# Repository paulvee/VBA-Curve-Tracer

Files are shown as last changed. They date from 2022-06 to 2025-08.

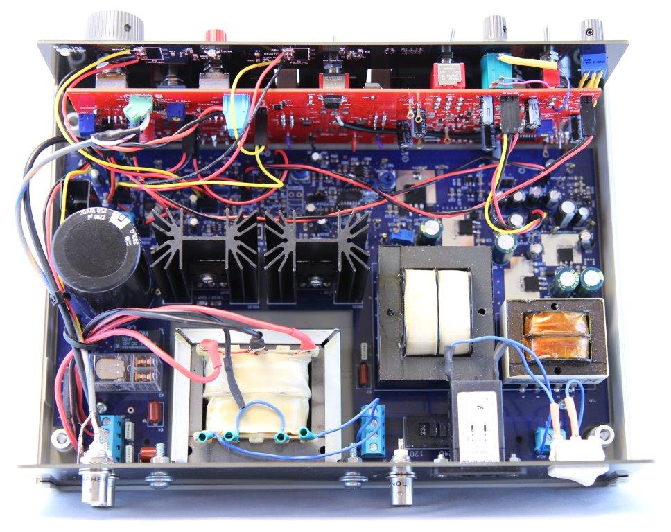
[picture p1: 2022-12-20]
Above from Back.jpg

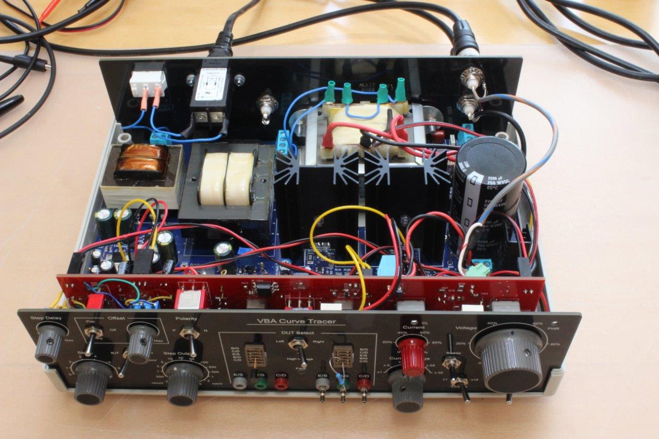
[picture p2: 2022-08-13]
Complete Unit(small).jpg

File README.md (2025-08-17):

# VBA Curve Tracer

Note:
When you order boards, make sure you select the black color for the Face Plate and the Back plate, otherwise you will get the default color and that may be green.
Read the important item below about ordering PCB's.

IMPORTANT:
Read the installation instructions for the Front board and the Main board carefully before installing parts.
 
As some of you may know already, designing something is bliss, manufacturing is hell. Especially after some time because things have a habit of changing.
Keep an eye out to newer revision numbers of the BOM's. I have added the partnumbers other users recommended because we either made a mistake in the ordernumber, or the part is no longer available. These alternatives are listed as suggestions. We cannot keep track of this ourselves but appreciate it if you can point out where there are partnumber issues so others can benefit.

Maker Matt Web and maker Cory Lytle have spend a lot of time correcting BOM partnumber errors and installation instructions. Thank you Matt & Cory!

Based on a suggestion from Cory, we have made a small change to the silkscreen of the Front Panel to make the Y-amplifier gain setting more obvious. This is reflected in file FrontPanelRev2b-Display.png.
It replaces the original one, bit since it's only this small change, I left all the other information intact. When you use the Gerber information, it has the change.

---------------------------------------------------------------------------------------------------

This is a repository to hold all files related to the VBA Curve Tracer project. With this information you can build one yourself.
Note that newer versions of files will overwrite the existing ones, there will be no version control. Look at the upload dates for more information.

---------------------------------------------------------------------------------------------------
Here is a note about issues that may come up when you're ordering boards.
Note that we have not heard about unresolved issues when you order through PCBWay. (look at the shared projects on their site and search for VBA to get access to all four boards)
The response below was a result of questions by the engineers of JLCPCB: (more info can be found in the Comment section of the Blog)

Mark, who was the EDA specialist in our team, designed the schematics and the PCB layouts. He used Altium, because his University has a full license.
He is the sole keeper of the EDA information.

This is what Mark replied to the issue:
I went back to look at the gerber files as they were distributed. At that time I was putting the board outline on every gerber plot. The Keepout layer was used for the cutouts in the inner parts of the board not the board outline or to keep copper out of certain areas of the board which is the intended use of this layer. This never has a use as a gerber file unless you are faking the keepout layer as a board outline layer. There is a keepout layer for the front panel PCB since it has the two rectangular connectors on it for holding the DUTs. Some manufacturers use the keepout layer to indicate internal holes. This is not the intended use of the layer either. I have encountered several different uses of the various gerber layers. You have to decide with the board manufacturer what they want to use as the board outline correctly or incorrectly. At the time when I made 10 systems, PCBWAY was allowing the board outline to be on all layers and not the keepout layer. I have had discussions more recently with PCBWAY. Among other things I got complaints about line thickness used for the lines depicting the board outline. So I decided to use the more industry standard of the .GM board outline gerber file. It uses 0 thickness lines for the board outline. Altium has this built into the design package so it was fairly easy to do. I no longer give a keepout layer unless there are internal "holes" on the PCB and that is how they want it indicated. In the description file I send with every PCB order I tell them exactly what the keepout layer is showing. I don't give it when there are no holes. The GM layer could also show the internal holes but I haven't needed to have any newer PCBs manufactured with them. Unfortunately I also get asked about the keepout layer when it is included on a board where the copper is supposed to be kept out. (This is the correct use of this layer). So no more keepout layer to the board manufacturer. The keepout layer is used by the PCB program to keep copper off a layer in a certain region. The gerber files never need to know this as the copper layer file will not have the copper in those regions already. So after all that verbal diarrhea can you tell me what they really want to indicate what the PCB outlines are. If they insist on using the incorrect keepout layer than I can send you some. If they will use the correct GM layer than I will send you some. The gerber layers JLPCB has, all have board outlines on every gerber layer. If you want to come up with a scheme that works for them, you need to let me know what it is and I will make that layer for you. I assume since the keepout layer was included on the front panel you don't need that one as long as JLPCB knows it isn't a board outline but the outline plus internal cutouts. You can create an issue on this Github site, add it as a comment on the Blog, or send the info directly via email if you prefer that. allie@wisc.edu.

--------------------------------------------------------------------------------------------------
There are four different Blogs that I created for this project.
The original posting with a description of the Theory of Operation for the CT and the building of my first version, a working prototype.

http://www.paulvdiyblogs.net/2017/12/building-curve-tracer.html

A few years later, a PCB layout has been developed using mostly SMD parts by Mark Allie. The Blog that covers the Version 2 can be found here:

http://www.paulvdiyblogs.net/2021/03/building-curve-tracer-v2.html

Some of the development process of the VBA Curve Tracer (Version 3) with the help from Mark Allie and Bud Bennet can be found here:

http://www.paulvdiyblogs.net/2021/03/building-curve-tracer-version-3.html

The information about the final instrument for a DIY build can be found here:

https://www.paulvdiyblogs.net/2022/06/the-vba-curve-tracer.html

I also created a blog post with several measurements that were made with the VBA Curve Tracer.

https://www.paulvdiyblogs.net/2021/11/making-meassurements-with-v3-curve.html

Enjoy!

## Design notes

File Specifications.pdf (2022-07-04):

## VBA Curve Tracer Specifications

DUT Voltages and Currents

There are three main voltage ranges that can be selected.

- 0-35V @ 0-2A
- 0-70V @ 0-1A
- 0-200V @ 0-100mA

The voltages and the currents of any of these ranges can be adjusted from 0-100% of the maximum values with full load. The voltage output can be selected between a triangle-based waveform, which is the default, and DC for leakage measurements. Selecting the DC mode will automatically change the maximum current in the X1 Current range setting to 50% to reduce the thermals.

The frequency of the triangle-based waveform is set at about 160Hz but can be tuned by changing a trimmer inside the unit. It can range from about 140Hz to 650Hz and can be used to tune the rate of flicker on the display of the oscilloscope.

An indicator will warn the user when voltages higher than approx. 40V are present on the DUT output terminals.

There are 6 current ranges to set the maximum currents for the DUT in the three voltage modes:

- x 1 (changes to x0.5 in the DC mode)
- x 0.5
- x 0.2
- x 0.1
- x 0.05
- x 0.02

This means that in the 35V @ 2A range, the maximum current can bet set to 2A, 1A, 400mA, 200mA, 100mA and 40mA. A Current adjustment can be used to further set the maximum current from 0-100% in any of the selected Current Ranges.

An LED will signal the current limiting (CL) mode, i.e. when the current to the DUT meets or is exceeding the set current by the Current Range and the Current setting.

Step Generator

The Step Generator feeds the Base or Gate of the DUT and can be set to output a current for BJT devices or a voltage for FET devices.

The Step Generator output can be set to generate 0-7 steps in a cycle.

A Step Delay can be selected to delay the time between complete step cycles to reduce the thermals developing in the DUT and prevent it from over-heating. When activated, the delay is approx. 40mSec between step cycles and can be increased to more than 250mS. The step cycle delay can be set with step cycles of 1 to 7 steps.

The output of the Step Generator can be selected in a 1-2-5 sequence.

The selections are:

- 5V*) or 5mA
- 2V or 2mA
- 1V or 1mA
- 500mV or 500uA
- 200mV or 200uA
- 100mV or 100uA
- 50mV or 50uA
- 20mV or 20uA
- 10mV or 10uA
- 5mV or 5uA
- 2mV or 1uA
- 1mV or 1uA
- 500uV or 500nA
- 200uV or 200nA
- 100uV or 100nA
- 50uV or 50nA

*) Note that in the 5V range, you will have to reduce the number of steps to avoid clipping against the supply rail of the step amplifier (approx. +/-14V). This can also happen with 1V and 2V step sizes in combination with the offset feature. The current settings do not clip.

A switch on the front panel selects the DUT type, which can be BJT or FET. This switches the output of the step generator to produce either a current for BJT's or volts for FET's.

An offset can be selected with either a positive (aid) or negative (oppose) offset to the Step output. The offset range has a maximum range of +/- 7V for BJT's at 100mA/Step and +/- 2V for FET's regardless of the V/Step setting. The maximum offset range for BJT's lowers with lower mA/Step settings so the user will need to readjust the offset level (Bias) when you change the Base current. In the FET mode, the offset (VGS) and the range stay constant with different V/Step settings. By changing three resistor values, the maximum offset for FET's can be set to +/-3, 4, 5 and 7.5V.

Both the current and the voltage outputs are corrected for DUT junction voltage drops and other current/voltage drops so composite devices (Darlington) can be tested without influencing the Base or Gate step settings.

The Step Gen output is protected against damages by high voltages in case of a shorted/damaged C-B or D-G junction or an accidental shorting of the Base or Gate to the DUT supply, that can be as high as 200V. A Fault LED will warn the user of this condition as long as it is present and the voltage at the Collector/Drain output will be removed for the duration of the fault condition.

A switch determines the polarity of the DUT for PNP/P-channel or NPN/N-channel type devices in such a way that the origin of the I/V curves on the DSO will always start in the lower left-hand corner of the oscilloscope.

Device Under Test (DUT)

A large variation of DUT's can be connected to the Curve Tracer by means of test sockets or 2mm Banana sockets. Two DUT's can be compared by means of a DUT selector switch that can be off or power the left or the right DUT socket to make comparisons and matching of devices possible.

Many different 2 or 3-pin DUT's can be measured or characterized with the instrument.

Display Device

An analog (CRT) or digital oscilloscope (DSO) is used in the X-Y display mode to show the I/V curves of the DUT. There are two BNC sockets available on the back panel of the instrument to connect the X and Y outputs to the input channels of the scope. An optional Z or blanking signal can be made available through a BNC connector on the back panel for analog oscilloscopes.

A multiplier for the measured DUT current can be used to select between x1 and x10 to amplify small DUT currents on the scope and raise the signal above noise levels.

Enclosure, Electrical & Mechanical Information

A mains switch is available on the back of the unit. An indicator on the Face Plate will show that the instrument is powered on.

The overall current consumption of the instrument in the idle mode is 0,25A and 12.5W with a 230V main supply. With the maximum DUT load of 35V @ 2A, the consumption is 340mA and 53W.

The instrument can be used with 115V @ 60Hz or 220-240V @ 50Hz mains voltages by means of a selector switch inside the unit. The mains connection is through an IEC C-7 type connector (also known as a figure 8) with EMI filter, has a fuse and a main power switch on the back panel. The instrument circuits itself are floating from earth ground but will be earth grounded through the BNC connections to the earth grounded oscilloscope.

The plastic enclosure measures 25cm x 18cm x 8cm. The Front and Back panels are shielded printed circuit boards with a black background and white lettering.

The overall weight is 2.5Kg.

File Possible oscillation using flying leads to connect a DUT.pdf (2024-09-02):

## Possible oscillation using flying leads to connect a DUT

Maker Matt Webb noticed oscillations of the triangle waveform during the current limiting phase when using flying leads in combination with the 2mm banana jacks.

It turns out that although the Curve Tracer itself is inherently clean from oscillation, adding flying leads will add induction and that can cause issues, especially with higher currents during the current limiting phase.

The remedy is to use leads that are as short as possible, and/or shielded.

The oscillation can also be countered by adding a donut shaped ferrite bead on the Collector/Drain connection lead. The ferrite beads that Matt experimented with is listed in the OffPCBPartsBOM.

Here are some pictures that Matt made with a TO3 2N3055 power transistor to illustrate the problem.

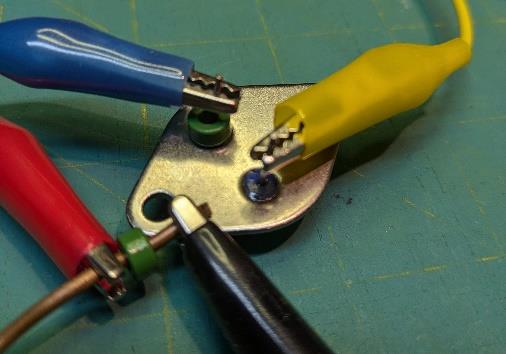
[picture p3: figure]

The leads he used for this measurement have a length of 13cm (5inch).

Without any additional beads, the triangle waveform looked as follows:

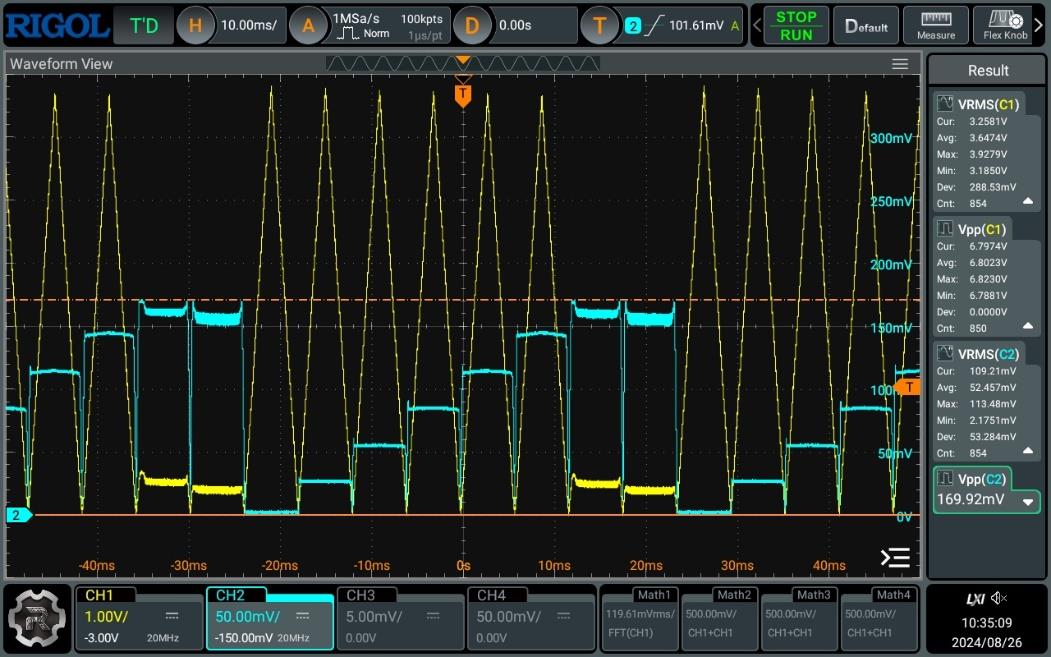
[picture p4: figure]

Note that there is some hash on the current limited excursions of the Collector current in the two highest steps.

With one additional bead placed directly on the Collector connection, the hash goes away.

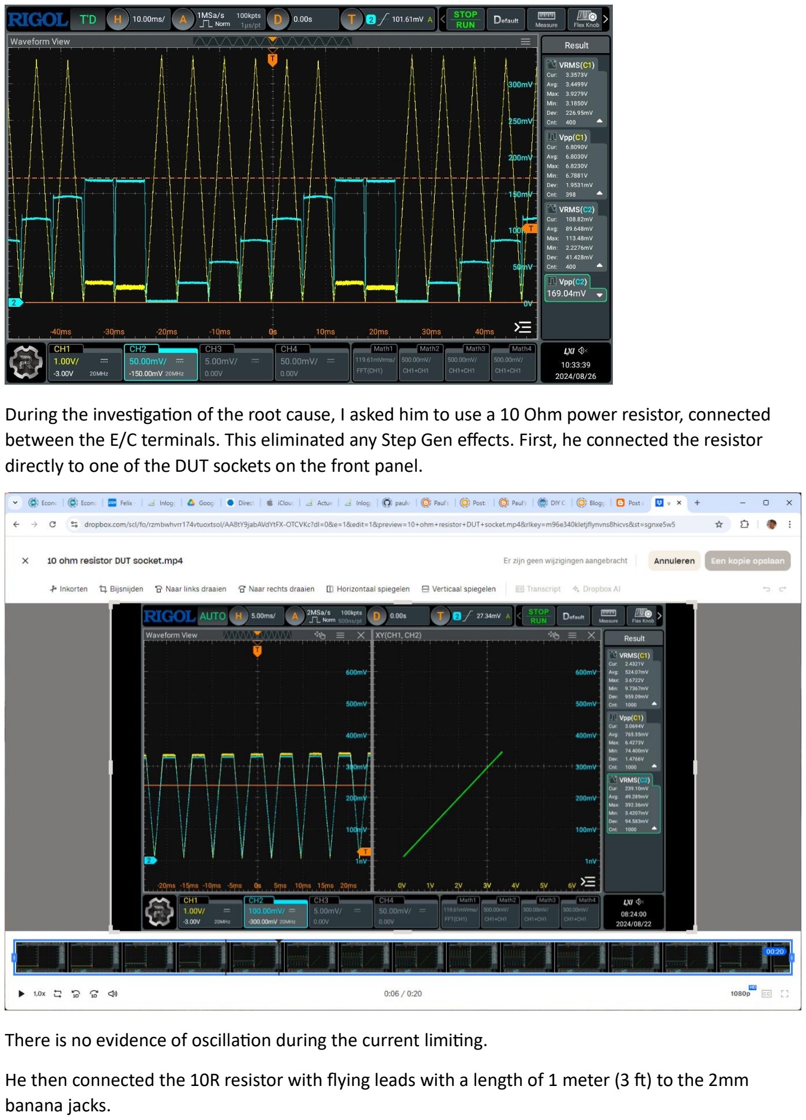
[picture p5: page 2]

During the investigation of the root cause, I asked him to use a 10 Ohm power resistor, connected between the E/C terminals. This eliminated any Step Gen effects. First, he connected the resistor directly to one of the DUT sockets on the front panel.

There is no evidence of oscillation during the current limiting.

He then connected the 10R resistor with flying leads with a length of 1 meter (3 ft) to the 2mm banana jacks.

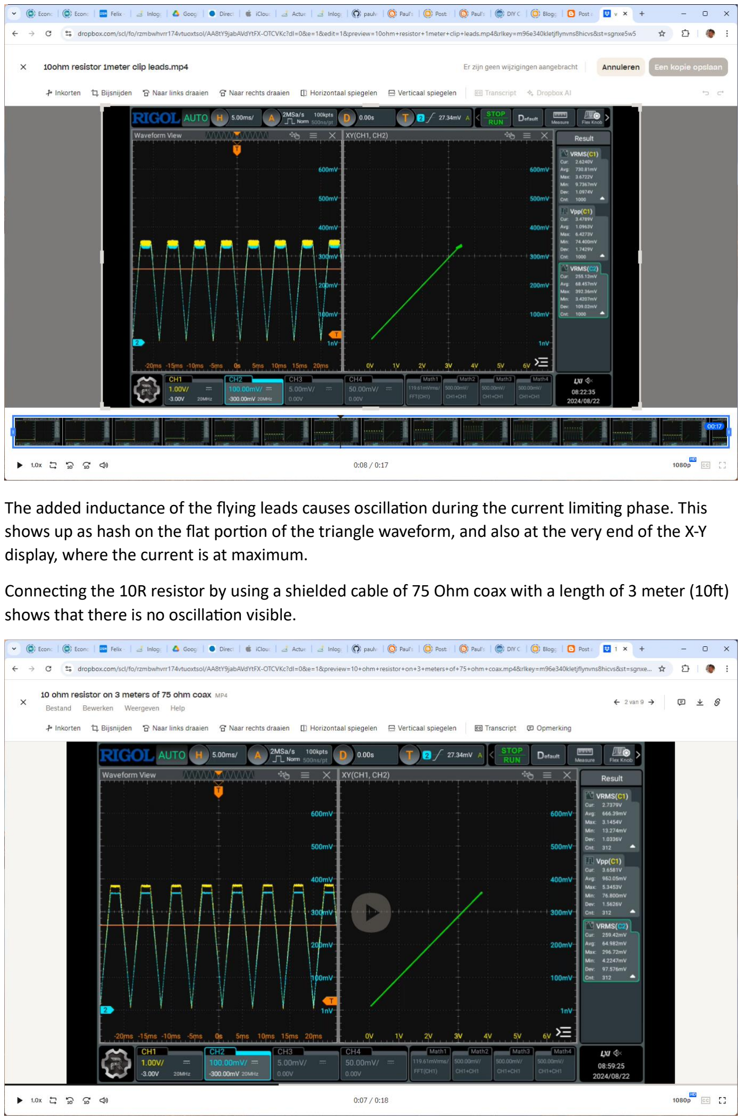
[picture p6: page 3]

The added inductance of the flying leads causes oscillation during the current limiting phase. This shows up as hash on the flat portion of the triangle waveform, and also at the very end of the X-Y display, where the current is at maximum.

Connecting the 10R resistor by using a shielded cable of 75 Ohm coax with a length of 3 meter (10ft) shows that there is no oscillation visible.

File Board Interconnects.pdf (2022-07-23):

### VBA Curve Tracer Board Interconnects

1. P1-1 on the Front panel goes to J106-1 on the Main board. Signal HVon
2. P1-2 on the Front panel goes to J106-2 on the Main board. Signal PlusTri(+)
3. P1-3 on the Front panel goes to J120-1 on the Front board. Signal FaultOn
4. P2-1 on the Front panel goes to J103-3 on the Main board. Signal minusTri(-)
5. P2-2 on the Front panel goes to J103-2 on the Main board. Signal GND(G)
6. P2-3 on the Front panel goes to J103-1 on the Main board. Signal ILon
7. J104-1 on the Front board goes to J4-1 on the Main board. Signal Select 70V
8. J104-2 on the Front board goes to J4-2 on the Main board. Signal Select 35V
9. J104-3 on the Front board goes to J4-3 on the Main board. Signal plusTri
10. J104-4 on the Front board goes to J4-4 on the Main board. Signal Select 200V
11. J102-1 on the Front board goes to J102-1 on the Main board. Signal CCW
12. J102-2 Front board and J102-2 on the Main board do not need to be connected.
13. J100-1 on the Front board goes to J105-1 on the Main board. Signal TAP
14. J100-2 on the Front board goes to J105-2 on the Main board. Signal 7V5
15. J101-1 on the Front board goes to J54-1 on the Main board. Signal Sw(eep)
16. J101-2 on the Front board goes to J54-2 on the Main board. Signal Ch(oice)
17. J2-1 on the Front board goes to J55-1 on the Main board. Signal ISO
18. J2-2 on the Front board goes to J55-2 on the Main board. Signal Pulse
19. J74-1 on the Front board goes to J40-1 on the Main board. Signal +
20. J74-2 on the Front board goes to J40-2 on the Main board. Signal -
21. J1-1 on the Front board goes to J30-1 on the Main board. Signal -
22. J1-2 on the Front board goes to J30-2 on the Main board. Signal ISO
23. J1-3 on the Front board goes to J30-3 on the Main board. Signal +
24. J120-1 on the Front board goes to P1-3 on the Face plate. Signal FaultOn
25. J120-2 on the Front board goes to J106-3 on the Main board. Signal FaultOn
26. J70-1 on the Front board goes to J6-1 on the Main board. Signal CS- (>2 Amp!)
27. J70-2 on the Front board goes to J6-2 on the Main board. Signal GND (>2 Amp!)
28. J72 on the Front board goes to the Y BNC on the Back panel with a shielded cable.
29. J71 on the Front board goes to the X BNC on the Back panel with a shielded cable.
30. J51 on the Main board goes to the Z BNC on the Back panel with a shielded cable.
31. On the Front board, a shielded cable goes from S22-C pin 8 marked B/G (only center lead) to S71A pin 2 marked B/G (the center lead) and the braided isolation to the hole just below it, marked ISO.

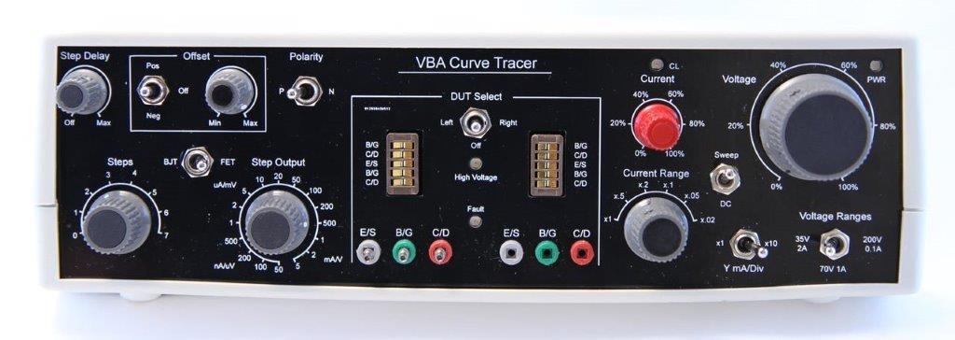
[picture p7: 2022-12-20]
Front Closed.jpg

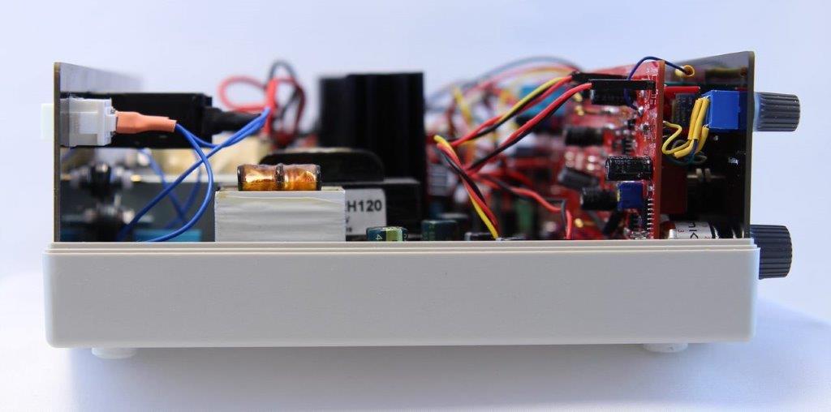
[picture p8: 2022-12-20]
L-Side.jpg

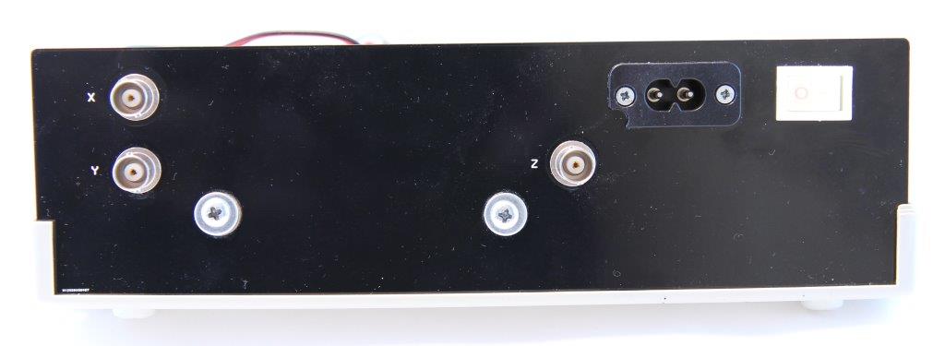
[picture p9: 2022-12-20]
Back.jpg

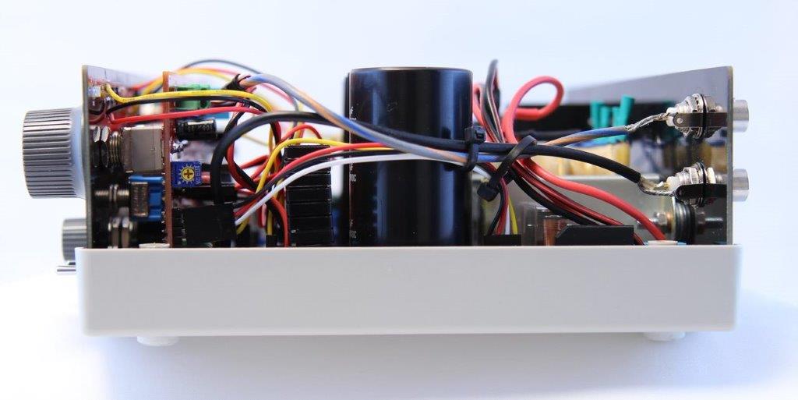
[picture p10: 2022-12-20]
R-Side.jpg

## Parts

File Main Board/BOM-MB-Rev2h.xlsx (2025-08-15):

 |  |  | Main Board Rev 2b
 | Red on Bottom |  |  |  |  |  | Surface Mount |  |  |  |  | Suggested by users - not verified
Quantity | Qty/Side | Designator | Description | Cap | Value | Res | Footprint | Manufacturer | Manufacturer Part Number | Supplier | Supplier Part Number | Alternative
3 | 0,3 | C7, C28, C106 | CAP CER 0.1UF 250V X7R 1206 | 100nF | 0.1uF |  | CAPC3216M | KEMET | C1206C104KARECAUTO | Digi-Key | 399-17175-1-ND
32 | 13,19 | C9, C12, C14, C15, C18, C20, C22, C26, C27, C32, C34, C36, C38, C42, C50, C54, C60, C64, C66, C90, C108, C112, C114, C116, C118, C120, C124, C126, C128, C130, C132, C134 | CAP CER 1UF 50V X7R 0805 | 1uF | 1uF |  | CAPC2012M | Samsung | CL21B105KBFNNNE | Digi-Key | 1276-1029-1-ND
21 | 7,14 | C13, C21, C33, C37, C41, C47, C51, C52, C59, C63, C65, C105, C113, C115, C117, C119, C123, C125, C127, C129, C133 | CAP CER 10NF 100V X7R 0805 | 10nF | 10nF |  | CAPC2012M | Samsung | CL21B103KCANNNC | Digi-Key | 1276-1249-1-ND
2 | 0,2 | C16, C25 | CAP PEN 10NF 100V 5% 1206 | 10nF | 10nF |  | CAPC3216M | Kyocera AVX | CB017E0103JBA | Digi-Key | 478-13090-1-ND
2 | 0,2 | C23, C24 | CAP FILM 0.18UF 5% 50VDC 1812 | 0.18uF | 0.18uF |  | CAPC4532M | KEMET | LDECC3180JA5N00 | Digi-Key | 399-18519-1-ND
1 | 1,0 | C43 | CAP CER 0.1UF 50V X7R 0805 | 100nF | 0.1uF |  | CAPC2012M | KEMET | C0805C104M5RACTU | Digi-Key | 399-C0805C104M5RAC7800CT-ND
1 | 1,0 | C53 | CAP FILM 10NF PPS16V | 10nF | 10nF |  | CAPC2012M | Panasonic | ECHU1C103JX5 | Digi-Key | PCF1196CT-ND
3 | 3,0 | C55, C57, C58 | CAP CER 330PF 50V COG 0805 | 330pF | 330pF |  | CAPC2012M | KEMET | C0805C331K5GACTU | Digi-Key | 399-8065-1-ND
1 | 1,0 | C56 | CAP CER 10NF 50V NP0 0805 | 10nF | 10nF |  | CAPC2012M | KEMET | C0805C103J5GACTU | Digi-Key | 399-7992-1-ND
1 | 1,0 | C104 | CAP CER 330PF 500V COG 1206 | 330pF | 330pF |  | CAPC3216M | Yageo | CC1206KRNPOBBN331 | Digi-Key | 311-4477-1-ND
1 | 1,0 | C107 | CAP CER 100PF 50V COG 0805 | 100pF | 100pF |  | CAPC2012M | KEMET | C0805C101J5GACTU | Digi-Key | 399-1122-1-ND
1 | 1,0 | C109 | CAP CER 47PF 250V C0G/NP0 0805 | 47pF | 47pF |  | CAPC2012M | KEMET | C0805C470JAGAC7800 | Digi-Key | 399-15051-1-ND
14 | 5,9 | D1, D2, D3, D5, D10, D11, D12, D13, D14, D15, D30, D31, D32, D33 | DIODE SWITCHING 400V 1A DO-214AC | 12pF | S1G |  | SMA-D | Fairchild | S1G | Digi-Key | S1GFSCT-ND
2 | 1,1 | D16, D40 | DIODE SI 85V 0.16mA SOT-23-3, Rectifier Diode Switching 85V 0.16A 3000ns Automotive 3-Pin SOT-23 T/R |  | BAV199 |  | SOT23-3M | Nexperia | BAV199,215 | Digi-Key | 1727-2909-1-ND
5 | 4,1 | D50, D51, D52, D90, D91 | DIODE SCHOTTKY 30V 200mA SOD-123 |  | BAT54 |  | SOD123 | ON Semiconductor | SBAT54T1G | Digi-Key | 50AC7280 | SBAT54T1G
3 | 3,0 | D102, D103, D105 | DIODE GP 75V 150MA SOD123FL |  | 1N4148 |  | SOD123 | Vishay Semiconductors | 1N4148WFL-G3-08 | Digi-Key | 1N4148WFL-G3-08GICT-ND | 1N4148WXTPMSCT-ND
2 | 2,0 | D104, D106 | DIODE ARRAY SCHOTTKY 30V SOT23-3 | 10pF | BAT54S |  | SOT23-3M | Fairchild | BAT54S | Digi-Key | BAT54SFSCT-ND | BAT54SLT1GOSCT-ND
3 | 3,0 | Q40, Q90, Q114 | TRANS NPN 40V 0.2A SOT23 |  | 2N3904 |  | SOT23-3M | ON Semiconductor | MMBT3904LT1G | Digi-Key | MMBT3904LT1GOSCT-ND
2 | 2,0 | Q103, Q113 | Dual Matched Pair PNP SOT363-6M |  | BCM857DS |  | SC-74 | NXP Semiconductors | BCM857DS,135 | Digi-Key | 1727-5460-1-ND
5 | 5,0 | Q106, Q108, Q109, Q111, Q112 | N-CH 25V 1.25 W Power Mosfet SOT-23 |  | IRFML8244 |  | SOT23-3M | International Rectifier | IRFML8244TRPBF | Digi-Key | IRFML8244TRPBFCT-ND
2 | 2,0 | Q107, Q115 | Dual Matched Pair NPN SOT363-6M |  | BCM847DS |  | SC-74 | NXP Semiconductors | BCM847DS,135 | Digi-Key | 1727-5458-1-ND
1 | 1,0 | Q110 | TRANS PNP 40V 0.2A SOT23 |  | 2N3906 |  | SOT23-3M | ON Semiconductor | MMBT3906LT1G | Digi-Key | MMBT3906LT1GOSCT-ND
1 | 0,1 | R1 | RES 1.33K OHM 1% 1W 2512 |  | 1.33K | 1.33kR | RESC6432BM | Stackpole Electronics | RMCF2512FT1K33 | Digi-Key | RMCF2512FT1K33CT-ND
2 | 2,0 | R2, R6 | RES 301K OHM 1% 1/4W 0805 |  | 301K | 301kR | RESC0805M | Stackpole Electronics | RMCF0805FT301K | Digi-Key | RMCF0805FT301KCT-ND
6 | 0,6 | R2a, R2b, R2c, R2d, R2e, R2f | RES 2.7K OHM 5% 3W 2512 |  | 2.7K | 2.7kR | RESC6432M | TE Connectivity CGS | 35222K7JT | Digi-Key | A121210CT-ND
2 | 2,0 | R3, R7 | RES 33.2K OHM 1% 1/4W 1206 |  | 33.2K |  | RESC3216M | Stackpole Electronics | RMCF1206FT33K2 | Digi-Key | RMCF1206FT33K2CT-ND
4 | 0,4 | R4, R5, R13, R16 | RES 100 OHM 1% 1W 2512 |  | 100 | 100R | RESC6432BM | Stackpole Electronics | RMCF2512FT100R | Digi-Key | RMCF2512FT100RCT-ND
1 | 1,0 | R8 | RES 7.5K OHM 1% 1/4W 0805 |  | 7.5K | 7.5kR | RESC2012M | KOA Speer | RK73H2ATTD7501F | Digi-Key | 2019-RK73H2ATTD7501FCT-ND
1 | 1,0 | R10 | RES 127 Ohm 1% 1/4W 0805 |  | 127 | 127R | RESC2012M | KOA Speer | RK73H2ATTD1270F | Digi-Key | 2019-RK73H2ATTD1270FCT-ND
2 | 2,0 | R11, R15 | RES 887 Ohm 1% 1/4W 0805 |  | 887 | 887R | RESC2012M | KOA Speer | RK73H2ATTD8870F | Digi-Key | 2019-RK73H2ATTD8870FCT-ND
4 | 4,0 | R12, R63, R126, R153 | RES 100 OHM 1% 1/4W 0805 |  | 100 | 100R | RESC2012M | KOA Speer | RK73H2ATTD1000F | Digi-Key | 2019-RK73H2ATTD1000FCT-ND
1 | 1,0 | R14 | RES 178 Ohm 1% 1/4W 0805 |  | 178 | 178R | RESC2012M | KOA Speer | RK73H2ATTD1780F | Digi-Key | 2019-RK73H2ATTD1780FCT-ND
3 | 3,0 | R40, R41, R146 | RES 20K OHM 1% 1/4W 0805 |  | 20K | 20kR | RESC2012M | KOA Speer | RK73H2ATTD2002F | Digi-Key | 2019-RK73H2ATTD2002FCT-ND
1 | 1,0 | R42 | RES 2.21K OHM 1% 1/4W 0805 |  | 2.21K | 2.21kR | RESC2012M | KOA Speer | RK73H2ATTD2211F | Digi-Key | 2019-RK73H2ATTD2211FCT-ND
6 | 4,2 | R50, R58, R61, R62, R115, R116 | RES 1K OHM 1% 1/4W 0805 |  | 1K | 1kR | RESC2012M | KOA Speer | RK73H2ATTD1001F | Digi-Key | 2019-RK73H2ATTD1001FCT-ND
1 | 1,0 | R51 | RES 1.5K OHM 1% 1/4W 0805 |  | 1.5K | 1.5kR | RESC2012M | KOA Speer | RK73H2ATTD1501F | Digi-Key | 2019-RK73H2ATTD1501FCT-ND
1 | 1,0 | R52 | RES 13K OHM 1% 1/4W 0805 |  | 13K | 13kR | RESC2012M | KOA Speer | RK73H2ATTD1302F | Digi-Key | 2019-RK73H2ATTD1302FCT-ND
9 | 8,1 | R53, R56, R57, R59, R60, R124, R138, R143, R144 | RES 100K OHM 1% 1/4W 0805 |  | 100K | 100kR | RESC2012M | KOA Speer | RK73H2ATTD1003F | Digi-Key | 2019-RK73H2ATTD1003FCT-ND
1 | 1,0 | R54 | RES 205K OHM 1% 1/4W 0805 |  | 205K | 205kR | RESC2012M | KOA Speer | RK73H2ATTD2053F | Digi-Key | 2019-RK73H2ATTD2053FCT-ND
1 | 1,0 | R55 | RES 49.9K OHM 1% 1/4W 0805 |  | 49.9K | 49.9kR | RESC2012M | KOA Speer | RK73H2ATTD4992F | Digi-Key | 2019-RK73H2ATTD4992FCT-ND
1 | 1,0 | R91 | RES 750 OHM 1% 1/4W 1206 |  | 750 | 750R | RESC3216M | Stackpole Electronics | RMCF1206FT750R | Digi-Key | RMCF1206FT750RCT-ND
1 | 1,0 | R93 | RES 6.81KK OHM 1% 1/4W 0805 |  | 6.81K | 6.81kR | RESC2012M | KOA Speer | RK73H2ATTD6811F | Digi-Key | 2019-RK73H2ATTD6811FCT-ND
1 | 1,0 | R94 | RES 10 OHM 1% 1/4W 1206 |  | 10 | 10R | RESC3216M | Stackpole Electronics | RMCF1206FT10R0 | Digi-Key | RMCF1206FT10R0CT-ND
1 | 1,0 | R103 | RES 100 OHM 1% 1/4W 1206 |  | 100 | 100R | RESC3216M | Stackpole Electronics | RMCF1206FT100R | Digi-Key | RMCF1206FT100RCT-ND
2 | 2,0 | R105, R106 | RES 200 OHM 1% 1/4W 0805 |  | 200 | 200R | RESC2012M | KOA Speer | RK73H2ATTD2000F | Digi-Key | 2019-RK73H2ATTD2000FCT-ND
1 | 1,0 | R108 | RES 1M OHM 1% 1/4W 0805 |  | 1M | 1MR | RESC2012M | KOA Speer | RK73H2ATTD1004F | Digi-Key | 2019-RK73H2ATTD1004FCT-ND
1 | 1,0 | R109 | RES 221 OHM 1% 1/4W 1206 |  | 221 | 221R | RESC3216M | Stackpole Electronics | RMCF1206FT221R | Digi-Key | RMCF1206FT221RCT-ND
3 | 3,0 | R111, R127, R142 | RES 49.9 OHM 1% 1/4W 0805 |  | 49.9 | 49.9R | RESC2012M | KOA Speer | RK73H2ATTD49R9F | Digi-Key | 2019-RK73H2ATTD49R9FCT-ND
1 | 1,0 | R112 | RES 3.48K OHM 1% 1/4W 1206 |  | 3.48K | 3.48kR | RESC3216M | Stackpole Electronics | RMCF1206FT3K48 | Digi-Key | RMCF1206FT3K48CT-ND | Note that this value is determined by the real value of the 100K voltage setting potmeter due to the +/-10% tolerance.
1 | 1,0 | R113 | RES 162 OHM 1% 1/4W 1206 |  | 162 | 162R | RESC3216M | Stackpole Electronics | RMCF1206FT162R | Digi-Key | RMCF1206FT162RCT-ND
1 | 1,0 | R114 | RES 2K OHM 1% 1/4W 0805 |  | 2K | 2kR | RESC2012M | KOA Speer | RK73H2ATTD2001F | Digi-Key | 2019-RK73H2ATTD2001FCT-ND
2 | 2,0 | R117, R120 | RES 0R5 OHM 1% 2W 2512 |  | 0R5 | 500mR | RESC6432M | Stackpole Electronics | CSRN2512FKR500 | Digi-Key | CSRN2512FKR500CT-ND
1 | 1,0 | R118 | RES 1.5K OHM 5% 3W 2512 |  | 1.5K | 1.5kR | RESC6432BM | TE Connectivity CGS | 35221K5JT | Digi-Key | A121168CT-ND
5 | 5,0 | R122, R136, R137, R140, R141 | RES 499 OHM 1% 1/4W 0805 |  | 499 | 499R | RESC2012M | KOA Speer | RK73H2ATTD4990F | Digi-Key | 2019-RK73H2ATTD4990FCT-ND
3 | 3,0 | R123, R134, R135 | RES 10K OHM 1% 1/4W 0805 |  | 10K | 10kR | RESC2012M | KOA Speer | RK73H2ATTD1002F | Digi-Key | 2019-RK73H2ATTD1002FCT-ND
1 | 1,0 | R125 | RES 105 OHM 1% 1/4W 1206 |  | 105 | 105R | RESC3216M | Stackpole Electronics | RMCF1206FT105R | Digi-Key | RMCF1206FT105RCT-ND
1 | 0,1 | R128 | RES 10 OHM 1% 3.5W 2512 |  | 10R0 | 10r0 | RESC6432BM | Stackpole Electronics | CSRT2512FT10R0-UP | Digi-Key | 738-CSRT2512FT10R0-UPCT-ND
2 | 2,0 | R130, R131 | RES 2.21 Ohm 1% 1W 2512 |  | 2R21 | 2.21R | RESC6432BM | KOA Speer | RK73H3ATTE2R21F | Digi-Key | 2019-RK73H3ATTE2R21FCT-ND
2 | 2,0 | R132, R133 | RES 2R0 OHM 1% 2W 2512 |  | 2R0 | 2R | RESC6432BM | Yageo | RC2512FK-7W2RL | Digi-Key | 13-RC2512FK-7W2RLCT-ND
1 | 1,0 | U10 | IC REG LDO ADJ 1.5A D2PAK |  | LM317 |  | D2PAK | Texas Instruments | LM317D2T-TR | Digi-Key | 497-1571-1-ND
1 | 1,0 | U11 | LDO Regulator, 500 mA, 5 V, Negative 4%; TJ = -40°C to +125°C |  | LM7905 |  | DPAK-M | ON Semiconductor | MC79M05BDTG | Digi-Key | MC79M05BDTGOS-ND
1 | 1,0 | U12 | Linear Voltage Regulator IC Positive Adjustable 1 Output 1.2 V ~ 32 V 100mA SOT-89-3 |  | LM317 |  | SOT89M | Texas Instruments | LM317LIPK | Digi-Key | 296-21742-1-ND
1 | 1,0 | U30 | 15V POS 0.5A V REG |  | 78M15 |  | DPAK-M | ON Semiconductor | MC78M15CDTRKG | Digi-Key | MC78M15CDTRKGOSCT-ND
1 | 1,0 | U31 | IC REG LINEAR -15V 500MA DPAK |  | 79M15 |  | DPAK-M | ON Semiconductor | MC79M15CDTRKG | Digi-Key | MC79M15CDTRKGOSCT-ND
1 | 1,0 | U40 | V-Ref Adjustable 2.5V to 20V 100mA Automotive 3-Pin SOT-23F T/R |  | TL431 |  | SOT23-3M | Texas Instruments | LM431BCM3/NOPB | Digi-Key | LM431BCM3/NOPBCT-ND
1 | 1,0 | U50 | IC OSC SINGLE TIMER 3MHZ 8-SOIC |  | LMC555 |  | SOIC127P600X168_HS-8N | Texas Instruments | LMC555CMX/NOPB | Digi-Key | LMC555CMX/NOPBCT-ND
1 | 1,0 | U51 | Quad NAND w/Schmitt trigger |  | HCF4093 |  | SOIC127P600X14-M | STMicroelectronics | HCF4093YM013TR | Digi-Key | 497-14376-1-ND
3 | 3,0 | U52, U100, U101 | IC OPAMP JFET 1 CIRCUIT SOT23-5 |  | TL071 |  | SOT95P300X130-5M | Texas Instruments | TL071HIDBVR | Digi-Key | 296-TL071HIDBVRCT-ND
1 | 1,0 | U53 | OPTOISO 5KV TRANS W/BASE 6SMD |  | CNY17-1S |  | SOIC254P1000X6 | Vishay Lite-On | CNY17-1S | Digi-Key | 160-1309-5-ND
 |  |  |  |  |  |  | Through Hole
3 | 3 | C1, C3, C8 | CAP PET 10nF 160 VAC 250 VDC 5% | 10nF | 10nF |  | RAD/L7.3/W2.5/LS5.0/D0.575 | Kemet Arcotronics | R82IC2100DQ50J | Digi-Key | 399-19339-1-ND
1 | 1 | C2 | CAP METALLIZED POLYESTER 0.1UF 250V | 100nF | 0.1uF |  | RAD/10.5/W6.5/LS7.5/D0.7 | Panasonic | ECQ-E2104KF | Digi-Key | EF2104-ND
2 | 2 | C4, C5 | CAP METALLIZED POLYESTER 0.15UF 250V | 150nF | 0.15uF |  | RAD/10.5/W6.5/LS7.5/D0.7 | CDE Illinois Capacitor | 154MMR250K | Digi-Key | 1572-1198-ND
0 | 0 | C6 | CAP ALUM 2200UF 20% 250V SNAP | 2.2mF | 2200uF |  | CAPR10-35X40 | Cornell Dubilier | 380LQ222M250A062 | Digi-Key | 338-3520-ND
1 | 1 | C6 alternative | CAP ALUM 1500UF 20% 250V SNAP |  | 1500uF |  | CAPR10-35X41 | Cornell Dubilier | 380LQ152M250A052 | Digi-Key | 338-2245-ND
6 | 6 | C10, C17, C30, C35, C44, C45 | CAP ALUM 100UF 20% 35V THRU HOLE | 100uF | 100uF |  | CAPPR2.5-6.3X10 | Rubycon | 35YXJ100M6.3X11 | Digi-Key | 1189-2260-ND
4 | 4 | C11, C19, C31, C39 | CAP ALUM 470UF 20% 35V RADIAL | 470uF | 470uF |  | CAPPR5-10x12.5-STEP | Rubycon | 35ZL470MEFC10X20 | Digi-Key | 35ZL470MEFC10X20-ND | 1189-4073-ND
2 | 2 | C40, C46 | CAP ALUM 100UF 63V 20% | 100uF | 100uF |  | CAPPR3.5-8X12-0.7d | KEMET | ESL107M063AG8AA | Digi-Key | 399-15743-ND
1 | 1 | C48 | CAP ALUM 22UF 63V 20% | 22uF | 22uF |  | CAPPR2-5x11 | Rubycon | 63PK22MEFC5X11 | Digi-Key | 63PK22MEFC5X11-ND
7 | 7 | C61, C67, C91, C111, C121, C131, C135 | CAP ALUM 100uF 25V 20% | 100uF | 100uF |  | CAPPR2-5x11.5 | Rubycon | 25YXJ100M5X11 | Digi-Key | 1189-2237-ND
1 | 1 | D4 | RECT BRIDGE GPP 400V 8A SIP |  | KBU8G |  | KBU | ON Semiconductor / Fairchild | KBU8G | Digi-Key | KBU8GFS-ND | 1242-1319-ND
1 | 1 | F1 | 5X20 PC TH Fuse Holder |  | 1A |  | 5X20 | Keystone Electronics | 4527 | Digi-Key | 36-4527-ND
1 | 1 | HS90 | TO-220 Vertical Heatsink 0.5X0.5X2.5 in |  | HSS-B20-061H |  | 262-75ABE-01 | CUI Devices | HSS-B20-061H | Digi-Key | 102-4167-ND
2 | 2 | HS100, HS101 | Heat Sinks HTSNK TO-220 218 247 BLK ANODIZED |  | FA-T220-64E |  | FA-T220 | Ohmite | FA-T220-64E | Digi-Key | FA-T220-64E-ND | No longer avaiable
2 | 2 | HS100, HS102 | HEATSINK TO-218 10W H=2.5" BLK |  | 530001B02500G |  | 530001B02500G | Boyd Laconia LLC | 530001B02500G | Digi-Key | HS385-ND | Direct replacement with the hole to mount the MOSFET in the right position
2 | 2 | HS100, HS103 | HEATSINK TO-220 POWER W/PINS BK |  | 530002B02500G |  | 530002B02500G | Boyd Laconia LLC | 530002B02500G | Digi-Key | HS380-ND | This heatsink is cheaper and will fit the board, but you need to drill a hole to fit the MOSFET
2 | 2 | J1, J2 | Wire 2 Board 4Pos 0.2in LS |  | TB004-508-04BE |  | PHOENIX4X0.2 | CUI | TB004-508-04BE | Digi-Key | 102-6181-ND
2 | 2 | J3, J6 | Wire 2 Board 2Pos 0.2in LS, 2~24 Poles, Screw Type, Horizontal, 5.08 Pitch, 24~12 (AWG), Terminal Block Connector |  | TB004-508-02BE |  | PHOENIX2X0.2 | CUI, CUI Devices | TB004-508-02BE | Digi-Key | 102-6179-ND
1 | 1 | J4 | 2.54mm 4pin |  | 640456-4 |  | DTA-100-4 | TE Connectivity | 640456-4 | Digi-Key | A1922-ND
3 | 3 | J30, J103, J106 | 2.54mm 3 pin |  | 640456-3 |  | DTA-100-3 | TE Connectivity | 640456-3 | Digi-Key | A19470-ND
5 | 5 | J40, J54, J55, J102, J105 | 2.54mm 2pin |  | 640456-2 |  | DTA-100-2 | TE Connectivity | 640456-2 | Digi-Key | A1921-ND
1 | 1 | J50 | HEADER VERT 3 POS 0.1LS |  | PH1-03-UA |  | HDR1X3 | CUI | PH1-03-UA | Digi-Key | 2057-PH1-03-UA-ND
1 | 1 | J51 | Conn PC Terminal Block 2 POS 3.5mm Solder Thru-Hole 17.5A |  | 1988956 |  | 1988956, DTA-100-2 | Phoenix Contact | 1988956 | Digi-Key | 277-1779-ND
2 | 2 | J52, J53 | HEADER VERT 2 POS 0.1LS |  | PH1-02-UA |  | 2X1H0.1LS0.9MMHole | Adam Teck | PH1-02-UA | Digi-Key | 2057-PH1-02-UA-ND
1 | 1 | K1 | RELAY, SIGNAL, DPDT, 250VAC, 220VDC, 3A |  | V23105 |  | TE-D2N | TE Connectivity | V23105A5006A201 | Digi-Key | PB1077-ND
1 | 1 | K2 | RELAY GEN PURPOSE DPDT 5A 12V |  | G2R-2-DC12 |  | 2FORMC-OM | Omron | G2R-2-DC12 | Digi-Key | Z2869-ND
1 | 1 | Pot10 | TRIMMER 100 OHM 0.2W TH |  | 100 | 100R | 3306P-CCW | Bourns | 3306P-1-101 | Digi-Key | 3306P-101-ND
1 | 1 | Pot51 | TRIMMER 10K OHM 0.2W TH |  | 10K | 10kR | 3306P-CCW | Bourns | 3306P-1-103 | Digi-Key | 3306P-103-ND
1 | 1 | Pot52 | TRIMMER 200K OHM 0.2W TH |  | 200K | 200kR | 3306P-CCW | Bourns | 3306P-1-204 | Digi-Key | 3306P-204-ND
1 | 1 | Pot53 | TRIMMER 100K OHM 0.2W TH |  | 100K | 100kR | 3306P-CCW | Bourns | 3306P-1-104 | Digi-Key | 3306P-104-ND
2 | 2 | Pot100, Pot102 | TRIMMER 50 OHM 0.5W TH |  | 50R | 50R | 7MMSq-CCW | Nidec Copal | CT-6EP500 | Digi-Key | CT6EP500-ND
1 | 1 | Pot101 | TRIMMER 500 OHM 0.5W TH |  | 500R | 500R | 7MMSq-CCW | Nidec Copal | CT-6EP501 | Digi-Key | CT6EP501-ND
1 | 1 | Pot103 | TRIMMER 2K OHM 0.2W TH |  | 2K | 2kR | 3306P-CCW | Bourns | 3306P-1-202 | Digi-Key | 3306P-202-ND
1 | 1 | Q91 | TRANS PNP 350V 4A TO220 |  | MJE15035 |  | TO220AB-123 | ON Semiconductor | MJE15035GOS | Digi-Key | MJE15035GOS-ND | Because the heatsink is level with the bottom of the transistor case, the heatsink will not sit flush on the main board. Instead it floats several mm above.
2 | 2 | Q104, Q105 | N-Channel Power MOSFET |  | STW9N80K5 |  | TO-247 | STMicroelectronics | STW9N80K5 | Digi-Key | 497-19234-ND
0 | 0 | Q104, Q105 alternative | N-Channel Power MOSFET |  | STW6N90K5 |  | TO-248 | STMicroelectronics | STW6N90K5 | Digi-Key | 497-17077-ND
1 | 1 | SW1 | DPDT Switch |  | CKC5115 |  | S202121MS02Q | ITT C&K | S202121MS02Q | Digi-Key | CKC5115-ND
1 | 1 | T1 | Transformer 20VA 115/230VAC Primary 60/120VAC 0.32/0.16A Secondary |  | 162H120 |  | 162-20W | Hammond Manufacturing | 162H120 | Digi-Key | HM4265-ND
1 | 1 | T10 | POWER XFMR 28 Vct @ 200 mA UL/cUL - Class 2/3, TUV, 115/230V SPLIT PACK PCB MOUNT / FS28-200-C2 |  | FS28-200-C2 |  | TRIAD-6W | Triad Magnetics | FS28-200-C2 | Digi-Key | 237-1501-5-ND
26 | 26 | TP10, TP11, TP12, TP13, TP30, TP31, TP32, TP40, TP41, TP50, TP51, TP52, TP54, TP55, TP100, TP101, TP102, TP103, TP104, TP105, TP106, TP107, TP108, TP109, TP112, TP113 | TP Thru-Hole |  | TP Thru-Hole |  | TP-.038 | Mill-Max | Gold | UW | 5382-0-00-15-00-00-03-0 | Alternative is the less expensive model 1031 van Keystone Electronics. PC Test Point Slotted Digikey pn 36-1031-ND
 | Cable harnesses: |  | https://nl.aliexpress.com/item/1005002942389730.html?curPageLogUid=Souz7hgWNLUp
 |  |  | https://nl.aliexpress.com/w/wholesale-pre-crimped-cable-6-colors.html
 | Changelog:
 | Juli 26 |  | The partnumber for the alternative for C6 has been added. C6 is very hard to get at the moment.
 | Juli 28 |  | Added a single quantity column to aid importing at Digikey
 |  |  | Corrected p/n for R3, R7
 |  |  | Corrected Digikey p/n for R108
 |  |  | Corrected Digikey p/n for U53
 |  |  | Corrected Digikey p/n for T10
 |  |  | Corrected Digikey p/n for R108
 |  |  | Corrected Digikey p/n for R118
 |  |  | Corrected qty for Q91
 |  |  | Added alternative for Q104, Q105
 |  |  | Corrected Digikey p/n for R2a, R2b, R2c, R2d, R2e, R2f
 | Aug-2 2023 |  | Changed p/n for U10 to stocked parts
 | Aug 3 2024 |  | Corrected a number of issues.
 | Aug 30 2024 |  | Corrected Digikey p/n for R132/R133
 |  |  | Changed board side for C28 to Top
 | March 22 2025 |  | Changed the pn for the two MOSFET heatsinks that are no longer avaiable.
 |  |  | Added an alternative for the test pins
 |  |  | Fixed a qty issue for a connector
 | June 17 2025 |  | Changed PN's for R2/R6 from 1206 to 0805
 | Aug 14 2025 |  | Added a comment to the value of R112, that is determined by the tolerance of the voltage setting potmeter.
 |  |  | Corrected values in the previously hidden Res colomn for R112, R113 and R125

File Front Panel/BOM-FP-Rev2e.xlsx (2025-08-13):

 |  | Front Panel Rev 2b
 |  |  | Surface Mount
Quantity | Designator | Description | Footprint | Cap | Value | Res | Manufacturer | Manufacturer Part # | Supplier | Supplier Part Number
2 | C1, C3 | CAP CER 1UF 50V X7R 0805 | CAPC2012M | 1uF | 1uF |  | Samsung | CL21B105KBFNNNE | Digi-Key | 1276-1029-1-ND
1 | C4 | CAP CER 10NF 100V X7R 0805 | CAPC2012M | 10nF | 10nF |  | Samsung | CL21B103KCANNNC | Digi-Key | 1276-1249-1-ND
1 | D1 | BLUE LED 3.5X2.8MM SMD | LED-BOTTOM-ENTRY |  | LED BLUE |  | Kingbright | AA3528QBS/D09 | Digi-Key | 754-AA3528QBS/D09CT-ND | Note that this is a different LED compared to the red and green one, because SunLED does not have this type in blue
2 | D2, D4 | RED LED 3.5X2.8MM SMD | LED-BOTTOM-ENTRY |  | LED RED |  | SunLED | XZMDK45WT-9 | Digi-Key | 1497-1331-1-ND
1 | D3 | GREEN LED 3.5X2.8MM SMD | LED-BOTTOM-ENTRY |  | LED GREEN |  | SunLED | XZVG45WT-9 | Digi-Key | 1497-1336-1-ND
1 | D5 | SBAT54T1G Series 30 200 mA Surface Mount Schottky Barrier Diode - SOD-123 | SOD123 |  | BAT54 |  | ON Semiconductor | SBAT54T1G | Digi-Key | SBAT54T1GOSCT-ND
2 | P1, P2 | Optional! NQ-4.0-3P 4MM 3PIN SMC | NQ032 |  | NQ032 |  | Amphenol | NQ0321100000G | Digi-Key | 609-5214-1-ND | These connectors only accept solid core wires and are not easy to use. I simply soldered the multi-core wires directly to the solder pads.
2 | Q1, Q3 | TRANS PNP 40V 0.2A SOT23 | SOT23-3M |  | 2N3906 |  | ON Semiconductor | MMBT3906LT1G | Digi-Key | MMBT3906LT1GOSCT-ND
1 | Q2 | TRANS N-CH 25V 1.25 W SOT-23 | SOT23-3M |  | IRFML8244 |  | International Rectifier | IRFML8244TRPBF | Digi-Key | IRFML8244TRPBFCT-ND
1 | Q4 | TRANS NPN 40V 0.2A SOT23 | SOT23-3M |  | 2N3904 |  | ON Semiconductor | MMBT3904LT1G | Digi-Key | MMBT3904LT1GOSCT-ND
1 | R1 | RES 100 OHM 1% 1/4W 0805 | RESC2012M |  | 100 | 100R | KOA Speer | RK73H2ATTD1000F | Digi-Key | 2019-RK73H2ATTD1000FCT-ND
1 | R2 | RES 1K OHM 1% 1/4W 0805 | RESC2012M |  | 1K | 1kR | KOA Speer | RK73H2ATTD1001F | Digi-Key | 2019-RK73H2ATTD1001FCT-ND
1 | R3 | RES 10K OHM 1% 1/4W 1206 | RESC3216M |  | 10K | 10kR | Stackpole Electronics | RMCF1206FT10K0 | Digi-Key | RMCF1206FT10K0CT-ND
2 | R4, R14 | RES 4.99K OHM 1% 1/4W 1206 | RESC3216M |  | 4.99K | 4.99kR | Stackpole Electronics | RMCF1206FT4K99 | Digi-Key | RMCF1206FT4K99CT-ND
1 | R10 | RES 1M OHM 1% 1/8W 0805 | RESC2012M |  | 1M | 1MR | KOA Speer | RK73H2ATTD1004F | Digi-Key | 2019-RK73H2ATTD1004FCT-ND
2 | R11, R13 | RES 4.99K OHM 1% 1/4W 0805 | RESC2012M |  | 4.99K | 4.99kR | KOA Speer | RK73H2ATTD4991F | Digi-Key | 2019-RK73H2ATTD4991FCT-ND
1 | R12 | RES 2K OHM 1% 1/4W 0805 | RESC2012M |  | 2K | 2kR | KOA Speer | RK73H2ATTD2001F | Digi-Key | 2019-RK73H2ATTD2001FCT-ND
 | Cable harnesses: |  | https://nl.aliexpress.com/item/1005002942389730.html?curPageLogUid=Souz7hgWNLUp
 |  |  | https://nl.aliexpress.com/w/wholesale-pre-crimped-cable-6-colors.html
Changelog:
2024-08-01 | Changed P1, P2 to optional because they are a pain to use.
Juli 25 | Added comment to blue LED
Juli 2025 | Changed R3 description and p/n to a 1206 part

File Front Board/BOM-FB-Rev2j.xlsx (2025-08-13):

 |  | Front Board Rev 2b
 |  |  | Surface Mount
Quantity | Designator | Description | Footprint | Value | Manufacturer | Manufacturer Part # | Supplier | Supplier Part Number
20 | C1, C5, C7, C10, C11, C13, C17, C25, C29, C33, C35, C37, C45, C47, C51, C75, C77, C81, C83, C122 | CAP CER 10NF 100V X7R 0805 | CAPC2012M | 10nF | Samsung | CL21B103KCANNNC | Digi-Key | 1276-1249-1-ND
27 | C2, C4, C6, C8, C12, C14, C16, C21, C22, C24, C28, C32, C34, C38, C40, C44, C46, C48, C50, C52, C76, C78, C80, C82, C100, C102, C121 | CAP CER 1UF 50V X7R 0805 | CAPC2012M | 1uF | Samsung | CL21B105KBFNNNE | Digi-Key | 1276-1029-1-ND
5 | C3, C42, C71, C73, C120 | CAP CER 100PF 50V COG 0805 | CAPC2012M | 100pF | KEMET | C0805C101J5GACTU | Digi-Key | 399-C0805C101J5GAC7800CT-ND
4 | C20, C27, C70, C72 | CAP CER 10PF 50V C0G 0805 | CAPC2012M | 10pF | KEMET | C0805C100K5GACTU | Digi-Key | 399-C0805C100K5GAC7800CT-ND
1 | C41 | CAP CER 1NF 250V X7R 0805 | CAPC0805M | 1nF | KEMET | C0805C102KAGECAUTO | Digi-Key | C0805C102KAGECAUTO-ND
3 | C43, C49, C87 | CAP CER 0.1UF 50V X7R 0805 | CAPC2012M | 0.1uF | KEMET | C0805C104M5RACTU | Digi-Key | 399-1169-2-ND
1 | C74 | CAP FILM 0.1UF 20% 63VDC PEN 1210 | CAPC3225M | 0.1uF | KEMET | LDEDB3100KA0N00 | Digi-Key | 399-12863-1-ND
2 | C85, C86 | CAP CER 100PF 250V COG 0805 | CAPC2012M | 100pF | Yageo | AC0805JRNPOYBN101 | Digi-Key | 311-3140-1-ND
3 | D20, D22, D24 | DIODE SI 85V 0.16mA SOT-23-3 | SOT23-3M | BAV199 | Nexperia | BAV199,215 | Digi-Key | 1727-2909-1-ND
2 | D21, D23 | ESD Suppressor TVS ±30KV 2-Pin SMF | SMF | SMF-15A-E3-08 | Vishay Semiconductors | SMF15A-E3-08 | Digi-Key | SMF15A-E3-08-ND
1 | D25 | DIODE ARRAY GP 200V 200MA SOT23-3 | SOT23-3M | MMBD1503A | ON Semiconductor / Fairchild | MMBD1503A | Digi-Key | MMBD1503ACT-ND
2 | D70, D120 | Diode; 500 mA (Surge); 1.0 V (Max.); 400 mW; 450 degC/W; 4 pF (Max.); 4 nS (Max | SOD123 | 1N4148 | Vishay | 1N4148W-E3-18 | Digi-Key | 1N4148W-E3-18CT-ND
1 | D73 | Diode Switching 400V 1A 2-Pin DO-214AC T/R | SMA-D | S1G | ON Semiconductor / Fairchild | S1G | Digi-Key | S1GFSCT-ND
1 | D121 | SBAT54T1G Series 30 200 mA Surface Mount Schottky Barrier Diode - SOD-123 | SOD123 | BAT54 | ON Semiconductor | SBAT54T1G | Newark | 50AC7280
2 | L70, L71 | Fixed Ind 4.7UH 1.9A 108MOHM SMD | CAPC3225M | 4.7uH | Cyntec | SDET32251E-4R7MS | Digi-Key | 2037-SDET32251E-4R7MSCT-ND
1 | Q20 | TRANS NPN 80V 1A SOT-223 | SOT223-4M | BCP56 | ON Semiconductor | BCP56-16T3G | Digi-Key | BCP56-16T3GOSCT-ND
1 | Q21 | TRANS PNP 80V 1.5A SOT-223 | SOT223-4M | BCP53 | ON Semiconductor | BCP53-16T3G | Digi-Key | BCP53-16T3GOSCT-ND
2 | Q22, Q23 | Single N-Channel 250 V 14 Ohm 2.3 nC SIPMOS® Small Signal Mosfet - SOT-23 | SOT23-3M | BSS139 | Infineon | BSS139 | Digi-Key | BSS139H6327XTSA1CT-ND
1 | Q120 | TRANS PNP 40V 0.2A SOT23 | SOT23-3M | 2N3906 | ON Semiconductor | MMBT3906LT1G | Digi-Key | MMBT3906LT1GOSCT-ND
1 | Q121 | TRANS NPN 40V 0.2A SOT23 | SOT23-3M | 2N3904 | ON Semiconductor | MMBT3904LT1G | Digi-Key | MMBT3904LT1GOSCT-ND
4 | R1, R3, R75, R85 | RES 1K OHM 1% 1/4W 0805 | RESC2012M | 1K | KOA Speer | RK73H2ATTD1001F | Digi-Key | 2019-RK73H2ATTD1001FCT-ND
16 | R2, R9, R10, R11, R13, R16, R39, R40, R45, R55, R71, R74, R76, R77, R78, R79 | RES 10K OHM 1% 1/4W 0805 | RESC2012M | 10K | KOA Speer | RK73H2ATTD1002F | Digi-Key | 2019-RK73H2ATTD1002FCT-ND
8 | R4, R5, R6, R8, R12, R56, R62, R84 | RES 20K OHM 1% 1/4W 0805 | RESC2012M | 20K | KOA Speer | RK73H2ATTD2002F | Digi-Key | 2019-RK73H2ATTD2002FCT-ND
1 | R7 | RES 4.75K OHM 1% 1/4W 0805 | RESC2012M | 4.75K | KOA Speer | RK73H2ATTD4751F | Digi-Key | 2019-RK73H2ATTD4751FCT-ND
1 | R14 | RES 2.21K OHM 1% 1/4W 0805 | RESC2012M | 2.21K | KOA Speer | RK73H2ATTD2211F | Digi-Key | 2019-RK73H2ATTD2211FCT-ND
8 | R20, R25, R42, R43, R57, R63, R120, R122 | RES 49.9K OHM 1% 1/4W 0805 | RESC2012M | 49.9K | KOA Speer | RK73H2ATTD4992F | Digi-Key | 2019-RK73H2ATTD4992FCT-ND
1 | R21 Note | RES 90.9K OHM 1% 1/4W 0805 | RESC2012M | 90.9K | KOA Speer | RK73H2ATTD9092F | Digi-Key | 2019-RK73H2ATTD9092FCT-ND | With a 10K 5T Pot20, the value changes to 9K09
 | R21 Alternative | RES 9.09K OHM 1% 1/4W 0805 | RESC2012M | 9.09K | KOA Speer | RK73H2ATTD9091F | Digi-Key | 2019-RK73H2ATTD9091FCT-ND
11 | R22, R23, R26, R27, R31, R32, R58, R64, R72, R73, R89 | RES 100K OHM 1% 1/4W 0805 | RESC2012M | 100K | KOA Speer | RK73H2ATTD1003F | Digi-Key | 2019-RK73H2ATTD1003FCT-ND
8 | R24, R37, R41, R44, R47, R68, R82, R83 | RES 100 OHM 1% 1/4W 0805 | RESC2012M | 100 | KOA Speer | RK73H2ATTD1000F | Digi-Key | 2019-RK73H2ATTD1000FCT-ND
1 | R29 | RES 33.2K OHM 1% 1/4W 0805 | RESC2012M | 33.2K | KOA Speer | RK73H2ATTD3322F | Digi-Key | 2019-RK73H2ATTD3322FCT-ND
1 | R30 | RES 3K OHM 1% 1/4W 0805 | RESC2012M | 3K | KOA Speer | RK73H2ATTD3001F | Digi-Key | 2019-RK73H2ATTD3001FCT-ND
1 | R34 | RES 41.2K OHM 1% 1/4W 0805 | RESC2012M | 41.2K | KOA Speer | RK73H2ATTD4122F | Digi-Key | 2019-RK73H2ATTD4122FCT-ND | Note maximum FET offset voltage selection below
1 | R35 | RES 11K OHM 1% 1/4W 0805 | RESC2012M | 11K | KOA Speer | RK73H2ATTD1102F | Digi-Key | 2019-RK73H2ATTD1102FCT-ND | Note maximum FET offset voltage selection below
1 | R36 | RES 10 OHM 1% 1/4W 0805 | RESC2012M | 10 | KOA Speer | RK73H2ATTD10R0F | Digi-Key | 2019-RK73H2ATTD10R0FCT-ND
1 | R38 | RES 15K OHM 1% 1/4W 0805 | RESC2012M | 15.0K | KOA Speer | RK73H2ATTD1502F | Digi-Key | 2019-RK73H2ATTD1502FCT-ND | Note maximum FET offset voltage selection below
4 | R46, R61, R67, R88 | RES 1M OHM 1% 1/8W 0805 | RESC2012M | 1M | KOA Speer | RK73H2ATTD1004F | Digi-Key | 2019-RK73H2ATTD1004FCT-ND
1 | R49 | RES 1K OHM 1% 1/4W 1206 | RESC3216M | 1K | Stackpole Electronics | RMCF1206FT1K00 | Digi-Key | RMCF1206FT1K00CT-ND
1 | R50 | RES 200 OHM 1% 1W 2512 | RESC6432M | 200 | Bourns | CRM2512-FX-2000ELF | Digi-Key | CRM2512-FX-2000ELFCT-ND
1 | R51 | RES 499 OHM 1% 1W 2512 | RESC6432M | 499 | Stackpole Electronics | RMCF2512FT499R | Digi-Key | RMCF2512FT499RCT-ND
1 | R52 | RES 1K OHM 1% 1W 2512 | RESC6432M | 1K | Stackpole Electronics | RMCF2512FT1K00 | Digi-Key | RMCF2512FT1K00CT-ND
1 | R53 | RES 2K OHM 1% 1/4W 0805 | RESC2012M | 2K | KOA Speer | RK73H2ATTD2001F | Digi-Key | 2019-RK73H2ATTD2001FCT-ND
2 | R54, R87 | RES 4.99K OHM 1% 1/4W 0805 | RESC2012M | 4.99K | KOA Speer | RK73H2ATTD4991F | Digi-Key | 2019-RK73H2ATTD4991FCT-ND
2 | R59, R65 | RES 200K OHM 1% 1/4W 0805 | RESC2012M | 200K | KOA Speer | RK73H2ATTD2003F | Digi-Key | 2019-RK73H2ATTD2003FCT-ND
1 | R60 | RES 499K OHM 1% 1/4W 0805 | RESC2012M | 499K | KOA Speer | RK73H2ATTD4993F | Digi-Key | 2019-RK73H2ATTD4993FCT-ND
1 | R70 | RES 100K OHM 1% 1/4W 1206 | RESC3216M | 100K | Stackpole Electronics | RMCF1206FT100K | Digi-Key | RMCF1206FT100KCT-ND
4 | R80, R81, R86, R90 | RES 4.02 ohm 1% 2W 2512 | RESC6432BM | 4R02 | Stackpole Electronics | RMCP2512FT4R02 | Digi-Key | 738-RMCP2512FT4R02CT-ND | If difficult to get, use 4R0 resistors, or any combination that will result in a 1R0 total value.
1 | R100 | RES 18K OHM 1% 1/4W 0805 | RESC2012M | 18.0K | KOA Speer | RK73H2ATTD1802F | Digi-Key | 2019-RK73H2ATTD1802FCT-ND
1 | R102 | RES 2.05K OHM 1% 1/4W 0805 | RESC2012M | 2.05K | KOA Speer | RK73H2ATTD2051F | Digi-Key | 2019-RK73H2ATTD2051FDKR-ND
1 | R104 | RES 36R5 OHM 1% 1/4W 0805 | RESC2012M | 36.5 | KOA Speer | RK73H2ATTD36R5F | Digi-Key | 2019-RK73H2ATTD36R5FCT-ND
1 | R106 | RES 95R3 OHM 1% 1/4W 0805 | RESC2012M | 95.3 | KOA Speer | RK73H2ATTD95R3F | Digi-Key | 2019-RK73H2ATTD95R3FCT-ND
1 | R107 | RES 200 OHM 1% 1/4W 0805 | RESC2012M | 200 | KOA Speer | RK73H2ATTD2000F | Digi-Key | 2019-RK73H2ATTD2000FCT-ND
1 | R108 | RES 453 OHM 1% 1/4W 0805 | RESC2012M | 453 | KOA Speer | RK73H2ATTD4530F | Digi-Key | 2019-RK73H2ATTD4530FCT-ND
2 | R109, R110 | RES 1.8K OHM 1% 1/4W 0805 | RESC2012M | 1800 | KOA Speer | RK73H2ATTD1801F | Digi-Key | 2019-RK73H2ATTD1801FCT-ND
1 | R121 | RES 249K OHM 1% 1/8W 0805 | RESC2012M | 249K | KOA Speer | RK73H2ATTD2493F | Digi-Key | 2019-RK73H2ATTD2493FDKR-ND
1 | U1 | IC COUNTER 12BIT CMOS 16SOIC | SOIC127P600X16-M | 4040 | ON Semiconductor | MC14040BDR2G | Digi-Key | MC14040BDR2GOSCT-ND
1 | U2 | Quad NAND w/Schmitt trigger | SOIC127P600X14-M | HCF4093 | STMicroelectronics | HCF4093YM013TR | Digi-Key | 497-14376-6-ND
3 | U4, U20, U70 | 40-V, dual 1MHz, rail-to-rail input/output, low-offset-voltage, low-power op amp 8-SOIC -40 to 125 | SOIC127P600X168_HS-8N | OPA2990 | Texas Instruments | OPA2990IDR | Digi-Key | 296-53506-1-ND
1 | U5 | IC OSC SINGLE TIMER 3MHZ 8-SOIC | SOIC127P600X168_HS-8N | LMC555 | Texas Instruments | LMC555CMX/NOPB | Digi-Key | LMC555CMX/NOPBCT-ND
1 | U6 | Demultiplexer 4-to-10 16-Pin SOIC | SOIC127P600X16 | 4028 | ON Semiconductor | MC14028BDR2G | Digi-Key | MC14028BDR2GOSCT-ND
1 | U21 | Single, 40-V, 5-MHz, 4-mV offset voltage, 20-V/µs, In to V+ op amp with -40°C to 125°C operation 5-SOT-23 -40 to 125 | SOT95P300X130-5M | TL071 | Texas Instruments | TL071HIDBVR | Digi-Key | 296-TL071HIDBVRCT-ND
2 | U22, U23 | IC OPAMP DIFF 18MHZ RRO 8SOIC | SOIC127P600X168_HS-8N | OPA209A | Texas Instruments | OPA209AID | Digi-Key | 296-28030-5-ND
2 | U24, U25 | OPTOISO 5KV TRANS W/BASE 6SMD | SOIC254P1000X6 | CNY17-1S | Vishay Lite-On | CNY17-1S | Digi-Key | 160-1309-5-ND
1 | U71 | HIGH PRECISION, LOW NOISE, LOW POWER OP-AMP | SOIC127P600X168_HS-8N | OPA207A | Texas Instruments | OPA207ID | Digi-Key | 296-47934-ND
 |  |  | Through Hole
8 | C15, C23, C26, C30, C31, C36, C39, C84 | CAP ALUM 100uF 20% 25V | CAPPR2-5x11 | 100uF | Rubycon | 25YXJ100M5X11 | Digi-Key | 1189-2237-ND
1 | C79 | CAP ALUM 100UF 20% 35V | CAPPR2.5-6.3X10 | 100uF | Rubycon | 35YXJ100M6.3X11 | Digi-Key | 1189-2260-ND
1 | J1 | 2.54mm 3 pin | DTA-100-3 | 640456-3 | TE Connectivity | 640456-3 | Digi-Key | A19470-ND
6 | J2, J74, J100, J101, J102, J120 | 2.54mm 2pin | DTA-100-2 | 640456-2 | TE Connectivity | 640456-2 | Digi-Key | A1921-ND
1 | J70 | 5.08mm 2pin | PHOENIX2X0.2 |  | CUI Devices | TB004-508-02BE | Digi-Key | 102-6179-ND
2 | J71, J72 | Conn PC Terminal Block 2 POS 3.5mm Solder Thru-Hole 17.5A | 1988956 | 1988956 | Phoenix Contact | 1988956 | Digi-Key | 277-1779-ND
2 | J73, J76, J77, J79 | Conn Banana Plug SKT 1 POS Solder ST Panel Mount 1 Port | Banana-Turet | Red | Radiall | R921921000 | Digi-Key | 2201-R921921000-ND
2 | J73, J76, J77, J79 | Conn Banana Plug SKT 1 POS Solder ST Panel Mount 1 Port | Banana-Turet | Blue | Radiall | R921923000 | Digi-Key | 2201-R921923000-ND
2 | J75, J78 | Conn Banana RCP 1 POS Solder Cup ST Cable Mount 1 Port | Banana-Turet | Black | Radiall | R921920000 | Digi-Key | 2201-R921920000-ND
1 | J104 | 2.54mm 4pin | DTA-100-4 | 640456-4 | TE Connectivity | 640456-4 | Digi-Key | A1922-ND
2 | P70, P71 | TEST SOCKET 5 PIN | TEST-SOCKET-5PIN | TO-247-5 | UNK | TO-247-5 | AliExpress | https://nl.aliexpress.com/item/4000140932878.html
2 | Pot1, Pot70 | TRIMMER 1K OHM 0.5W TH | 7mmSq-CCW | 1K | Nidec Copal | CT6EP102 | Digi-Key | CT6EP102-ND
1 | Pot2, S1 | Res Conductive Plastic POT 100K Ohm 20% 1/4W 1(Elec)/1(Mech)Turn 3.18mm (9.53 X 9.75 X 20.24mm) Pin Panel... | Off-PCB-CCW-Switch | 100K | Bourns | 3310H-003-104L | Digi-Key | 3310H-003-104L-ND
1 | Pot20 | Panel Control - 1/2" (12.5Mm) Sq 1-Turn / Tray Packaging Rohs Compliant: Yes | Off-PCB-CCW | 100K | Bourns | 53CAD-E16-B20L | Digi-Key | 53CAD-E16-B20L-ND
 | Pot20 alternative | POT 10K OHM 1W WIREWOUND LINEAR | Off-PCB-CCW | 10K | Nidec Copal | M-1305 10K | Digi-Key | 563-2116-ND | Note: R21 changes to 9K09
1 | Pot71 | Res Cermet Trimmer 10K Ohm 10% 1/2W 1(Elec)/1(Mech)Turn 2.6mm (7 X 7 X 8.2mm) Pin Thru-Hole Bulk | 7MM-SQ-Side | 10K | Nidec Copal | CT6EP103 | Digi-Key | CT6EX103-ND
1 | Pot100 | POT Shaft 100K Ohm 10% 'PANEL MNT 1/8in Shaft | P260T | 100K | TT BI | P260T-S1AF3CB100K | Digi-Key | 987-1336-ND
1 | Pot102 | POT Shaft 100K Ohm 10% 'PANEL MNT 1/4in Shaft | P260T | 100K | TT BI | P260T-D1BS3CB100K | Digi-Key | 987-1335-ND
1 | S3 | Rotary Switch 125VAC 250mA 1-P 12-Pos 12 Power Tap Selection PC Terminal | MRA112 | MRA112 | NKK Switches | MRA112 | Digi-Key | 360-2584-ND | This part is now obsolete/low stock
 | S3 | Rotary Switch 125VAC 250mA 1-P 12-Pos 12 Power Tap Selection PC Terminal | MRAN112 | MRAN112 | NKK Switches | MRAN112 | Digi-Key | 360-MRAN112-ND | This could be the replacement for the now obsolete MRA112, we have not tested this! Newark has this p/n: 51P22-01-1-16N
1 | S20 | Toggle Switch, 100 Series, SPDT, ON-OFF-ON, Sealed, 5A, 120VAC, 28VDC, PC Pin | EG2377 | EG2377 | E-Switch | 100SP3T1B1M2QEH | Digi-Key | EG2377-ND
1 | S21 | Rotary Switch; PC mount; 22.5° ; 1 deck; 1 pole/deck; 16 positions/pole; non- | GRAYHILL-51-16-LgPin | 51P22-01-1-16N | Grayhill | 51P22-01-1-16N | Digi-Key | GH7687-ND
2 | S22, S72 | SWITCH TOGGLE 3PDT 5A 120V | EG2425 | EG2425 | E-Switch | 1003P1T1B1M2QEH | Digi-Key | EG2425-ND
1 | S70 | Switch Toggle ON ON SPDT Round Lever PC Pins 5A 250VAC 28VDC PC Mount with Threads | EG5748-ND | EG5748 | E-Switch | 100SP1T1B1M3QEH | Digi-Key | EG5748-ND
1 | S71 | Switch Toggle ON OFF ON DPDT Round Lever PC Pins 5A 250VAC 28VDC PC Mount with Threads | EG2414 | EG2414 | E-Switch | 100DP3T1B1M2QEH | Digi-Key | EG2414-ND
1 | S100 | Switch Toggle ON ON ON SP3T Small Bat Lever PC Pins 6A 250VAC 30VDC PC Mount with Threads | M2024 | M2024 | NKK Switches | M2024SS1W03 | Digi-Key | 360-2074-ND | This part is now obsolete/low stock
 | S100 | Switch Toggle ON ON ON SP3T Small Bat Lever PC Pins 6A 250VAC 30VDC PC Mount with Threads | E211SYCBE | E211SYCBE | C&K | E211SYCBE | Digi-Key | CKN9860-ND | This could be the replacement for the now obsolete M2024, we have not tested this!
1 | S101 | Switch Rotary N.O./N.C. SP6T 6 Flatted Shaft PC Pins 2.5A 125VAC 125VDC Automotive | A106 | A10605RNCQ | ITT C&K | A10605RNCQ | Digi-Key | CKN10615-ND
1 | S102 | Switch Toggle - Miniature | EG2414 | DPDT On-On | E-Switch | 100DP1T1B1M2QE | Digi-Key | 100DP1T1B1M2QE-ND
7 | TP1, TP2, TP4, TP5, TP22, TP25, TP70 | TP Thru-Hole | Model 1031 | TP Thru-Hole | Keystone | 36-1031-ND | UW | model 1031 van Keystone Electronics. PC Test Point Slotted Digikey pn 36-1031-ND
 | Cable harnesses: | https://nl.aliexpress.com/item/1005002942389730.html?curPageLogUid=Souz7hgWNLUp
 |  | https://nl.aliexpress.com/w/wholesale-pre-crimped-cable-6-colors.html
 | Changelog:
 | Juli 27 | The partnumber for S70 has been updated
 | Juli 28 | Corrected digikey p/n for R80, R81, R86, R90
 |  | Added comment for P70, P71
 |  | Corrected Digikey p/n for R80, R81, R86, R90
 |  | Corrected Digikey p/n for C1 et all
 |  | Corrected Digikey p/n for C2 et all
 |  | Corrected Digikey p/n for D20, D22, D24
 |  | Corrected Digikey p/n for D21, D23
 |  | Corrected Digikey p/n for D25
 |  | Corrected Digikey p/n for C15 at all
 | Juli 29 | Corrected p/n's for U22, U23
 | Sep 9 | Updated the link for the P70, 71 test adapters
 | 2025-03-15 | Added alternatives for obsolete parts
 |  | Also check Newark, they have transformers that are less expensive and some low stock parts still available.
 |  | Added pn for the test pins
 | 2025-04-22 | Corrected qty and p/n for P100 and qty for P102
 | 2025-06-17 | Corrected size for C41
 | FET Offset Max Voltages | Resistor Values
 |  | R34 | R35 | R38
 | 1V | 71K5 | 9K53 | 11K
 | 1.5V | 54K9 | 10K7 | 13K3
 | 2V | 41K2 | 11K | 15K
 | 2.5V | 30K1 | 10K | 15K
 | 3V | 26K7 | 10K7 | 17K8
 | 4V | 18K7 | 10K | 21K5
 | 5V | 15K | 10K | 7K5
 | 6V | 24K4 | 10K | 16K9
 | 7.5V | 21K | 10K5 | 21K
 | 10V | 17K4 | 11K5 | 34K
 | Also look at the spreadsheet on the Github site under Front Board.

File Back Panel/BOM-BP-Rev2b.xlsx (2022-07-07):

 |  | Rear Plate Rev 2b
 |  |  | Through Hole
Quantity | Designator | Description | Footprint | Value | Manufacturer | Manufacturer Part Number | Supplier | Supplier Part Number
1 | J1 | PEM w/Filter, IEC, C8, 250VAC, 2.5A, Front Panel Mt-Screw, Solder Term, Stndrd, IP40, PC2 | 5008 | 5008 | Schurter | 5008.0022 | Digi-Key | 486-4371-ND
3 | P1, P2, P3 | CONN BNC JACK STR 50 OHM SOLDER | BNC | BNC | TE Connectivity | 3-1634523-1 | Digi-Key | A97548-ND
1 | S1 | Switch Rocker ON None OFF DPST Quick Connect Curved Rocker 6A 250VAC 30000Cycles | CWSB | CWSB21AA1F | NKK Switches | CWSB21AA1F | Digi-Key | 360-1725-ND

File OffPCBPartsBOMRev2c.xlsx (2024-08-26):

 |  | Off PCB components Rev 2b
Quantity | Designator | Description | Footprint | Cap | Value | Res | Manufacturer | Manufacturer Part # | Supplier | Supplier Part Number
1 | none | XFRMR LAMINATED 56VA CHAS MOUNT 115/230V | N.A. |  |  |  | Hammond | 186E56 | Digi-Key | HM4710-ND
1 | none | BOX ABS GRAY 9.843"L X 7.087"W | N.A. |  |  |  | Hammond | RM2095M | Digi-Key | HM1100-ND
1 or 0 | none | CORD 18AWG NEMA 1-15P - C7 6.56' (USA) | N.A. |  |  |  | Schurter Inc. | 6010.5274 | Digi-Key | 486-4157-ND
1 or 0 | none | CORD EN50 075 - IEC320-C7 13.12' (EU) | N.A. |  |  |  | Schurter Inc. | 6013.0478 | Digi-Key | 486-4926-ND
3 | none | CONN JUMPER SHORTING GOLD FLASH | N.A. |  |  |  | Sullins | SPC02SYAN | Digi-Key | S9001-ND
1 | none | FUSE | N.A. |  |  |  | Bel Fuse | 5ET-1-R | Digi-Key | 507-1538-ND
1 | none | COVER FOR ONLY #4527 FUSE HOLDER | N.A. |  |  |  | Keystone | 4527C | Digi-Key | 36-4527C-ND
6 | none | CONN QC RCPT 16-20 AWG | N.A. |  |  |  | Phoenix | 3240538 | Digi-Key | 277-15446-ND
4 | none | WASHER FLAT RETAINING #4 NYLON | N.A. |  |  |  | Essentra Components | 16FWRT004050 | Digi-Key | RPC6339-ND
1 | none | Knobs & Dials BLK .940 DIA KNOB | N.A. |  |  |  | Apem | 420065B1/4 | Mouser
3 | none | Knobs & Dials BLK .748 DIA KNOB | N.A. |  |  |  | Apem | 420063B1/4 | Mouser
2 or 3 | none | Knobs & Dials BLK .500 DIA KNOB 1/8in Shaft | N.A. |  |  |  | Apem | 420061B1/8 | Mouser
0 or 1 | none | Knobs & Dials BLK .500 DIA KNOB 1/4in Shaft | N.A. |  |  |  | Apem | 420061B1/4 | Mouser
 | none | ROUND SPACER #4 NYLON 1/2" | N.A. |  |  |  | Bivar Inc. | 9911-500 | Digi-Key | 492-1093-ND
 |  | The spacers are used to convert the diameter for the knobs
 |  | Crimp headers for interconnect cables
11 | 2-pin | CONN RCPT 2POS IDC 22AWG TIN | N.A. |  |  |  | TE Connectivity | 3-643813-2 | Digi-Key | A31107-ND
4 | 3-pin | CONN RCPT 3POS IDC 22AWG TIN | N.A. |  |  |  | TE Connectivity | 3-643813-3 | Digi-Key | 3-643813-3-ND
2 | 4-pin | CONN RCPT 4POS IDC 22AWG TIN | N.A. |  |  |  | TE Connectivity | 3-643813-4 | Digi-Key | A31108-ND
 |  | Connections to the 2mm banana jacks
2 | optional | WE-TEMA TOROIDAL EMI SUPPRESSION |  |  |  |  | Würth Elektronic | 782115020030 | Digi-Key | 732-782115020030-ND | for the B/G connections to the 2mm banana jacks
 |  | Used during the calibration of the instrument
1 | none | RES 1K OHM 1% 0.5W AXIAL | N.A. |  |  | 1K | e.g. Stackpole | RNF12FTD1K00 | Digi-Key | RNF12FTD1K00CT-ND
1 | none | RES 2K OHM 1% 10W AXIAL | N.A. |  |  | 2K | Ohmite | 40F2K0E | Digi-Key | 40F2K0E-ND | 5W is sufficient
Changelog:
Juli 26 |  | The partnumber for the US cord has been corrected
 |  | The partnumber for the EU cord has been added
Juli 28 |  | Corrected Digikey p/n for the Fuse holder cover
2024-08-01 |  | Added connector headers, calibration resistors, beads

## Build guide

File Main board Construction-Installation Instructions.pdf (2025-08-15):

## Main Board Construction & Installation Instructions

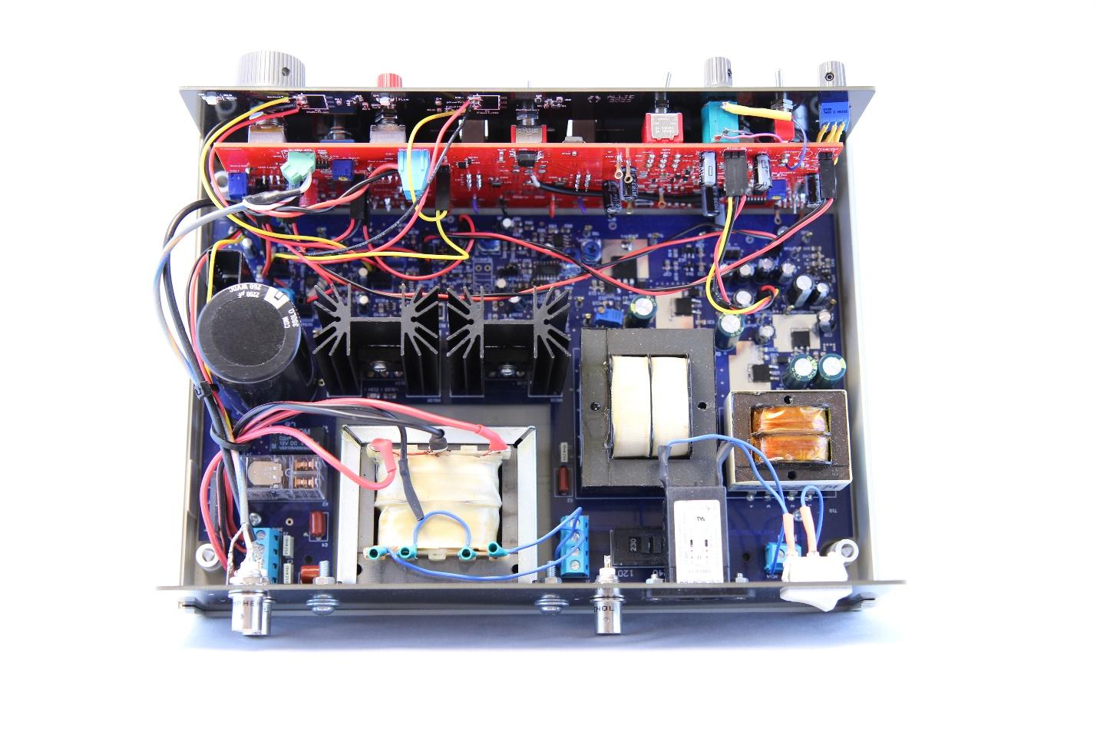
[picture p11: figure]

1. Solder all the SMD components to the Main on both sides.
2. Add the trimmers. Put them in the mid position.
3. Add all the terminal blocks.
4. Add the transformer filter capacitors, C1 and C2, C3, C4, C5 and C8.
5. Add all the test point, although you could leave out a few marked GND on the edge of the board.
6. Add all the .1 connector strips.
7. Add a jumper to P1-En
8. Add a jumper to J50, the Z-pulse direction. Set it to the left position.
9. Add the main voltage selector switch. With the switch showing the 230V marker, the 230 indicator should be on the side pointing to the J1 connector block. The new pn in the BOM has not markings on it anymore. This avoids a wrong placement and or confusion.
10. Select the right main switch voltage.
11. Check with a DMM in the Ohms position if there are no shorts between ISO and plusStep, ISO and minStep, GND and plusTri, GND and minTri, GND and xyPlus and GND and 7.5V.
12. Add T10, the supply rail transformer.
Note: the leg numbers are flipped from the silkscreen:

Pins 1234 on the xfrmr are actually pins 4321 on the board. The secondary pins 5678 are actually 8765 on the board.
13. On the back plate, install the C8 receptacle with the filter. Install the main switch and add the three BNC connectors with the ground lugs.
14. Connect the main switch to the C8 receptacle with a wire and isolate the connections with shrink wrap tubing.
15. Put the Back plate in the bottom of the enclosure. This is the side with the low flanks.
16. Position the Main board in the enclosure but don’t screw it down yet.
17. Connect one side of the switch and one side of the filter with wires to J3, the mains input connector on the Main board.
18. Connect a DMM between an ISO test point and minusStep.
19. Add a mains power cable and connect it to mains. Be careful not to touch the mains related parts from now on.
20. Before you turn on the instrument and verify that you have -15V, make sure all the THT electrolyte capacitors for the rails are installed.
21. Connect the DMM between ISO and plusStep and verify that you have +15V.
22. Connect the DMM between GND and plusTri and verify that you have about 10V.
23. Connect the DMM between GND and minusTri and verify that you have -5V.
24. Connect the DMM between GND and xyPlus and verify that you have at least 24V.
25. Connect the DMM between GND and 7.5V and verify that you have 7.5V.
26. Turn off the power.
27. Use a scope and connect one channel with the GND lead to a GND test point and the probe tip to the Tri test point.
28. Turn on power and verify that you have a triangle waveform.
29. Turn trimmer Pot52, marked Freq and verify that you can change the frequency of the triangle. Set it to about 160Hz.
30. Turn trimmer Pot51, marked 0V Adjust and verify that you can adjust the bottom of the triangle waveform a little above and below the GND level. Adjust it at about the GND level.
31. Connect the probe tip to the Rect test point and verify that you have a rectangular waveform.
32. Switch off the main power and remove the power lead.
33. Disconnect the Scope probe and disconnect the mains wires going to J3 so we can remove the Main board.
34. Add the two relays, K1 and K2.
35. Add the bridge D4.
36. Add C6, the main capacitor.
37. Prepare the main transformer.
Refer to the Above_from_Back.jpg picture for details for my 230V version and the J1, J2 and J3 connections.
The transformer can be mounted to the bottom of the enclosure, but you’ll have to be very careful that the nuts and bolts don’t touch the bottom of the Main board. You can also mount the transformer to the Back plate, by putting it on its back, lying on the bottom of the enclosure. This is what I did and the pictures show. If you do that, make sure that the Back plate can be fully inserted into the bottom of the enclosure. Drill holes that are a little larger than the bolts you will use. I used 4mm bolts and drilled 5mm holes. Because the iron of the transformer is not aligned with the frame, I used two rings on each bolt to create some space between the transformer and the back plate. I used anti-slippage rings to secure the nuts.
38. The next step is to separate the two secondary windings so we can switch them in parallel or in series. Both windings on the transformer are connected to a single post in the middle of the transformer (solder lug 8). We need to pry them loose and separate them. By heating that connection with a solder iron, you can carefully! separate the two wires. Use an Ohm meter to make sure you have the correct two windings identified and solder the wire that connects to solder lug 6 back to solder lug 8. Solder a wire from the now free winding end (that is the winding connected to solder lug 10) and insulate that with shrink tubing. In the picture, that is the black end pointing to the half circle blue wire of the primary.

The connections from the 4 windings of the transformer need to go to the proper binding post pins of J2 on the Main board, in order to put the now separate windings in series or parallel. The J2 silkscreen indicates the two windings, but unfortunately there is no silkscreen for the pin numbers.
Proceed as follows. Solder lug 6 of the transformer goes to the J2 pin closest to the relays (K2). Solder lug 8 of the transformer (same winding) goes to the next J2 pin. The “free” wire from the next winding goes to the third pin of J2 and solder lug 10 goes to the fourth pin (closest to the Back panel).
39. Connect the primary windings to the Main board through J2. If you only use the 230V mains supply, you can solder a short wire between the two primary windings by bridging the two middle soldering posts and don’t need to go all the way to J2. The outside solder lugs of the transformer, 1 and 5 now go to the outside pins of J2. Make sure that all 4 connections on the transformer are well insulated with shrink tubing.
40. Once everything is mounted and the connections are verified, add the mains leads from J3 to the Back panel Fuse and the mains receptable.
41. Perform a quick test to make sure this is all working.

Connect a DMM in DC mode between TransP and TransM, they are the raw DC voltage test points.
42. Add a jumper lead between J4-2 and J4-3, the 3-way switch connector. This will set the supply voltage to the 35V range, switching the two secondary windings in parallel.
43. Turn on the main power and verify that you have about 40V DC.
44. Switch the power off.
45. Connect J4-1 with J4-3, which is the 70V range, by switching the secondary windings in series.
46. Turn on the main power and verify that you have about 80V DC.
47. Switch off the power and remove the mains lead.
48. Install T1, the high voltage transformer. You may have to disconnect the wire connections to the Main board to get access to the bottom of the Main board.
49. Re-connect all wires again, and add the main power lead.

50. Reconnect the DMM in DC mode between TransP and TransM again.
51. Connect J4-4 with J4-3, to activate K1 which is the 200V range relays. Both transformers are now in series.
52. Turn on power and verify that you have more than 230V DC.
53. Turn off the power and remove the mains lead.
54. Disconnect all wires going to the Main board so we can mount the MOSFET’s and the Current Source.
55. Use nuts and bolts and some heat paste to loosely mount the MOSFET’s to the heatsinks. Use the second hole from the top such that the leads are in line with the heatsink mounting pins. Do not tighten the nuts and bolts yet.
56. Solder both MOSFET’s/Heatsinks to the Main board. When they are in place, you can tighten the nuts and bolts.
57. Watch out that test point Vcur is not touching the heatsink of Q105. You can bend it a little to create a few mm spacing.
58. Mount the Current Source transistor Q91 to the heatsink HS90 and solder them to the Main board.
59. Install the Main board back into the enclosure and re-connect all leads again.
60. In order to make the DUT supply functional without the Front board, you need to add a jumper between the two pins of J54, which connects the Triangle waveform to the DUT supply.
61. We also need to connect the 100K Volt potmeter between one of the J102 pins called Vset (CCW) and DUTSupplyM/TransM (Tap+CW) so we have an output, and we can set the level. Set the potmeter to about mid-range. Note that after the latest revision, J102 has two interconnected pins. You can use either of them.
62. Connect the jumper lead between J4-2 and J4-3 to select the 35V range. Do not select the other ranges with all these flying leads to prevent you from touching dangerous voltages.
63. Add a scope probe with the GND clip to a GND test pin, and the probe tip to pin 1 of J6, which is indicated with CS-.
64. Verify that you have made all connections and they are correct before we do the final and acid test.
65. Add the main power lead.
66. Turn on the power and verify that you have a negative going triangle waveform and that you can change the amplitude with the 100K volt setting potmeter. If you do, we have a working Main board.
67. If not, quickly remove power and you need to trouble shoot the DUT supply.
68. If you did, congratulations!
69. Now we need to verify that we can calibrate the output to 200V. This depends on the toleration of the 100K voltage setting potmeter, which has a +/-10% tolerance.
70. Change the jumper from J4-2 for the 35V selection in step 62, to the 200V selection, J4-4.
71. Make sure that the trimmer Pot101 is in the mid position and measure the output again, using the same instruction as in point 63.
72. Set the output with the 100K volt setting potmeter to the maximum. It should be around 200V +/- 10V. Now check if you can trim the value with Pot101 to a precise 200V with the trimmer about in the middle of the range with at least some +/- 5V room. If you cannot do this, you have to change the value of R112 until you can, which is easier to do at this point.
73. If this is successful, you’re done with this part of the installation & verification.

WARNING:
Before making any measurements yourself, make sure you are limiting the current to the DUT when powering them. It is very easy to blow them up if you are not careful. This is especially true for MOSFET's and their low RDSON.

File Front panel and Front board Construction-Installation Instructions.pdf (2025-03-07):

## Front panel & Front Board Installation Instructions

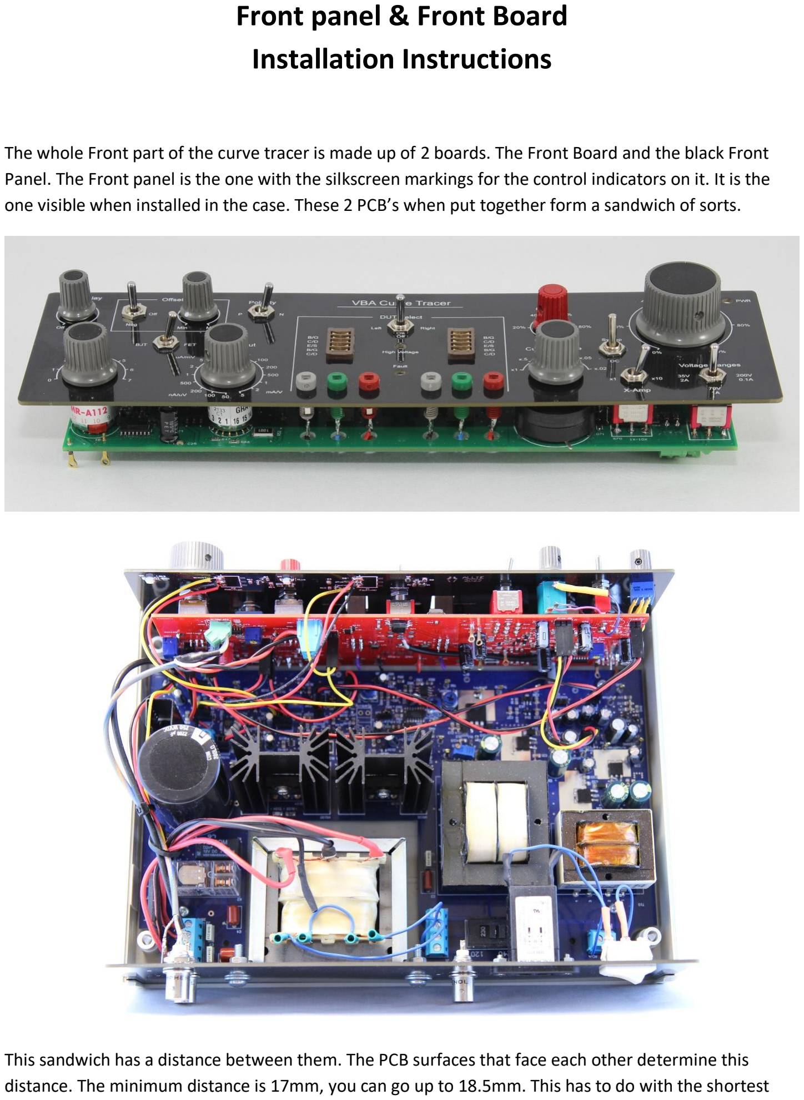
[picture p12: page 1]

The whole Front part of the curve tracer is made up of 2 boards. The Front Board and the black Front Panel. The Front panel is the one with the silkscreen markings for the control indicators on it. It is the one visible when installed in the case. These 2 PCB’s when put together form a sandwich of sorts.

This sandwich has a distance between them. The PCB surfaces that face each other determine this distance. The minimum distance is 17mm, you can go up to 18.5mm. This has to do with the shortest and tallest parts. The shortest part is the 16-position step output rotary switch S21 and the tallest part is the Current range rotary switch S101 or the optional 3 or 5-turn Offset pot, Pot20. This potmeter requires at least a 16.5mm spacing. This multi-turn part may come with a nut that may be too thick for the knob you want to use. You can use any of the nuts that come with the toggle switches, they have the same pitch. The toggle switches that are mounted on the Front panel need to have pins that extend through the solder holes in the Front board. S21 has a mounting shaft that needs to stick out of the Front Panel enough to put a nut on it and mount the knob. Try the secure mounting of the knob you selected before you make anything permanent.

Note that we have recently made the two 3-pin connectors (P1 and P2) on the Front panel optional. These connectors are a pain to use and only accept a solid core wire. I simply soldered the multi-core wires I used directly to the solder pads of these connectors. This can be seen in the picture just above.

1. Solder all the SMD components to the Front board and the Front panel on both sides.
2. Be aware that it is very difficult to differentiate between the cathode or anode side for the special reversed mounting SMD LED’s for the Front panel. Use a DMM in the Diode mode to make sure you mount them correctly.
3. While adding the THT parts, the silkscreen can be used to figure out to what side of the board the components need to go, but take extra care of soldering them to the correct side. On the GitHub are 3D files for the boards to make it clearer.
4. The 100uF caps can now be mounted on the Front board. Note that it is better to mount C23 to the other side of the board. Other makers have noticed that it hits the Main board. Also note that C79 is a 35V version. After soldering, but before you clip the leads, use a DMM and check for shorts on all the electrolytes.
5. Make sure that the two DUT connectors will fit the rectangular holes in the Front panel. There are no specifications for them, so we don’t know if they will always fit. Use a fine file to make them fit if needed, but use tape around the edges of the PCB to protect the front of the Front panel in case you slip the file, to avoid scratches.
6. Solder the two DUT connectors flush to the Front board. Solder only one pin each to allow for easy removal and making adjustments.
7. You can now solder the 3 terminal blocks to the Front board, facing away from the Front panel.
8. You can also add the 2.54mm male connector strips, they are used to connect the Front board to the Main board and the Front panel.
9. There are a number of test points, now is a good time to populate them.
10. Add the trim pots.
11. If you deviated from our BOM and used a ¼ inch shaft Step Delay potmeter with the switch (Pot 2), you will need to ream out the hole in the Front panel a small amount. Make it large enough so it slides easily in and out.
12. We can now start to add the parts that will determine the mechanical connection between the Front board and the Front panel.
The distance between the two boards will depend on the two tallest parts, the number-of-steps rotary switch, or the current range rotary switch. In my case, the number-of-steps rotary switch sets the minimum distance to 18.4mm, so that fixes my distance to 18.5mm between the two boards all around. It helps if you create a few studs with that exact distance to aid in the adjustment of the distance between the boards.
The distance of 18.5mm between the boards all around can now be measured/created and can be adjusted by the nuts of the toggle switches.
13. Mount the number-of-steps rotary switch first. The lock of the number-of-steps rotary switch S3 needs to be adjusted so that there are only 8 positions. Secure that well with a nut and tighten it. Position the Step selector rotary switch on the board. Be careful of the position and solder only the middle pin. It’s not easy to have it flush and vertically centered to the board so you may have to wiggle it to adjust it. Remember that this switch sets the minimum distance between the boards so make sure to solder it flush to the Front board.
14. Verify that the Current Range rotary switch S101 has been set to 6 positions. If not, remove the nut and the anti-slippage ring from the switch and check that the blocking ring of the switch is in position 6. Add the anti-slippage ring again and tighten the nut well. Verify that you now have 6 positions. Put the Current range switch in position on the bottom of the Front board and measure the height from the Front board to the top of the nut. It should be a bit less than 18mm. If it’s more than 18.5mm, you can use a fine file to remove up to 1mm from the four plastic stand-off pins. Solder only the center pin of the Current Range rotary switch so it is flush to the Front board but can still be easily removed.
15. We’re now going to add the toggle switches one by one so we can check and adjust the distance between the boards. The toggle switches have long solder lugs, so you can adjust the height above the Front board by the amount you let the switch “sink” into the holes of the PCB, while maintaining the spacing between the boards. To prepare, remove all rings and nuts from the toggle switches and then place just one nut about half way on the shaft. Use a caliper and fix it at 18.5mm.
16. Mount the Offset polarity switch S20 and the Y-Amp mA/Div toggle switch S70 to the Front panel. You should have already one nut on the shaft. Mount the two switches with a second nut on the Front panel such that the shaft still protrudes a fraction above the nut on the Front panel. This is only such that it is visually pleasing and there is enough room for the nut. Loosely tighten the nut on the other side, so the switch is in position but can still be moved and turned. You could use the anti-slippage rings on the back of the Face plate, see below, but they are not required.

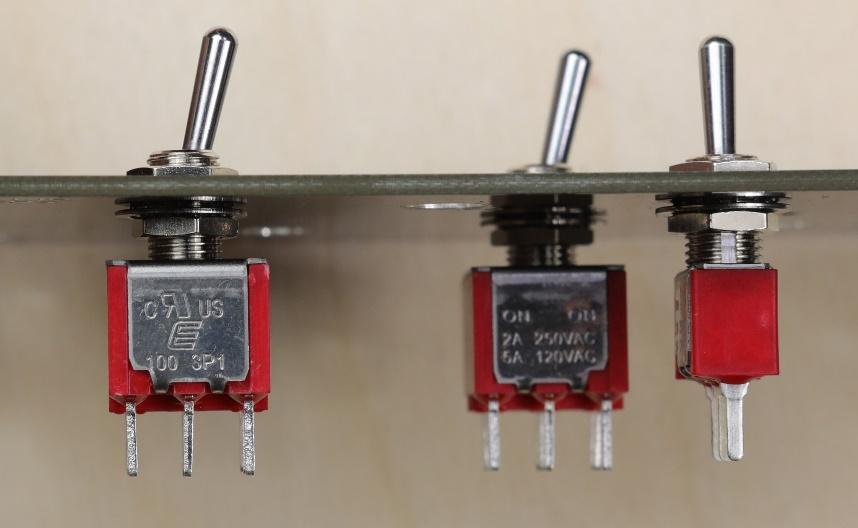
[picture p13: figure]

17. Put the Front panel on top of the Front board and position the two toggle switches so the pins fall in the holes of the Front board. While using a caliper or your studs, adjust the distance between the two boards by raising or lowering the solder lugs of the switches in the board. Start with the X-Amp switch and position it well. The end of the pins of the switch could be flush with the board. Solder only one pin of the switch in position. Soldering only one pin will allow you to readjust the 18.5mm distance between the boards. Do not rely on the amount the switches protrude through the board. It depends on the switch version and also tolerances. Measure the distance between the boards.
18. Now do the same with the Offset switch. Verify that the distance between the boards is still 18.5mm.
19. Remove the nuts from the two switches on the Front panel side and separate the two boards again. Make sure you keep the other two nuts on the switches undisturbed.
20. Mount the DUT selector toggle switch S71 and the Voltage Range selector switch S100 on the Front panel in the same way as the previous two. As before, put the Front panel in position on top of the Front board such that the pins of the two switches are in their respective holes on the PCB.
21. Verify the 18.5mm distance between the Front panel and the Front Board again and proceed to solder one pin of each switch to the Front board.
22. Remove the two nuts on the Front panel side of these switches and separate the two boards again.
23. Mount the Polarity switch S72 to the Front panel and adjust the height with the two nuts but keep them loose enough.
24. Put the two boards together again and position the Polarity switch. When the distance is 18.5mm, solder one pin. Remove the nut from the Front panel side.
25. Now add the BJT/FET and the Sweep/DC switches the same way, checking the 18mm and solder just one pin.
26. You can now also mount the Current and Voltage potmeters. You can remove the rings, but keep only one nut on the both potmeters. They are used to adjust the 18.5mm distance. Position and hold the potmeters flush to the board and solder one pin. Both potmeters can be soldered flush to the Front board.

27. Finally, you can mount the Step Output rotary switch S21. Because this switch does not have a stop, it does not really matter how you position it on the Front board. However, the bottom hole on the Front board is position 1 (the 50nA/50uV position), so you could position it using that way. It can be mounted rather flush to the board, but don’t bend the fragile pins. The total height of the switch is such that the shaft may not protrude enough through the Front panel to secure the knob. Raise the switch as much as possible from the bottom of the Front board while the pins are still protruding 0.5-1mm on the solder side to make good soldering possible. Solder only the center pin first. Leave the nut on this switch. It will be used to adjust the 18.5 mm distance.
28. Once you have all switches and potmeters soldered and positioned, you can now make a final adjustment of the sandwich before you solder everything permanently. Mount the two boards together and adjust all nuts on the switches and the Step Output rotary switch and Volt potmeter for a precise adjustment of the 18.5mm distance across all four sides of the two boards. If needed, you can now still reposition the depth of the switches in the Front board with a solder iron.
29. Once you are satisfied, you can go ahead and solder all the pins of the switches, the DUT sockets and the potmeters.
30. The Offset and Delay potmeters are mounted on the Front panel itself. The Step Delay potmeter has a locking pin. To secure the Offset potmeter, use the anti-lock ring between the potmeter and the Front panel to better secure it. Both parts will be connected to the Front Board by short wires. Note where the Tap pin of P20, the Offset potmeter goes to. Also note where the two pins of the switch from the Step Delay potmeter need to go to. With the potmeter in the fully CCW position, the switch should be closed.

However, if you decide to mount the special 5-turn potmeter, it will just about fit. If you lack the wiggle room, you may need to do a little bit more work. The fit is very tight, so I recommend that you drill the hole for the shaft with a 7.5mm drill, and use a counter-sink to clean the front of the hole, and widen the inside such that the little lip of the potmeter body falls inside the hole. This will give you an additional mm of play. Mount the potmeter with the solder lugs pointing to the left, towards the offset polarity switch. Check that you enough clearance from the solder points of C26, C30 and J1 on the other side. With the back of the potmeter pressed to the Front board, I now have 16.2mm between the boards which is enough.
31. Add a piece of shielded cable between pin 8 of S22 labeled B/G to pin 2 of S71, the DUT selector switch also called B/G. The cable should be grounded only on one end, you can use the large hole called ISO just below the B/G pin of the DUT switch. Use a bit of shrink tube to make sure the shield at the S22 side is covered.
32. The 2mm banana jacks are mounted on the Front panel and will be connected to the Front board through short wires. Make sure that the C and E wires can handle 2 Amps. Do not connect the wires and do not solder them to the Front board until you have verified the complete operation of the Curve Tracer, by using the Verification and Calibration document. Soldering these connections makes it much harder to take the Sandwich apart. We already implemented ferrites in the B/G connections to the DUT sockets on the front panel, but if you are planning to use longer leads connector to the 2mm banana jacks, you could add an optional ferrite bead (2x Wurth Elektronic p/n 782115020030, DigiKey p/n 732-782115020030-ND) on the B/G connection to stop some more hf signals coming into the instrument. The beads are listed in the OffPCBParts BOM.

Here is a picture of Maker Matt Web that built the CT:

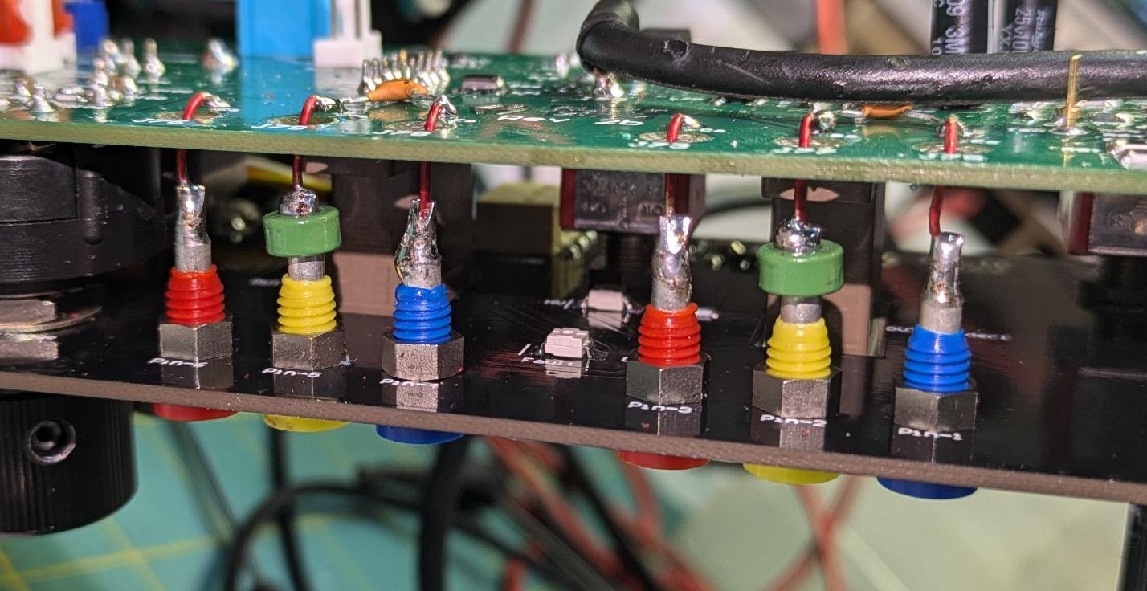
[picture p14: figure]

33. To make room for the sandwich in the plastic enclosure, use a sharp side cutter to remove the two most forward mounting studs on the bottom and top of the enclosure to make the sandwich fit. Note that the top cover can only be mounted one way because there are slots. The cover with the holes for the screws is the bottom of the enclosure.
34. The Pulse test point may interfere with the Main board when it is situated in the enclosure. You can bend the test point upwards a bit to create more room.

Below are two pictures of the finished sandwich. On top my version with knobs that came out of my stash, and the 2mm banana jacks I used for earlier prototypes. Below is the sandwich that Mark made with the knobs that are in the off-PCB parts BOM on the GitHub.

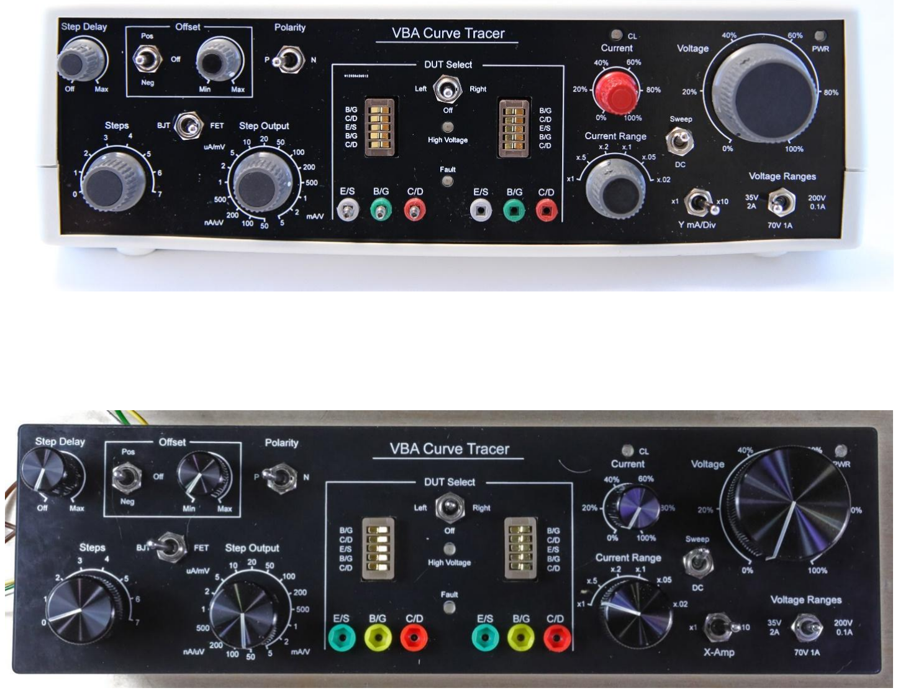
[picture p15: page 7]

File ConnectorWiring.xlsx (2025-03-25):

Bk-Black |  | Main Board |  |  | Front Board |  |  | Front Plate |  |  | Back Plate
Br-Brown | 3-Way |  | 24ga-17mm | 3-Way
R-Red | Slct 70 | J4-1 | Y | Slct70 | J104-1
O-Orange | Slct 35 | J4-2 | O | Select35 | J104-2
Y-Yellow | PlusTri | J4-3 | R | PlusTri | J104-3
Gn-Green | Sct 200 | J4-4 | W | Select200 | J104-4
Bl-Blue
P-Purple | DUTSupplyM |  | 18ga-17mm | DUTSupplyM
Gy-Grey | CS- | J6-1 | Bl | CS- | J70-1
W-White | GND | J6-2 | Bk | GND | J70-2
 | Step-DC |  | 22ga-17mm | Step-DC
 | - | J30-1 | P | - | J1-1
 | ISO | J30-2 | Gn | ISO | J1-2
 | + | J30-3 | W | + | J1-3
 | XY-DC |  | 22ga-22mm | XY-DC
 | + | J40-1 | R | + | J74-2
 | - | J40-2 | Bl | - | J74-2
 | Blanking |  | 24ga-30mm |  |  |  |  |  |  | Z
 | B | J51-1 | W |  |  |  |  |  |  |  | Z-Center
 | G | J51-2 | Bk |  |  |  |  |  |  |  | Z-GND
 | Sweep |  | 24ga-15mm | Sweep
 | Sw | J54-1 | Y | Sweep | J101-1
 | Ch | J54-2 | Br | Choice | J101-2
 | Trig-Pul |  | 24ga-22mm | Trig-Pul
 | ISO | J55-1 | Gn | ISO | J2-1
 | П | J55-2 | O | П | J2-2
 | VcSet |  | 24ga=17mm | VcSet
 | CCW | J102-1 | P | CCW | J102-1
 | CCW | J102-2 | P | CCW | J102-2
 | PWR/ILon |  | 24ga-22mm |  |  |  | PWR/ILon
 | - | J103-1 | Bl |  |  |  | minusTri | P2-1 | Use 216-101
 | G | J103-2 | Bk |  |  |  | GND | P2-2 | Ferrule on
 | Ilon | J103-3 | Y |  |  |  | Ilon | P2-3 | Wires
 | Ilimit |  | 24ga-15mm | Ilimit
 | TAP | J105-1 | Y | TAP | J100-1
 | 7V5 | J105-2 | R | 7V5 | J100-2
 | PWR/Fault |  | 24ga-22mm |  |  |  | Fault/HV
 | Hvon | J106-1 | Bl |  |  |  | CS- | P1-1 | Use 216-101
 | + | J106-2 | R |  |  |  | PlusTri | P1-2 | Ferrule on
 | FltOn | J106-3 | W |  |  |  | FaultOn | P1-3 | Wires
 |  |  |  | X-Hor |  | 24ga-30mm |  |  |  | X
 |  |  |  | X | J71-1 | Br |  |  |  |  | X-Center
 |  |  |  | GND | J71-2 | Bk |  |  |  |  | X-GND
 |  |  |  | Y-Vert |  | 24ga-30mm |  |  |  | Y
 |  |  |  | Y | J72-1 | Y |  |  |  |  | Y-Center
 |  |  |  | G | J72-2 | Bk |  |  |  |  | Y-GND

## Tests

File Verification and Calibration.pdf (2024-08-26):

### VBA Curve Tracer

### Verification & Calibration Procedure

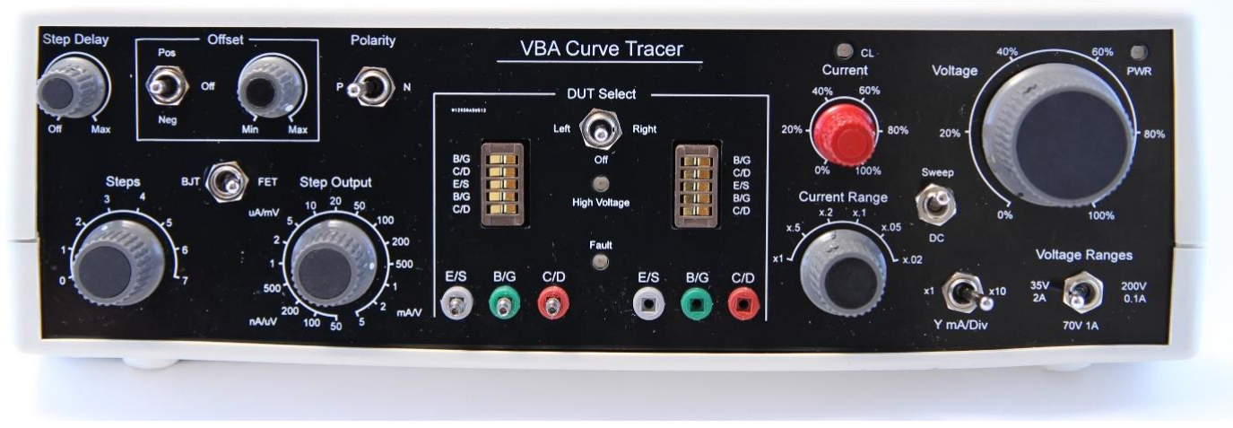
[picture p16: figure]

### 1. Preparation:

- What you need:
i. A 3.5 digit or better DMM with floating inputs to measure DC voltages up to 200V.
ii. An oscilloscope with a 10x probe. This can be a DSO or a CRT type. We’ll assume you’ll use a DSO for this procedure.
iii. A Phillips screwdriver to open up the enclosure.
iv. A small flat head screwdriver to adjust the calibration trimmers.
v. Two BNC cables to connect the Curve Tracer to the DSO. Three if you want to use the blanking signal from the Z-output when you are using a CRT scope. vi. A 1K 1% 0.5W THT resistor. (p/n is in the offPCBParts BOM)
vii. A 2K 1% 5W minimum THT resistor. (Or calibrate a set of resistors to a 2K0 value. A higher wattage is recommended.) (p/n for a 10W version is in the offPCBParts BOM)

### 2. First power on:

- Make sure that you have selected the right mains voltage (230V or 115V)
- If you just built the instrument and have verified the most important signs of life, you can perform a full functionality test and initial calibration with this procedure.
- Turn off the power to the instrument and remove the mains lead.
- To get access to test points, you may want to lengthen or extend the interconnect cables between the Sandwich and the Main board by using Dupont style male-female leads for the following connectors on the Main board:
i. Use longer leads (that can carry 2A+) to connect the DUT power wires from J6 ii. The 3-way volt selector, J4 iii. The VcSet potmeter, J102
iv. The Fault/HV signals from J106
v. The Fault/Led signals from J103
vi. The current limit circuit from J106
- The other leads should be long enough, if not, you can extend them also.
3. When you already have a functioning Curve Tracer:
- Turn off the power to the instrument and remove the mains lead.
- Take the cover off the instrument by removing the 4 screws from the bottom. Do not put it fully upside down, just place it on one side or keep it upright while removing the screws because the Face Plate/Front Boards may fall out. When the screws are removed, put it back on its feet and remove the top cover to get access to the PCB’s in the instrument.

### 2. Get started

- Inside the instrument, when powered, there will be lethal voltages present, not only mains related. Take care not to touch the components. Use only one hand and keep the other in your pocket when you need to attach probes and adjust trimmers. If in doubt, disconnect power first and then connect probes and test leads to hard-to-get places.
- Set all trimmers on the Main Board and the Front Board in the mid position.
- On the front panel:
i. Set the Step Delay function to off (turn CCW to the off indent).
ii. Set the Offset switch in the off position.
iii. Turn the Offset Adjustment to Min.
iv. Set the Polarity switch to N.
v. Set the device type switch to FET.
vi. Set the Step Output to 1mA/1V. vii. Set the Steps to 7.
viii. Set the DUT selector switch to off. ix. Set the Current adjustment to 100%.
x. Set the Current ranges to X1.
xi. Set the Sweep/DC output to Sweep. xii. Set the Y-Amp to X1.
xiii. Set the Voltage Ranges to 35V/2A.
xiv. Set the Voltage adjustment to 50%.
- On the back panel:
i. Remove all cables to the three BNC connectors to avoid an earth ground connection short while we make some adjustments. Only add the BNC cables when instructed.

- Note that when you switch to another Voltage range, the High Voltage and the Fault indicator may come on for a very short period. This is normal and shows that the protection circuits are working.

### 4. Check some of the vital signs

- Connect the mains cable and turn the instrument on.
i. Check that the green power light is on.
ii. Check that the red Current Limit indicator LED is off. iii. Check that the red High Voltage indicator LED is off.
iv. Check that the blue Fault indicator LED is off.
- Use a DMM to test the rails
i. Connect the negative input of the DMM to an ISOGND test point (TP). ii. Check the +15V supply (+/- 2%) on the plusStep test point.
iii. Check the -15V supply (+/- 2%) on the minusStep test point.
iv. Connect the negative input of the DMM to a GND test point.
v. Check the +10V supply (between 9.9 and 10.1V) on the plusTri test point, the value will be calibrated later.
vi. Check the -5V supply (+/-2%) on the minusTri test point.
vii. Check the +24V supply for a voltage between 22V and 26V on the xyPlus test point.
viii. Check the +7.5V supply for a voltage of 7.5V (+/-2%) on the 7.5V test point. ix. Connect the negative input of the DMM to the TransM test point.
x. Connect the positive input of the DMM to the TransP test point.
xi. Check for the presence of a DC voltage between 42V and 46V.
xii. Select the 70V range and check for a voltage between 80 and 90V.
xiii. Select the 200V range and check for a voltage between 220 and 240V.
xiv. Select the 35V range.
xv. Measure the voltage between test point TransMinus and the metal part of the heatsink (connected to the Collector) of the Current Source transistor Q91. The voltage should be about 120-130mV indicating a current of between 12 and 13mA.
xvi. Disconnect both DMM leads from the instrument.
- Use a DSO/CRTO to test the Step Gen
- Warning:
The instrument by itself is floating from Earth ground. Do not use a DSO or CRT oscilloscope with probes to measure points inside the enclosure when you also have BNC cables connected to the instrument. Connecting the ground clip of the probe can cause a short due to the different ground systems.
i. Set the DSO time base to 2ms/Div. and CH1 Vertical to 5V/div.

ii. Connect a single X10 scope probe with the tip to the TransM test point and the ground clip to test point marked GND both on the Main board.
iii. Check for a negative going triangle waveform on the DSO of approx. -20Vp-p or 4 divisions.
iv. While changing the Voltage adjustment between 25% and 75%, verify that the amplitude changes. Return the Voltage setting to 50%.
v. Disconnect both probe connections.
vi. Set the DSO time base to 10ms/Div. and CH1 to 2V/Div.
vii. Connect a single scope probe with the tip to test point BuffStep and connect the ground clip to an ISOGND test point on the Front board. Set the ground indicator of the DSO to the first line of the graticule from the bottom. Adjust the trigger for a stable display.
viii. Check for a positive going step waveform with 7 steps relative to ground.
ix. Set the time base to 20ms/Div. Enable the Step Delay by rotating the adjustment to 100%.
x. Verify that there is about a 120ms period between two full step cycles. You may have to select a single shot trigger or freeze the acquisition to get a stable display.
xi. Turn the Step Delay fully CCW to the off position.
xii. Set the DSO time base to 10ms/Div. and CH1 to 5V/Div. Set the GND indicator of CH1 to the center graticule line.
xiii. Select the BJT mode.
xiv. Connect a 1K resistor between one of the Base DUT sockets and the Emitter socket on the front panel. The 1K resistor will convert the Base current into a voltage that is easier to see on the DSO. This is what we do in the FET mode as well to get a Gate voltage, but the FET offset circuit is different.
xv. Clip the probe tip to the Base and the probe ground to the Emitter. Select that DUT socket.
xvi. Select the Positive Offset and turn the Offset Adjustment from Min to Max. Observe that the waveform goes positive in relation to ground. When you measure the voltage at testpoint BuffStep, the waveform will start to clip at about 14V. When you measure across the 1K resistor, the clipping will be at around 7V with the Step size at 1V/Step and 7 steps. Set the Offset Adjustment back to Min.
xvii. Change the Offset to Neg. Observe that the waveform now goes negative from ground with the Offset Adjustment going from Min to Max. The waveform will start to clip at about -14V measured at testpoint BuffStep.
xviii. Set the Offset to off and the Offset Adjustment to Min.
xix. Change the device Polarity switch from N to P and check that the step waveform is now going negative from ground.

xx. Select the Positive Offset and turn the Offset Adjustment from Min. to Max. Observe that the waveform goes positive in relation to ground. The waveform will start to clip at about +14V. Set the Offset Adjustment back to Min.
xxi. Change the Offset to Neg. Observe that the waveform now goes negative from ground with the Offset Adjustment going from Min to Max. The wave form will start to clip at about -14V.
xxii. Note that the offset travel in the BJT mode is depending on the Step Output setting. The travel will be lower in the lower Base current settings.
xxiii. Select the FET-mode and verify that the offset has a maximum of +/-2V regardless of the Step Output voltage settings.
xxiv. Set the Offset to off, the Offset Adjustment to Min. and the device Polarity back to N.
xxv. Disconnect the probe connections.
- With the above steps, we have verified the functionality of several critical functions. We can now proceed to calibrate the instrument and verify the remaining functions.

### 5. Calibration of the +10V supply

- This supply is used as a reference for several settings and functions in the instrument.
- Changing this supply will require a complete re-calibration.
- At this point, the instrument has warmed up so we can perform this calibration.
- Connect a DMM between TP plusTri and a TP called GND on the Main board.
- Adjust trimmer Pot10 on the Main board for a reading of 10.00V. When needed, you can install a parallel resistor R12 to the trimmer to reduce the range.

### 6. Check the Current Limit indicator operation

- Select the X.02 Current range on the Front panel.
- Turn the Current adjustment to 0% (no current) and check that the Current Limit (CL) indicator LED comes on.
- Set the Current adjustment back to 100% and select the X1 Current range.

### 7. Verify the triangle operation

- Set the DSO time base to 2ms/Sec and CH1 to 2V/Div.
- Connect a DSO probe between the Tri test point and GND on the Main board.
- Obtain a stable display.
- The triangle waveform should have a minimum of 7.6Vp-p.
- Switch from the Sweep mode to the DC mode with the switch on the front panel.
- Connect the DSO probe or a DMM to test point TRI-DC.

- Verify that you now have a DC voltage of about +7.5V.
- Switch back to the Sweep mode.

### 8. Calibration of the base frequency

- This will set the triangle frequency and also determines the refresh rate of the DSO display.
- With the same settings as in the previous step, adjust trimmer Pot52 for a frequency of about 170Hz or about 3 divisions between two of the top or bottom peaks of the waveform.
- Disconnect the probe.

### 9. Calibrate the Step Gain

- Set the DSO time base to 10ms/Div. and CH1 to 1V/Div.
- Set the GND indicator of the scope to the lowest graticule line.
- Connect a DSO probe with the pin to the Base and the Ground clip to the Emitter of the left DUT or 2mm sockets. To connect the probe, you can insert two pieces of wire (or resistors) into the DUT socket, or use the 2mm banana sockets.
- Select the left DUT socket.
- Check that you have a positive going stepped waveform with an equal distribution of the seven steps.
- With the CH1 Vertical Position of the DSO, adjust the first step (not the bottom) of the waveform to the first graticule line of the DSO.
- Adjust the 1V/Step trimmer Pot1 on the Front board for 1V per step, or the top at 7Vp-p.

### 10. Calibration of the 200V Supply

- Connect a scope probe with the tip to the C/D DUT output using a wire into the DUT connector, or use the 2mm banana connector. Connect the GND clip to the E/S connection of the DUT socket with a wire or use the 2mm banana connector.
- Set the DSO time base to 2ms/Div and CH1 to 10V/Div.
- Using the CH1 Position adjustment, move the ground indicator of the DSO to the first graticule line from the bottom.
- Trigger on the waveform and observe that you have a positive going triangle waveform of about 15-20Vp-p with the Volt potmeter at the 50% mark.
- Change the CH1 Vertical input to 10V/Div.
- Set the Voltage adjustment to 100% and observe that you now have a wave form with an amplitude between 30 and 40Vp-p.
- Set the DSO CH1 Vertical input to 20V/Div. and select the 70V range.
- Observe that the high voltage warning indicator on the front panel is on.
- Observe that you have a waveform between 70 and 80Vp-p.

- Set the DSO CH1 Vertical input to 50V/Div.
- Select the 200V Volt range and use the trigger adjustment to get a stable display.
- Observe that you have a triangle waveform of about 190-220Vp-p.
- Make sure that the Voltage adjustment and the Current adjustments are both at 100%.
- Adjust the 200V trimmer Pot 101 on the Main board such that you have an amplitude of 200Vp-p.
- Disconnect the probe.

### 11. Verification and calibration for the full 100mA budget at 200V

- This calibration will cancel out all currents occurring in the circuits, like the 12.5mA Current Source, to create a net 100mA setting in the 200V range.
- Set the DSO time base to 2ms/Div.
- Set CH1 of the DSO to 200mV/Div.
- Connect a DSO probe to a GND test point on the Main board and the tip to test point Vcur on the Main board.
- Set the DUT selector to off.
- Install a 2K 5W resistor between C-E on one of the DUT 2mm banana sockets.
- Select the 200V range, set the voltage to 100%.
- Set the Current adjustment to 100%.
- Select the X1 Current range.
- Note: The 2K resistor will get hot, so limit the time with full current. Be careful not to touch the resistor leads to test the temperature. 200V is present!
- Select the proper DUT socket.
- Observe that you have a triangle waveform of about 1Vp-p.
- Adjust the Current Null trimmer Pot103 on the Main board so the top of the waveform is just not clipping. If there is no clipping, it means that you have the full 100mA available in the 200V setting.
- Verify that the CL LED is off.
- Slowly reduce the Current adjustment to 0% and observe that the top of the triangle becomes a straight line going down to almost 0V (about a minor division).
- Verify that as soon as you reduce the setting away from 100%, the CL LED comes on.
- Switch the DUT selector to the off position.
- Select the 70V range.
- Turn the Current potmeter to 0% and verify that the CL LED is on. If not, turn Pot103 a little bit clockwise so the CL LED is just turning on.
- Select the 35V range and verify that the CL LED is on.
- Let the 2K resistor cool off and remove it.

### 12. Calibration of the 70V Supply

- Connect a scope probe with the tip to the C/D DUT output using a wire into the DUT connector, or use the 2mm banana connector. Connect the GND clip to the E/S connection of the DUT socket with a wire or use the 2mm banana connector.
- Select the 70V Volt range.
- Set the DSO CH1 Vertical input to 20V/Div.
- Adjust the trigger such that you have a stable triangle waveform.
- Adjust the 70V trimmer Pot 100 on the Main board such that you have an amplitude of 70Vp-p.
- Leave the DSO probe attached.

### 13. Verify the High Voltage indicator tripping point

- Turn the Voltage down to 25%.
- Increase the Voltage until the High Voltage indicator LED starts to glow. Verify that the voltage is at least 40Vp-p. Further increasing the voltage will also increase the intensity of the LED, which will reach the maximum intensity at about 60V.
- Turn the Voltage up to 100%.
- Leave the DSO probe attached.

### 14. Calibration of the 35V Supply

- Select the 35V Volt range.
- Set the DSO CH1 Vertical input to 5V/Div.
- Adjust the trigger such that you have a stable triangle waveform.
- Adjust the 35V trimmer Pot 102 on the Main board such that you have an amplitude of 35V.
- Turn the voltage down to about 10Vp-p.
- Leave the DSO probe attached.

### 15. Verify and calibrate the DC mode

- Select the DC Mode on the front panel.
- Note that the triangle waveform is now a DC voltage with an amplitude of about 10V.
- Set the Voltage to 100% and verify that the DSO shows 35V +/- 5%.
- Set the DSO CH1 Vertical input to 20V/Div.
- Select the 70V range
- Verify that the DC level is 70V +/- 5%
- Set the DSO CH1 Vertical input to 50V/Div.
- Select the 200V range
- Verify that the DC level is 200V +/- 5%
- Select the Sweep mode, select the 35V range and set the Voltage to 20%.
- Disconnect the scope probe from the test points

- Remove the DSO X10 probe from the CH1 input channel of the DSO.

### 16. Calibrate the Zero level for the triangle waveform

- Make sure you are in the 35V range.
- Connect a BNC cable between the Horizontal (X) output connector of the instrument to CH1 of the scope.
- Make sure you do not have a scope probe connected to the instrument anymore.
- Set the time base of the DSO to 1ms/Div. and set CH1 to 5V/Div. and obtain a stable display.
- Move the ground indicator of the DSO to the first graticule line from the bottom of the display.
- Check that the input multiplier of the DSO CH1 is still 10X.
- Verify that you have a triangle waveform on the display that is going positive in reference to ground and adjust the Voltage adjustment so you have a wave form of about 6 divisions (at about 80%).
- Look at the bottom peaks of the wave form in relation to the ground indicator. It should be on or near zero Volt to this indicator.
- Calibrate the lower peaks of the waveform with the 0V Adjust trimmer located on the Main board so they are at or not more than a fraction of a minor division above the ground level of the DSO.
- Going below the ground level will distort the wave form, keep it on or just above the ground level. Adjust CH1 to 2V/Div so you can see this in more detail when needed. The integrity of the triangle waveform transitions is very important.
- Set the DSO CH1 back to 10V/Div. and the time base to 1ms/Div.

### 17. Calibrate the gain of the horizontal (X) Amplifier

- Select the 35V range. Set the Voltage adjustment to 100%.
- Verify that you have the X-Chan output of the CT connected to CH1 of the DSO with a BNC cable.
- Disconnect the Y-Chan BNC cable to CH2 of the DSO.
- Set CH1 and CH2 both to 5V/Div. and invert CH2.
- Position both CH1 and CH2 GND indicators at the lowest graticule line.
- Set the Time-Base to 1ms/Div.
- Be careful with this step, because it is counter intuitive!
Connect CH2 of the scope with a 10x probe with the tip to the DUT E/S connection, and the ground clip to the C/D connection. If you make a mistake and reverse the probe connections, you will short the output of the DUT supply.
- The two waveforms are about the same size and will almost overlap.
- Adjust the H Gain (horizontal gain) trimmer of the X amplifier Pot 70 on the Front board to make both waveforms overlap so they are exactly the same.

- This will calibrate the Collector supply voltage output level with the DSO in a 1:1 ratio with the 10X setting of the DSO input channel. (so 1V of the DUT supply is also 1V of deflection on the DSO)
- Disconnect the 10x probe from the DUT and also from the scope. Remove the inverting of CH2.

Verify the 1/10 current multiplier for the vertical (Y) Amplifier
- Connect a second BNC cable between the Vertical (Y) output connector of the instrument to CH2 of the DSO. This will display the current through the DUT.
- Set the Y-Amp gain on the Front panel to X1. This is the large current setting. You should now also should select the 1X Ratio multiplier for the CH2 input channel. The Y-channel multiplier setting goes hand-in-hand with the CH2 Ratio setting to keep 1V = 1A
- Set the DSO vertical of CH1 to 5V/Div. and CH2 to 5mV/Div.
- Set both ground indicators to the first graticule from the bottom.
- Verify that the CH2 horizontal line is level with the ground indicator of the scope. If not, adjust the offset trimmer Pot71.
- Install a 1K 1% 0.5W resistor between the C/D and E/S terminals on the DUT connector. Keep the DUT selector to off.
- Adjust the CT Voltage so that you have a wave form of 6 divisions, or 30V (at about 80%).
- Select the DUT socket with the resistor. Both channels should now have voltage and current waveforms that are virtually the same and will overlap, plus or minus a minor division. (5V/1K=5mA/Div)
- Set CH2 to 50mV/Div. and select the .1x Ratio multiplier. This multiplier setting goes hand-in-hand with the setting for the Y mA/Div to keep the V/div or rather the A/Div correct of the DSO the same.
- Select the X10 multiplier for the Y mA/Div on the Front panel.
- Verify that the waveform is again 6 divisions plus or minus a minor division. They should still virtually overlap.

### 18. Verify the correct operation of the Current Limiting

- Set CH1 to 2V/Div., and CH2 to 100mV/Div.
- Set the Y-Amp to X10. Remember that you now also should select the X1 multiplier of the CH2 input. This multiplier setting goes hand-in-hand with each other to keep the V/div or rather the A/Div correct.
- Select the X.05 Current range.
- Set the DUT selector to off.
- Install a 2K 5W or 10W resistor in the left DUT socket between C-E.
- Select the DUT side where the resistor is mounted.
- Select the 35V range and set the Voltage so you have a CH1 wave form of 6 divisions on the DSO

- Both CH1 and CH2 displays should be close in size, and virtually overlap.
- Adjust the Current such that the triangle waveform will just be clipping and the CL LED comes on to signal that. Adjust the Current (10%) so you have display of three divisions.
- Note that both DSO channels show a clipped triangle waveform with a gradual change (almost a dome) without any under- or overshoot in the transitions from the triangle to the clipping (limiting) portion. (the dome shape, not a flat line, is caused by the very low amount of current <2mA in this Voltage range)
- Select the 70V range and adjust the Current adjustment (30%) to have three divisions again. Observe that the corners will get sharper and the limiting line flatter.
- Select the .2 current range.
- Select the 200V range and adjust the current adjustment (50%) to have three divisions again. Observe that the corners will be sharp, but without glitches, over- and undershoot and a straight limiting line.
- Select the off position for the DUT selector.
- Select the X1 position for the Current range, the X1 position for the Y-amplifier and the X1 multiplier for CH2.
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

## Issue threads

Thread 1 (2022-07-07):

Gerbers for front panel rev2b not working

da6353, 2022-07-07:
Gerbers for front panel rev2b not working:

1.) board mfg unable to determine overall board size
2.) gerberviewer shows corrupt top/bottom layer, see attached images

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

paulvee, 2022-07-08:
We order all the boards from PCBway.

I just tried the Front panel and the Back panel with their viewer and another one and I have the same problem.
The Front board and the Main board are OK
We'll look into it and update the Github

Closed 2022-07-17.

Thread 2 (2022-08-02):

Does Anyone have a set of PCB's for sale?

robotwizard, 2022-08-02:
I'm in USA. If you have a set of PCB's please send price and shipping cost. Thanks

somewhatklonkish, 2024-07-20:
07/20/2024
There's a guy (Dewey/Watchmaker) on this thread , post 37, that has 1 board set left.
https://www.eevblog.com/forum/projects/building-a-diy-curve-tracer/msg5570059/#msg5570059

Closed 2025-08-13.

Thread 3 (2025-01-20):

Do you update the shared projects at PCBWAY when relevant changes are made here?

abitofhelp, 2025-01-20:
Hello,

I am excited about the VBA Curve Tracer and saw the shared projects at PCBWAY.
Do you keep those shared projects current with design, bom, etc., updates here, or would I want to use the content here to create my projects at PCBWAY?  I'd compare my project configurations against your shared projects before ordering.

Thank you for such a great project!

Mike

paulvee, 2025-01-21:
Hi Mike,
Yes, I try to keep the data at the shared project section of PCBWay current as much as possible, this mostly concerns the BOM's.
Several Makers have ordered the boards through PCBWay and even had them stuffed.
Some others prefer JLCPCB.
All the feed-back I got from the two boards houses and the Makers where used to improve the information.

If you find anything that can improve the data, please feel free to let me know.

Success with this exciting project!

Paul

Closed 2025-01-21.

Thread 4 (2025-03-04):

Front panel and Front board Construction-Installation Instructions.pdf correction?

russgmoore, 2025-03-04:
Step 31 indicates a ground shielded cable between pin "5" labeled B/G on S22 and pin 2 on S71 also labeled B/G.
S22 pin 5 is defined in the board view as ISO and pin 8 defined as B/G.

I am proceeding to install the cable to pin 8 on S22 as the diagrams appear to be correct and step 31 in error.

paulvee, 2025-03-06:
Hi Russ(?),
After all those years, you indeed found an error in the instructions.
Thank you for pointing it out so I could fix it.
The new file with the fix (actually there were two) is uploaded.
Success with your build and enjoy working with the instrument.
Paul

Closed 2025-03-06.

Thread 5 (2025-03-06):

Front panel and Front board Construction-Installation Instructions.pdf

russgmoore, 2025-03-06:
Step 30
C27, C30 and J1 are mentioned for clearance but I believe you mean C26, C30, and J1

I'm very close to finishing and very excited to see all of your work in action.

paulvee, 2025-03-07:
Hi Russ,
Yes, you found another one. I fixed it in the instructions.
FYI, these issues were all caused when we went to a last-minute layout change after I already finished the instructions. We normally didn't change the part names, but this time, Mark did, so I missed a few required corrections. Sorry!
But, I know you will enjoy working with the instrument when you have finished building it.
Success,
Paul

Closed 2025-03-07.

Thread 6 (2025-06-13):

error in BOM BOM-MB-Rev2f

clytle374, 2025-06-13:
In line 28
2 | 1,1 | R2, R6 | RES 301K OHM 1%   1/4W 0805 | 301K | RESC2012M | Stackpole   Electronics | RMCF1206FT301K | Digi-Key | RMCF1206FT301KCT-ND |  

Both the manufacture's part number and Digikey's both indicate a 1206 part.

The description states 805, and the PCB also looks to be 805.

paulvee, 2025-06-17:
The BOM indeed has an error, these are indeed 0805 parts.
The BOM will be fixed soon. Thank you for pointing it out!

clytle374, 2025-06-17:
No problem, thanks!

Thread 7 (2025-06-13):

error in BOM BOM-FB-Rev2i

clytle374, 2025-06-13:
In line 9

1 | C41 | CAP CER 1NF   250V X7R 0805 | CAPC2012M | 1nF | KEMET | C1206C102KAGECAUTO | Digi-Key | 399-17177-2-ND |  

Both the manufacture's part number and Digikey's both indicate a 1206 part.

The description states 805, and the PCB also looks to be 805.

paulvee, 2025-06-17:
The BOM indeed has an error, this is indeed an 0805 part.
The BOM will be fixed soon. Thank you for pointing it out!

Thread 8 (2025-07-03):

Request for manual clarification

clytle374, 2025-07-03:
Working through main board construction & installation PDF

Step 11: check for shorts:  what should be the ohms?  One is like 700 ohms and some are way more.

Step 17: connect power to J2:  is this correct? Or should it say J3?  J3 is the line power connector.  If J2 is correct, it has 4 pins. Which pins should be connected?

Thanks!

clytle374, 2025-07-03:
If you don't install some of the the hole caps before step 20 the voltages are crazy.  After installing the caps in this section the voltages were good.

paulvee, 2025-07-03:
Cory,
Step 11: you should be testing for solder blob shorts, there are way too many possibilities to show an Ohm value. If it's below 10 Ohm you can be assured that it's an unwanted short.
Step 17: There was a mistake, it's indeed J3.
Step20: I added a check.
Step 37: I added a reference to the picture "Above from Back.jpg" to clarify some details of the wiring.
The instructions are updated.
Thanks for reporting.

Closed 2025-07-03.

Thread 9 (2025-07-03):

Mistake is front panel bom

clytle374, 2025-07-03:
In the front panel bom digikey part #8
754-1533-1-nd
Is not a bottom firing LED
Sorry to keep bringing things up, but hopefully it helps some else

paulvee, 2025-07-03:
It is the correct LED. It looks different because SunLED does not have the blue color for this type of LED.
I added a comment to the BOM.

clytle374, 2025-07-03:
I have it on leads kinda deadbug style to get it pointing the correct way

clytle374, 2025-07-09:
I found a bottom firing LED that fits, and the specs says it will work.

led blue 2smd bottom firing.  PART # VLDB1232R-08
Digikey PART # 751-VLDB1232R-08CT

The on in the BOM has to be mounted on leads and dead bugged over the hole to make it fire downward

> It is the correct LED. It looks different because SunLED does not have the blue color for this type of LED. I added a comment to the BOM.

paulvee, 2025-07-09:
Thank you Cory. I ended-up asking Mark what he used, because the BOM may be in error, but I have no way of finding that out or verifying it. The one I used is physically the same as the others, so something is wrong.
FYI, Mark is the one that designed the PCB's and was responsible for the BOM.
I hope to hear from him soon.
Paul

clytle374, 2025-07-10:
This is the part you get from the current BOM

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

paulvee, 2025-07-10:
Cory,
I double checked with Mark, and were are absolutely sure we have the correct part in the BOM.
When I go to Digikey and look at the part we have in the BOM, I get this:

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

I don't know where you get your part or that picture from, but this is definitely not the version we use in the CT.
Sorry...

clytle374, 2025-07-10:
Wow, sorry about that.  I have the bad part number on the bom I printed out, but not on the file in my computer.

I must have done something careless with copy and paste at work when I printed it at work.  My apologies.

But that doesn't explain how I ordered the wrong part.  As I did that at home,  I'll add that to the long list of things I cannot understand.

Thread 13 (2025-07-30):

TP TRI-DC not found

clytle374, 2025-07-30:
In verification and calibration:
step 7
"Connect the DSO probe or a DMM to test point TRI-DC."

I can't find a TRI-DC.  The only thing with the requested 7.5V is the 7.5V TP

I see it as TP-101 in the schematic, but not sure where it is.

Thanks

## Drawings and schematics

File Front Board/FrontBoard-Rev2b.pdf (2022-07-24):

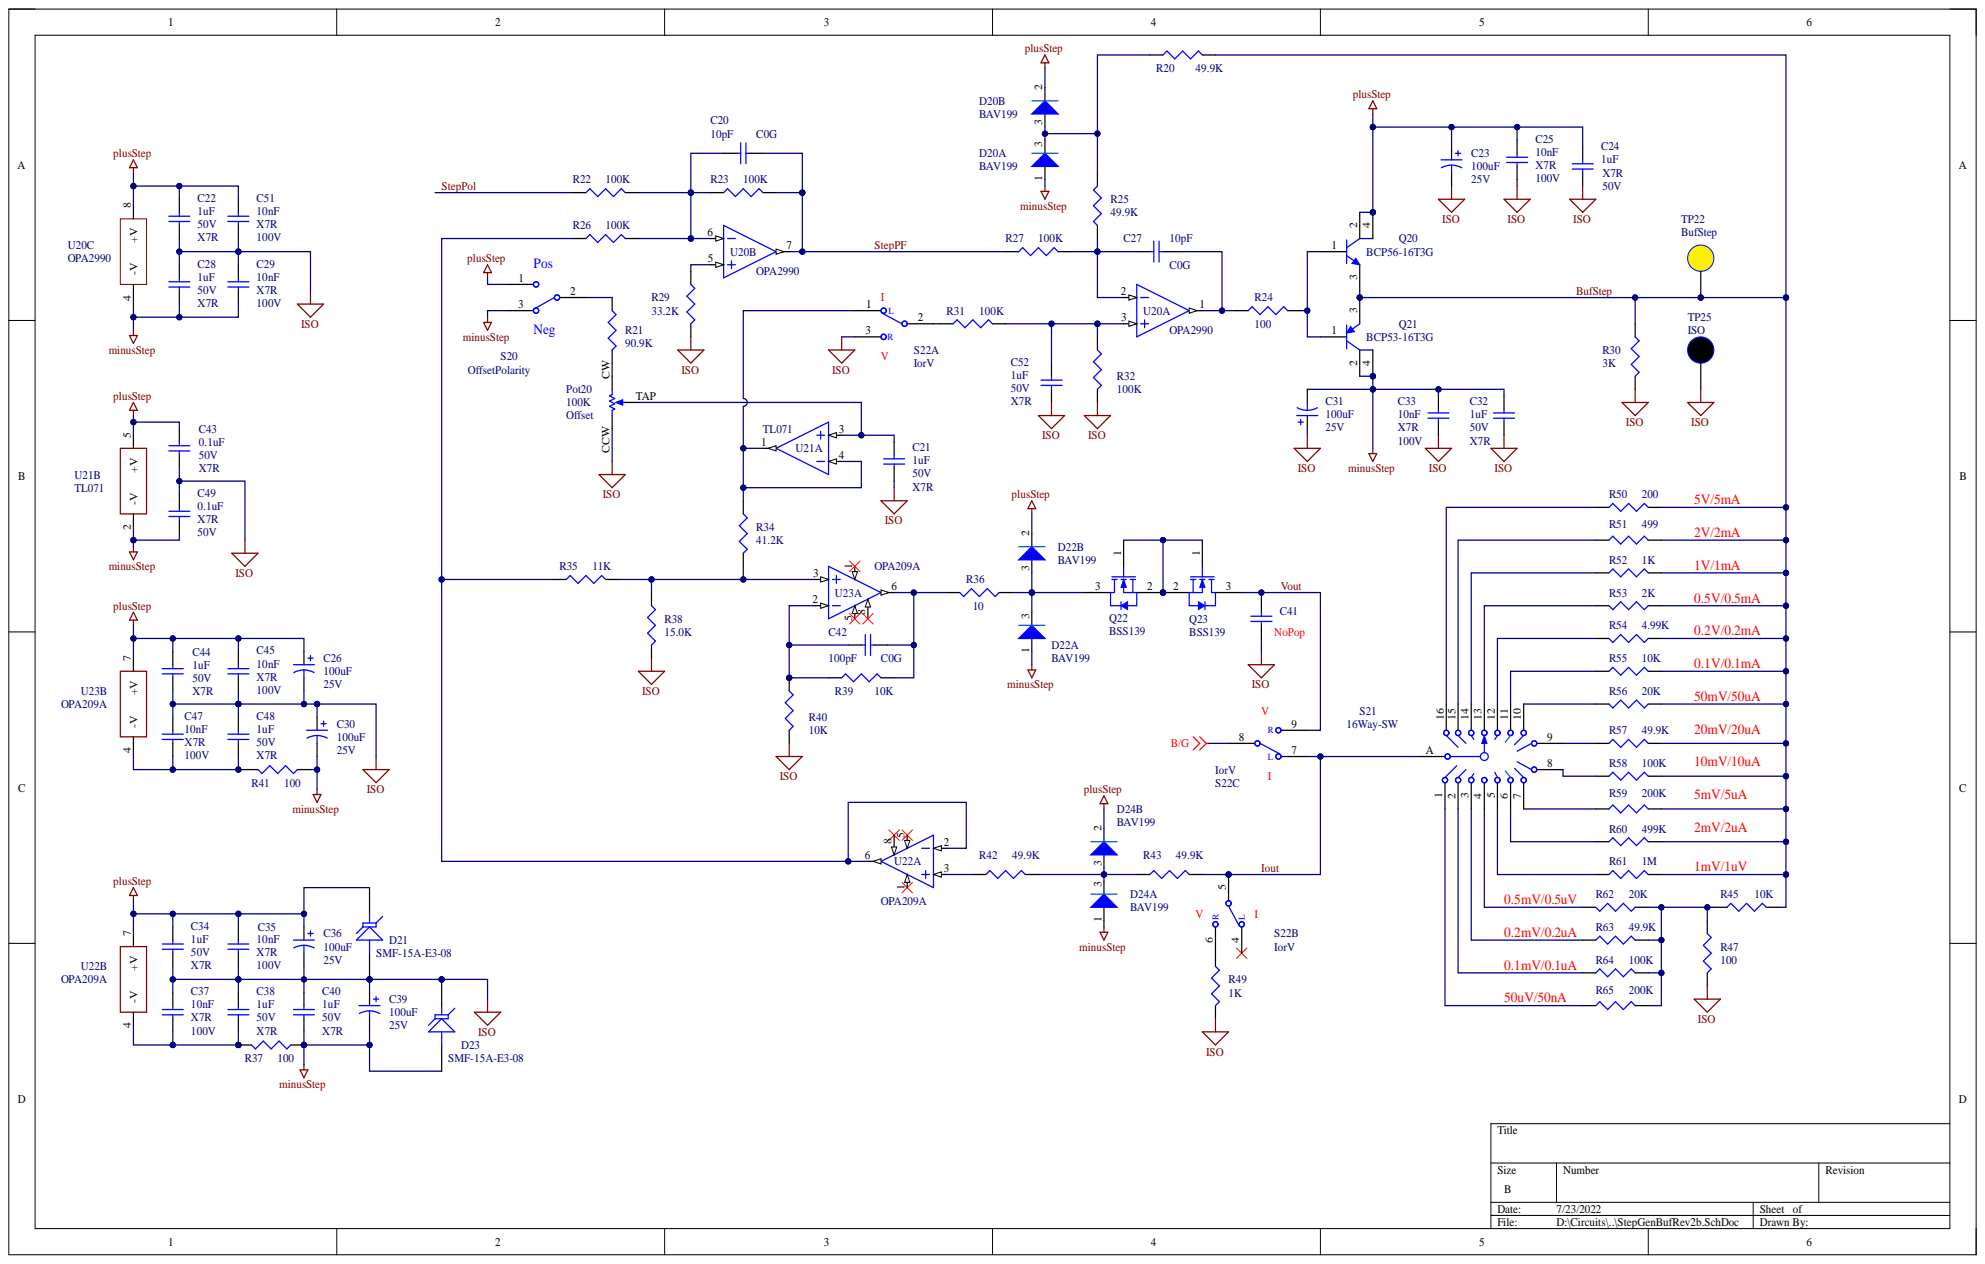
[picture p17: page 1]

Size B | Number | Revisio n

Date: 7/2 3/2 0 2 2 | Sheet o f
File: D:\Circuits\..\StepGenBufRev 2 b.Sch D o c | Drawn By :

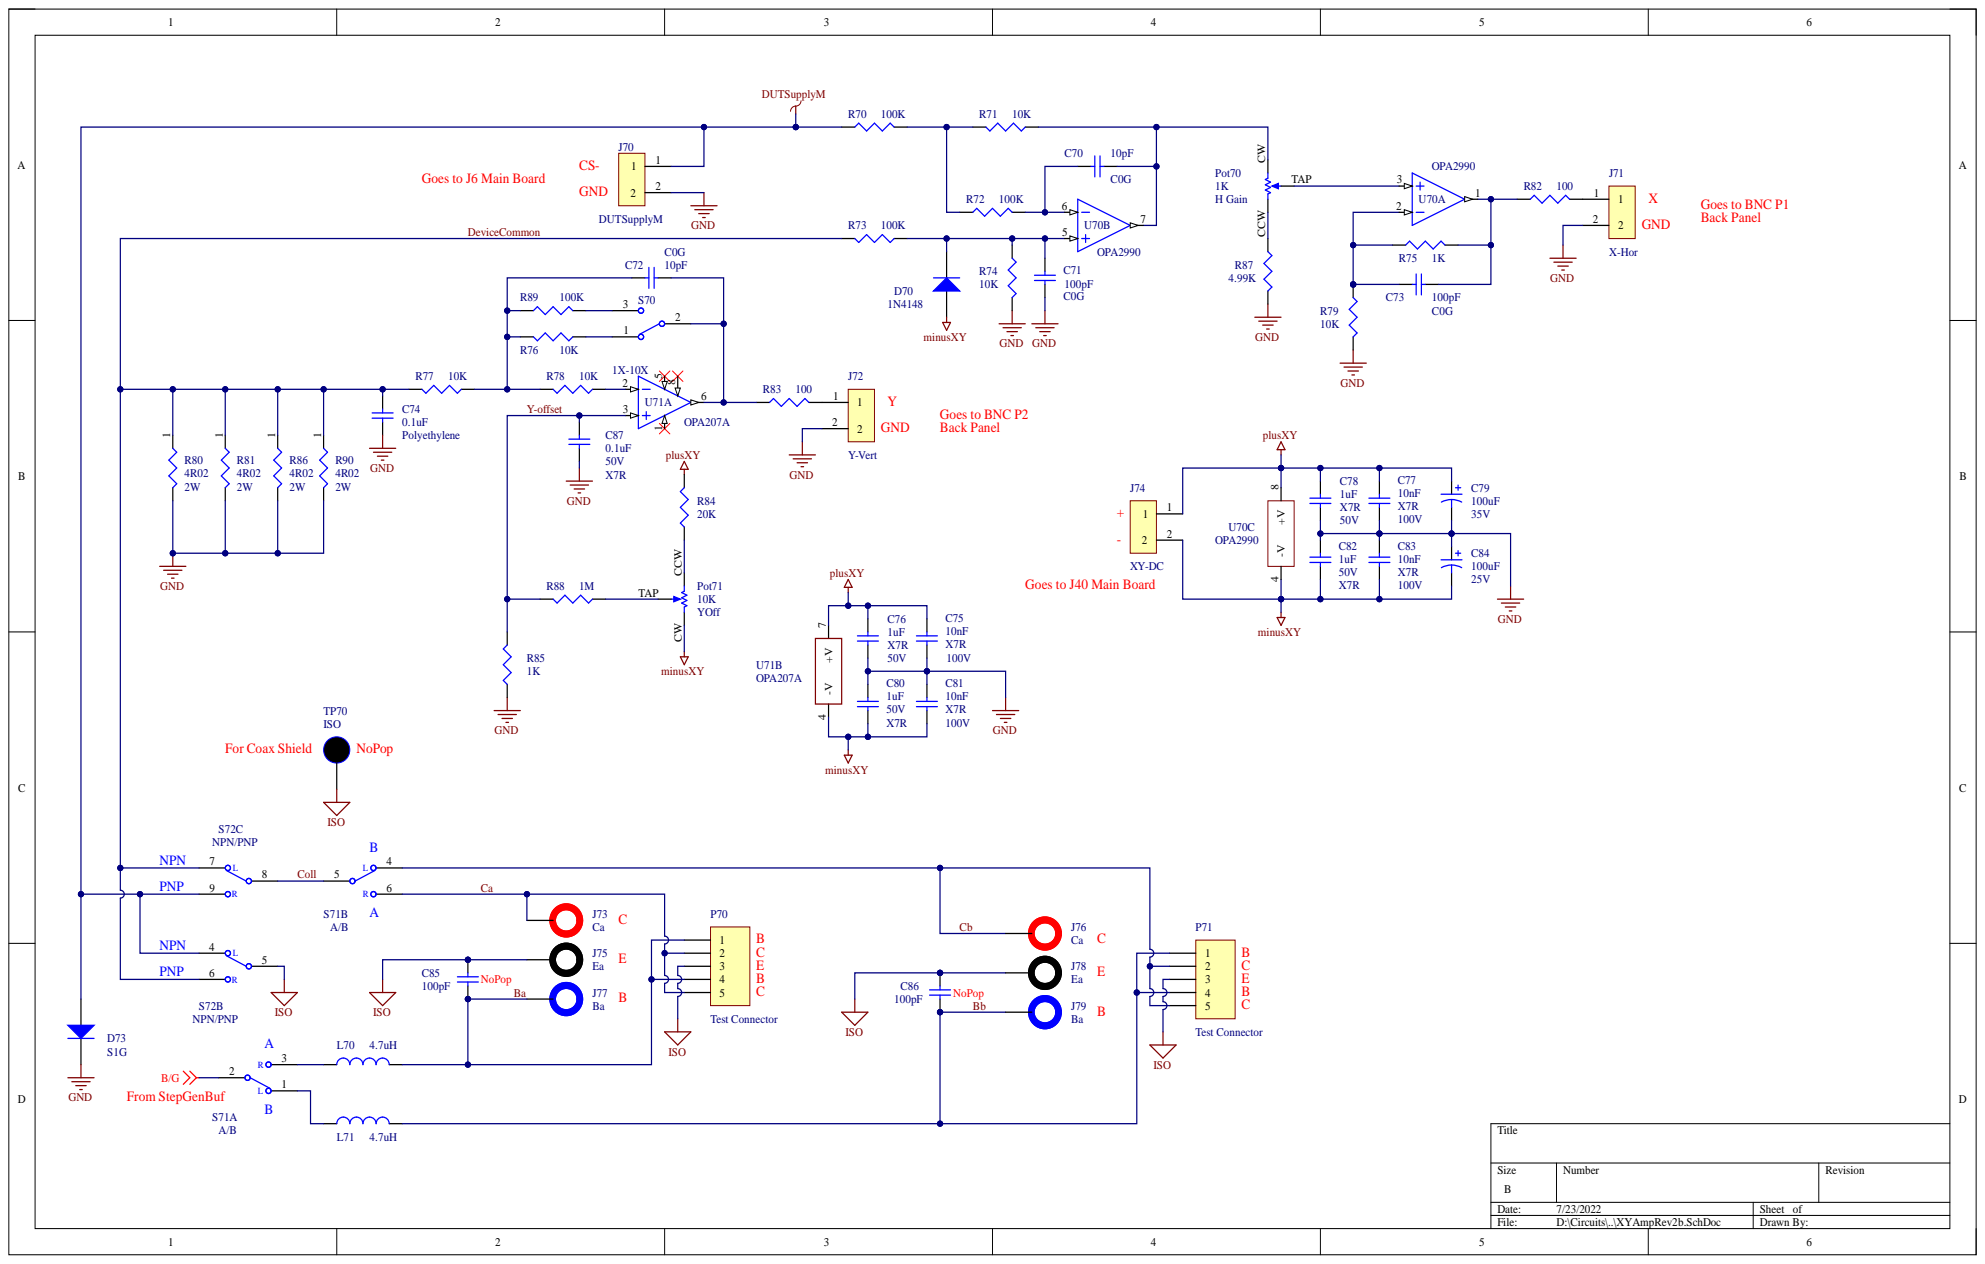
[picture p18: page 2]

Goes to J6 Main Board

Goes to BNC P1 Back Panel

Goes to BNC P2 Back Panel

Goes to J40 Main Board

Size B | Number | Revision

Date: 7/23/2022 | Sheet of
File: D:\Circuits\..\XYAmpRev2b.SchDoc | Drawn By:

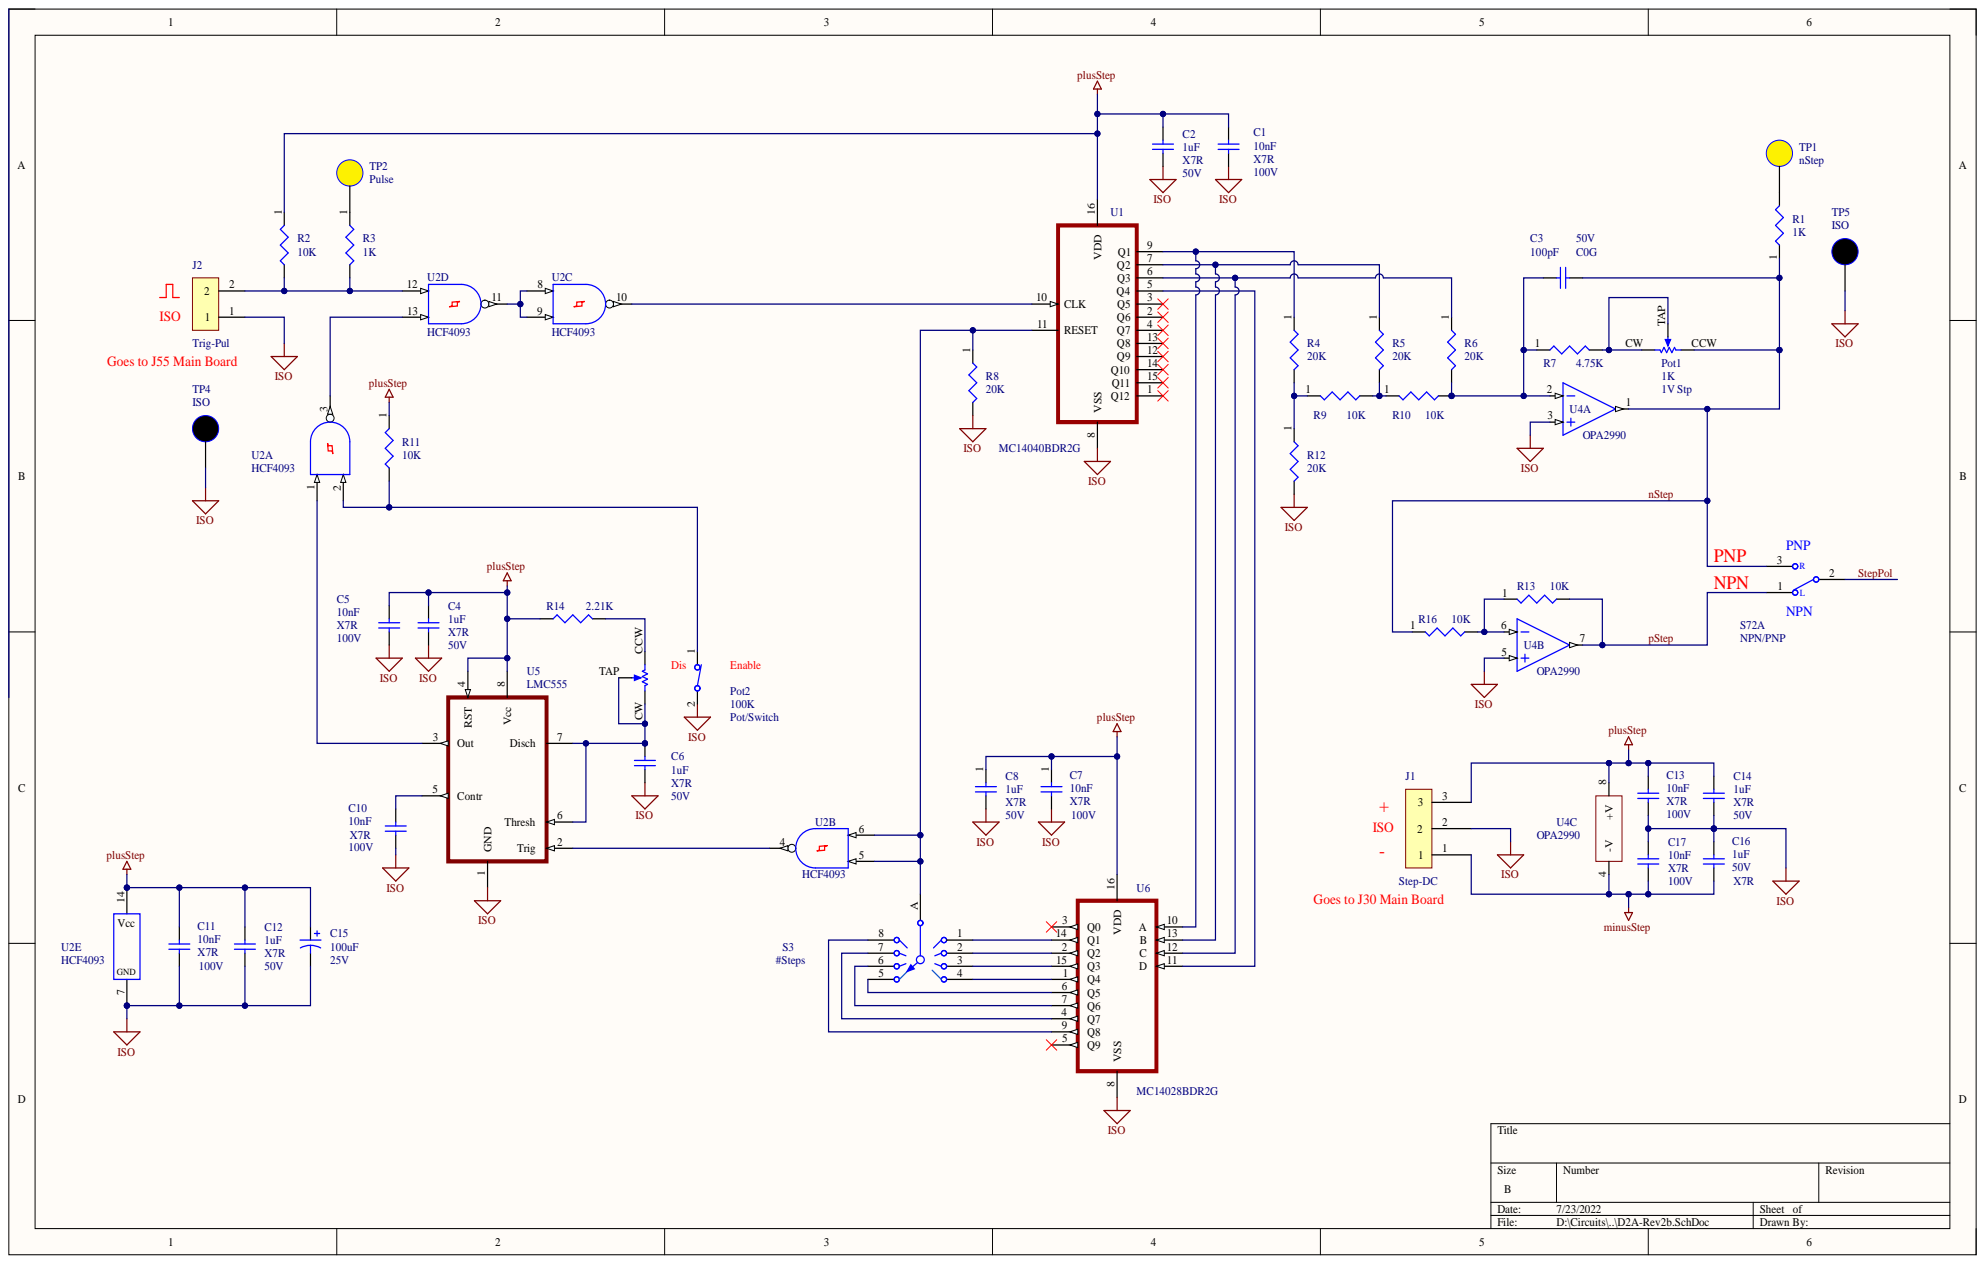
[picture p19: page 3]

2 | | 1 2
1 5 | | 1 1

Size B | Number | Revisio n

Date: 7/2 3/2 0 2 2 | Sheet o f
File: D:\Circuits\..\D2A-Rev 2 b.Sch D o c | Drawn By :

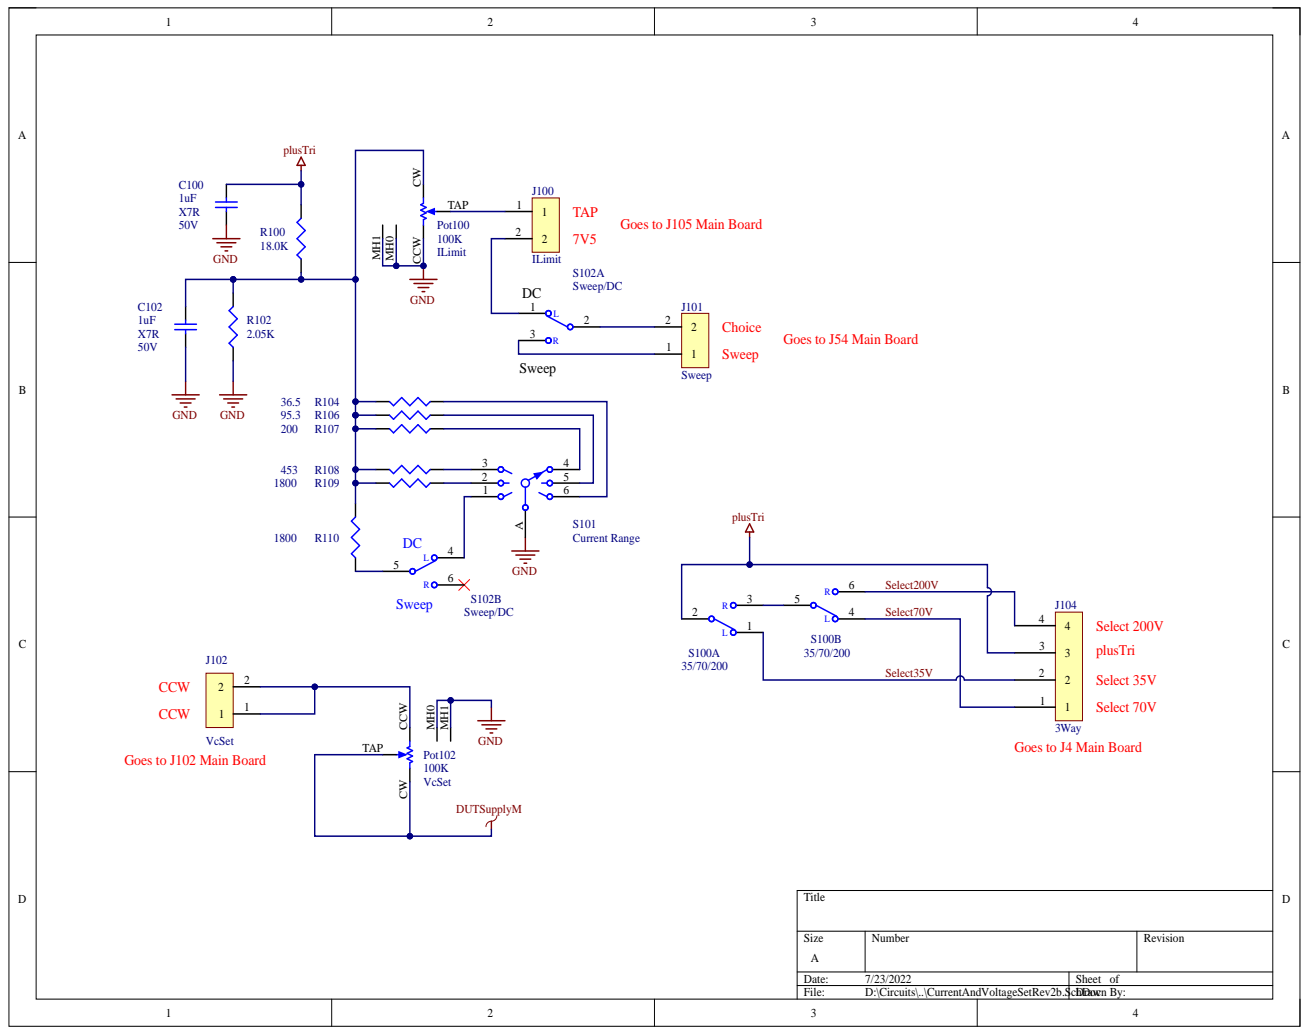
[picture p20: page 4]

Goes to J105 Main Board

Goes to J54 Main Board

Goes to J4 Main Board

Goes to J102 Main Board

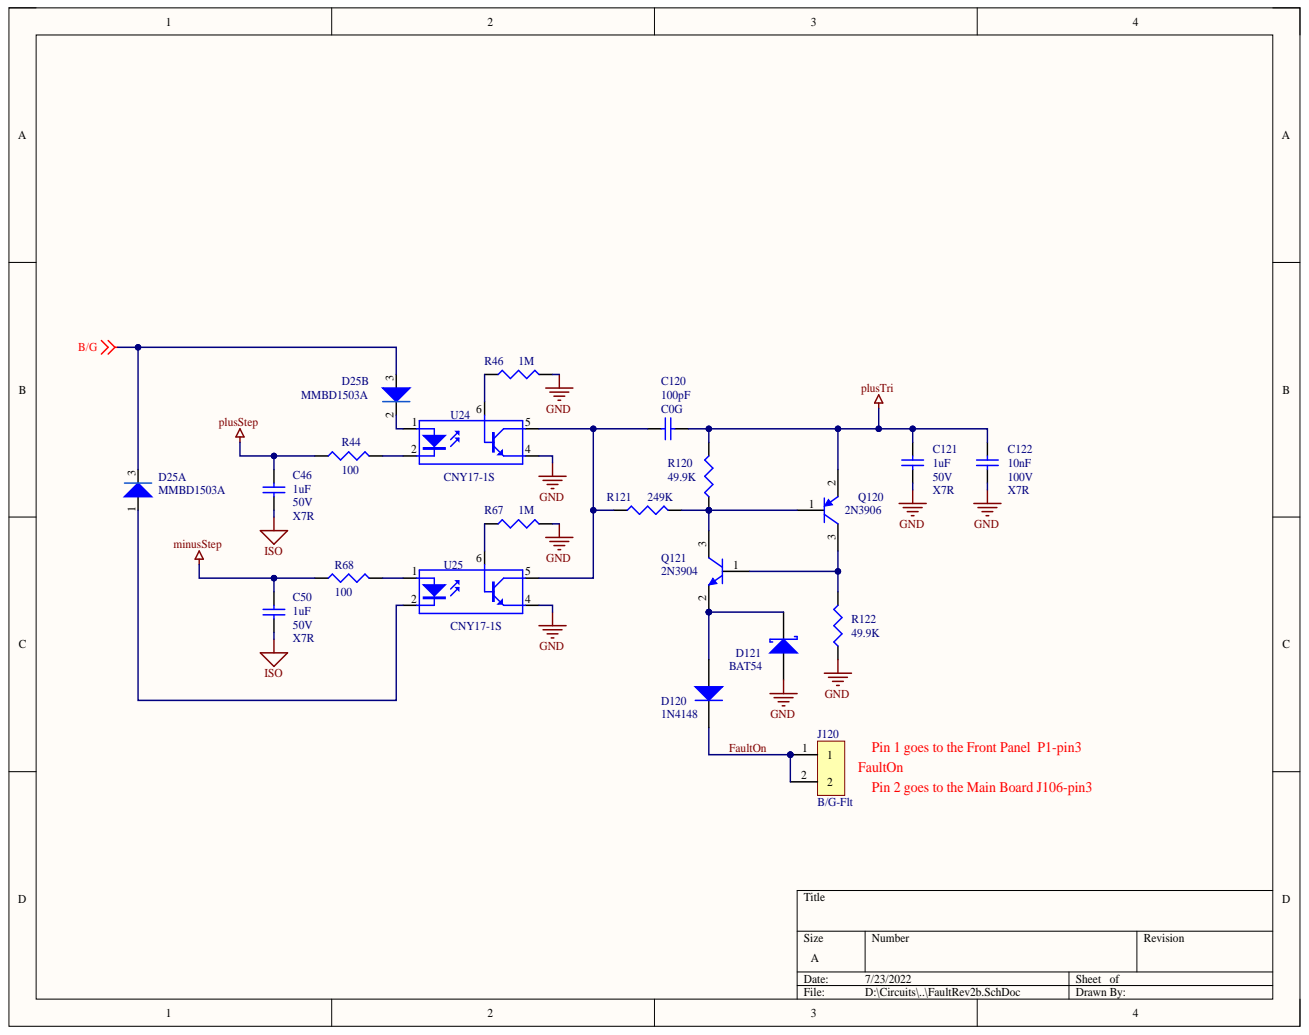
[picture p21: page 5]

Pin 1 goes to the Front Panel P1-pin3

Pin 2 goes to the Main Board J106-pin3

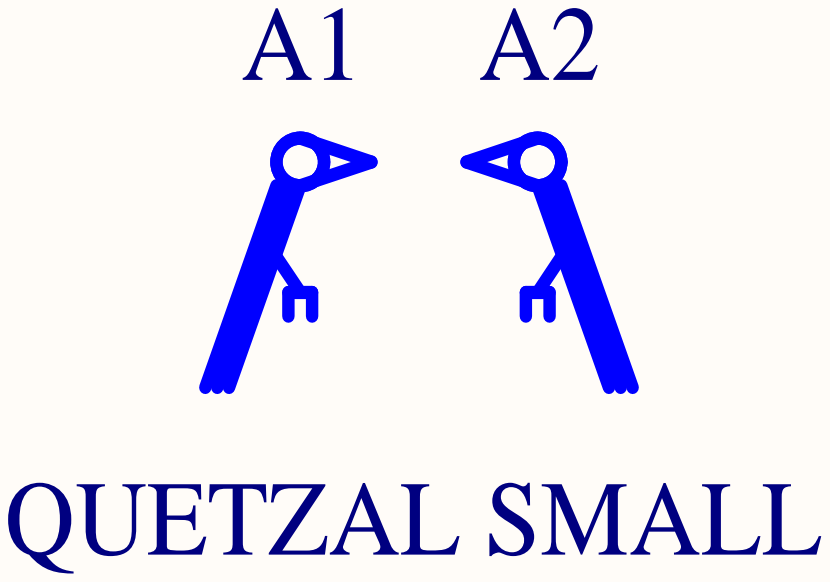
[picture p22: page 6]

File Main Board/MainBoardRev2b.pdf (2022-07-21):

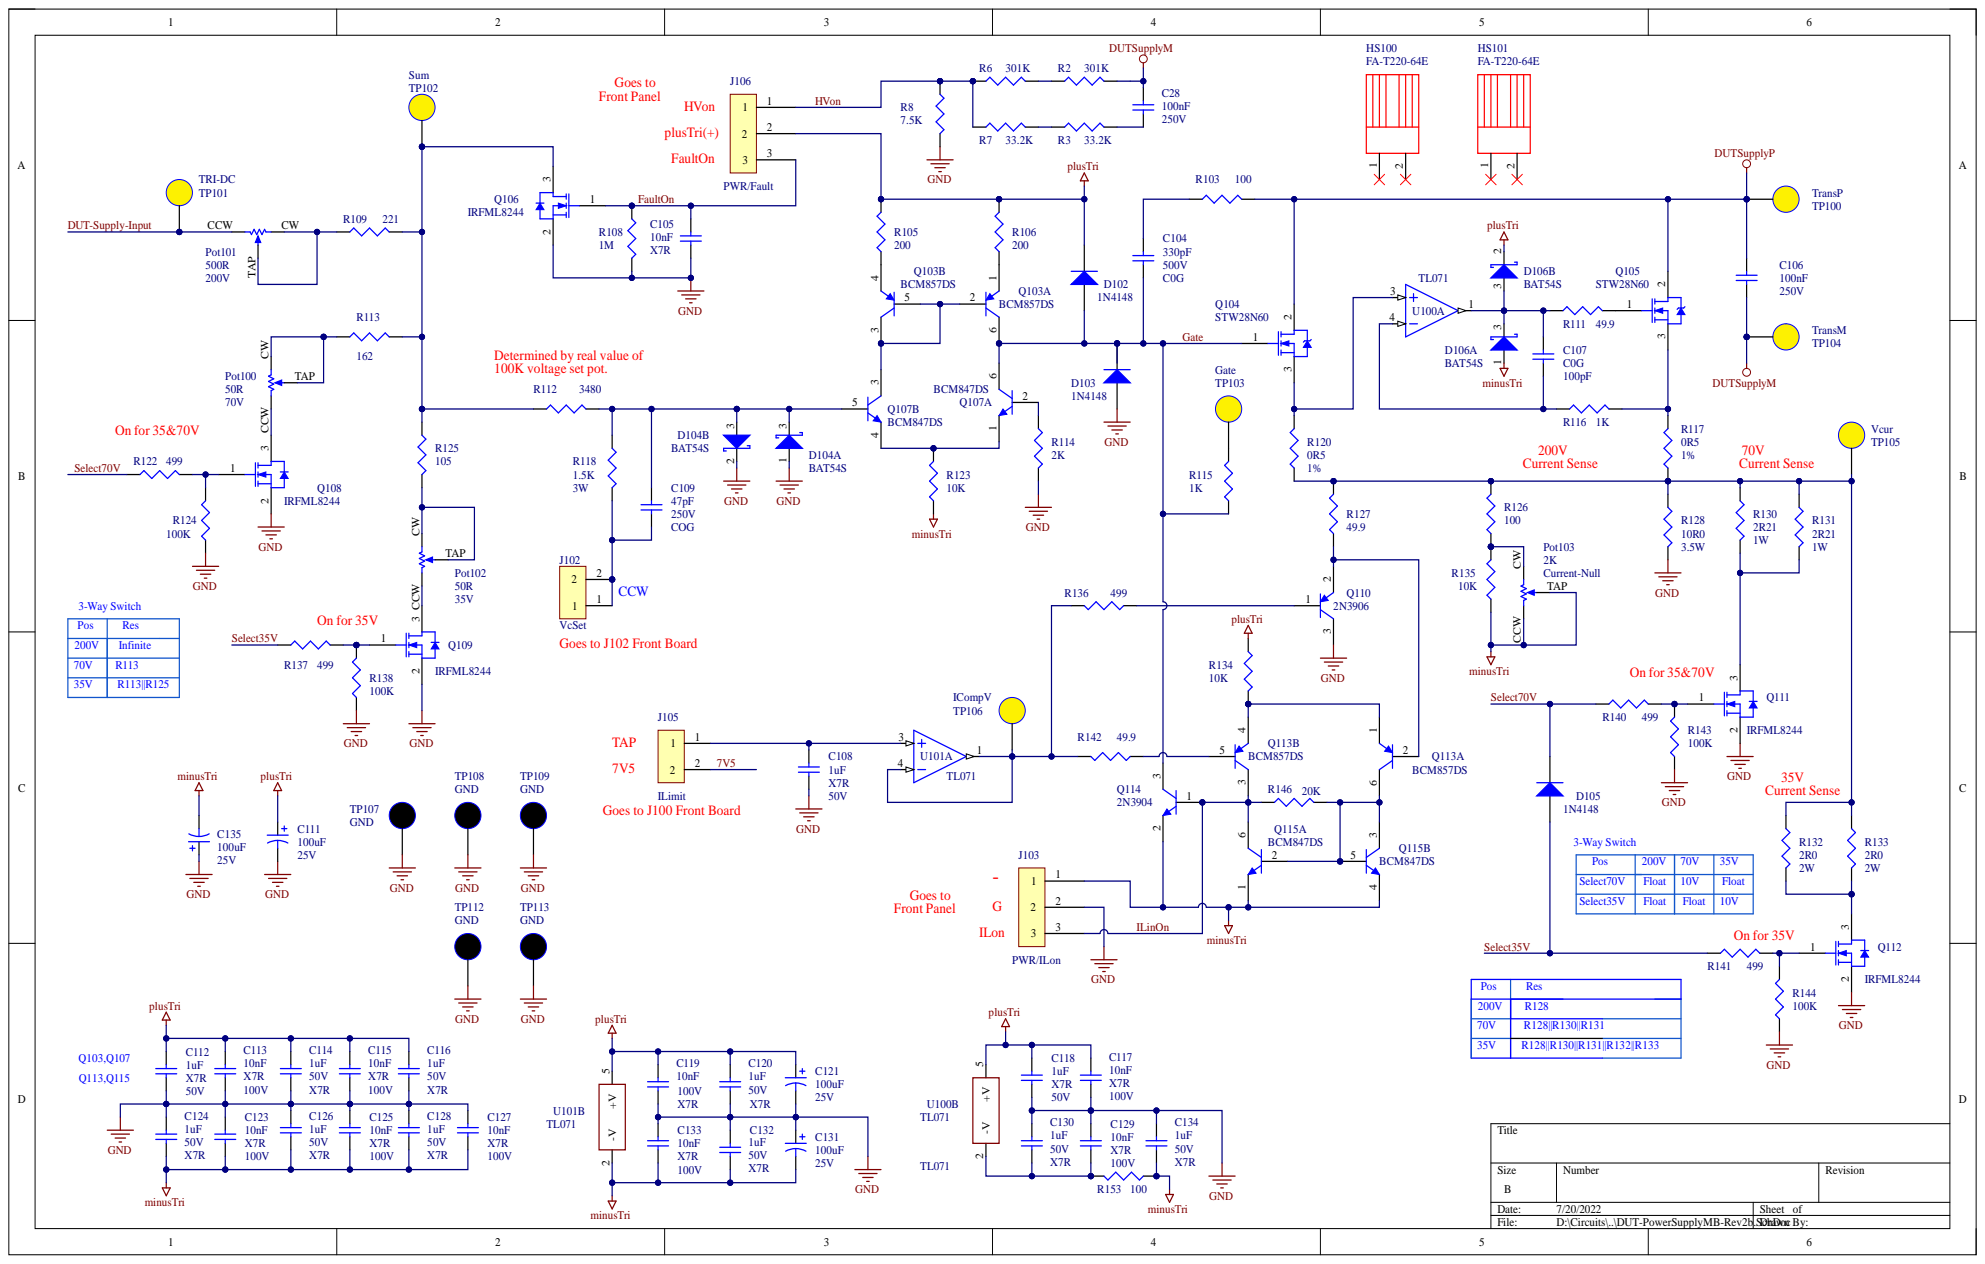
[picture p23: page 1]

Goes to Front Panel

Determined by real value of 100K voltage set pot.

VcSet
Goes to J102 Front Board

Goes to J100 Front Board

Pos | 200V | 70V | 35V

Select35V | Float | Float | 10V

ILinOn

Pos | Res

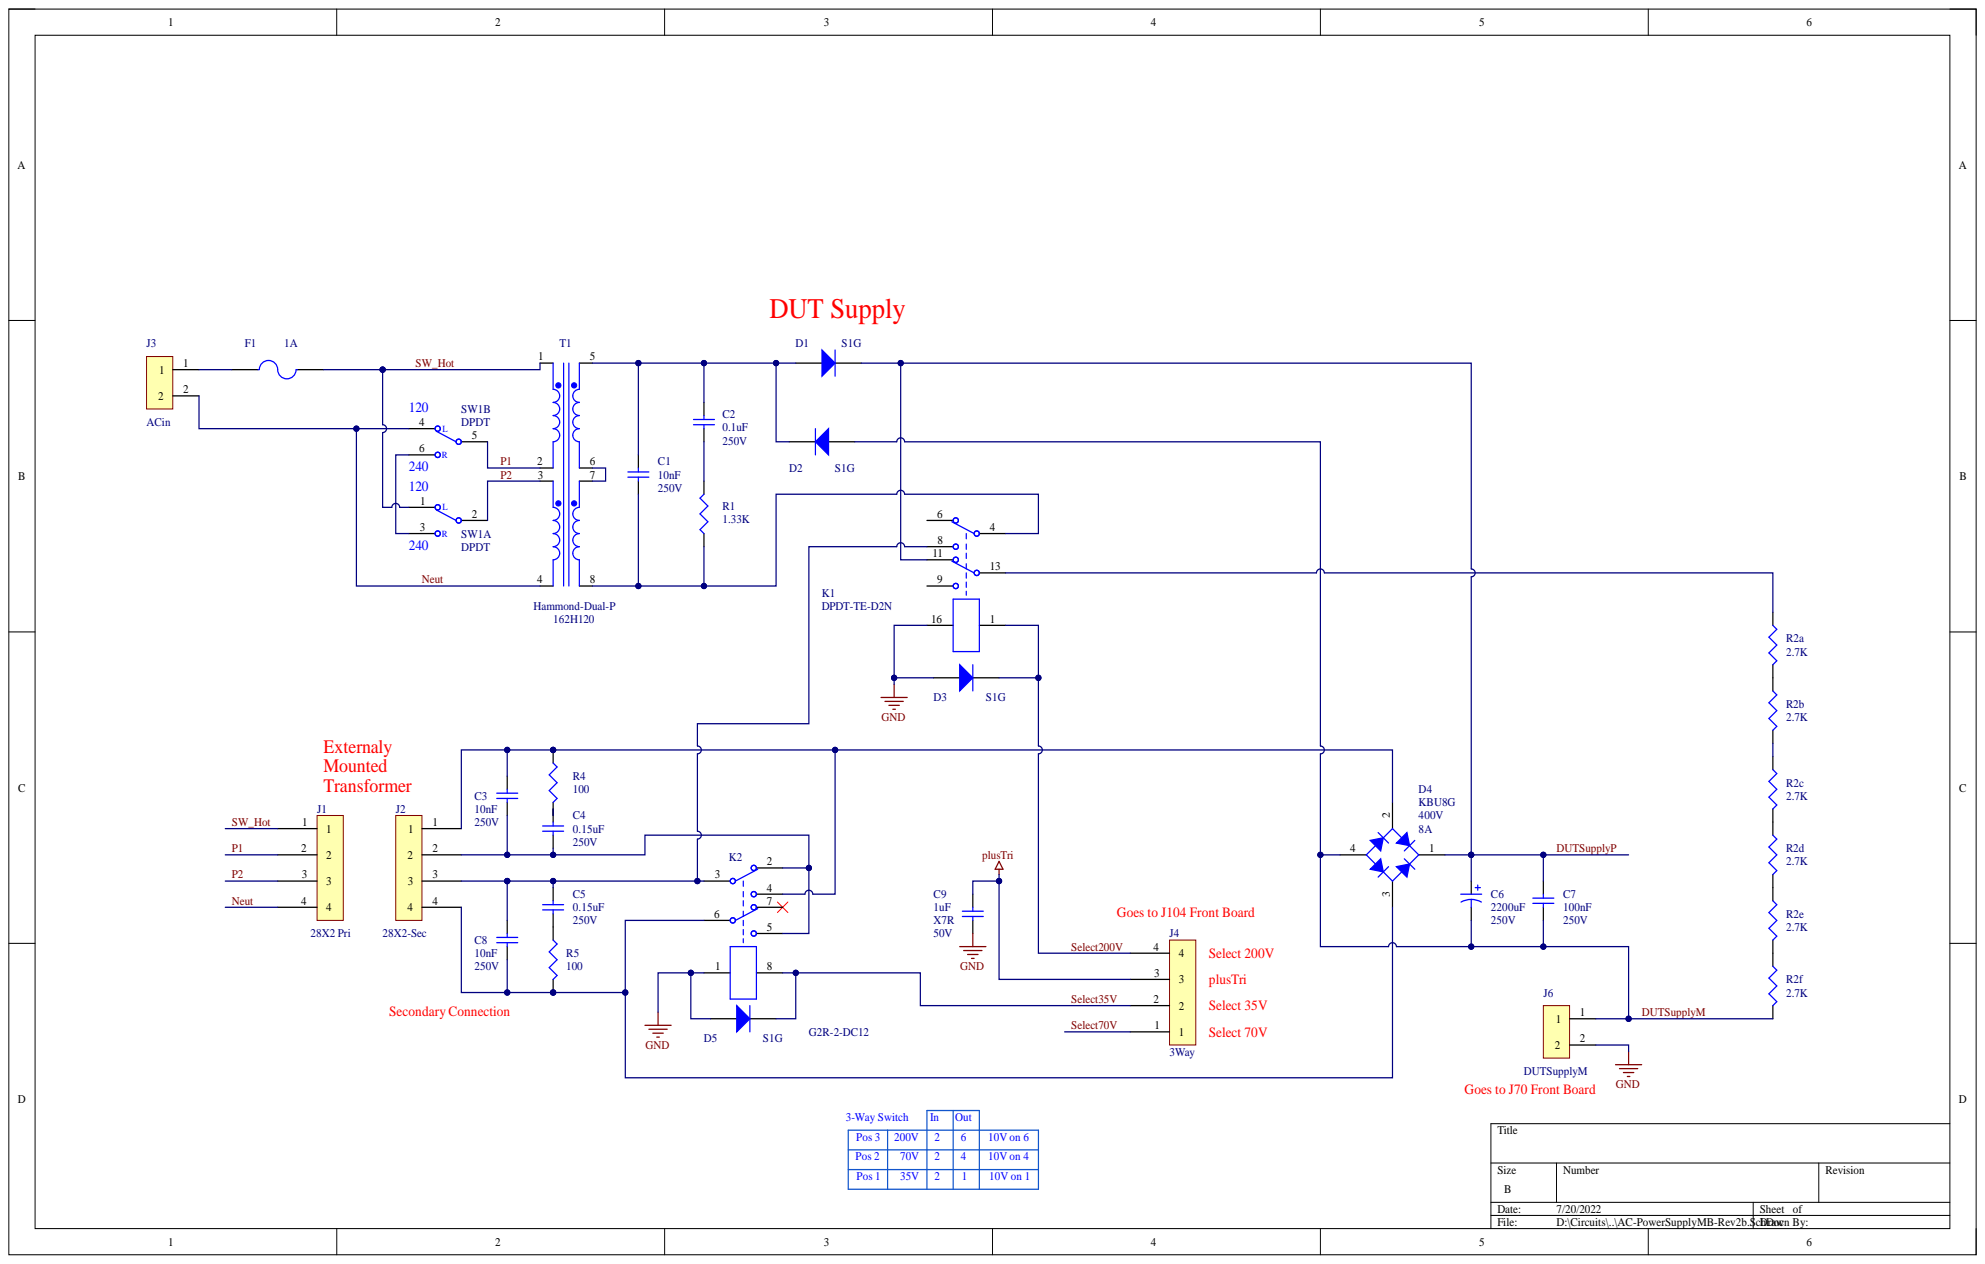
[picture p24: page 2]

C3 10nF 250V | R4 100 0.15uF | plusTri | 4

Goes to J104 Front Board

GND Goes to J70 Front Board

In | Out

Pos 3 | 200V | 2 | 6 | 10V on 6

Pos 2 | 70V | 2 | 4 | 10V on 4

Date: 7/20/2022 | Sheet of
File: D:\Circuits\..\AC-PowerSupplyMB-Rev2b.ScDrawn hDoc By:

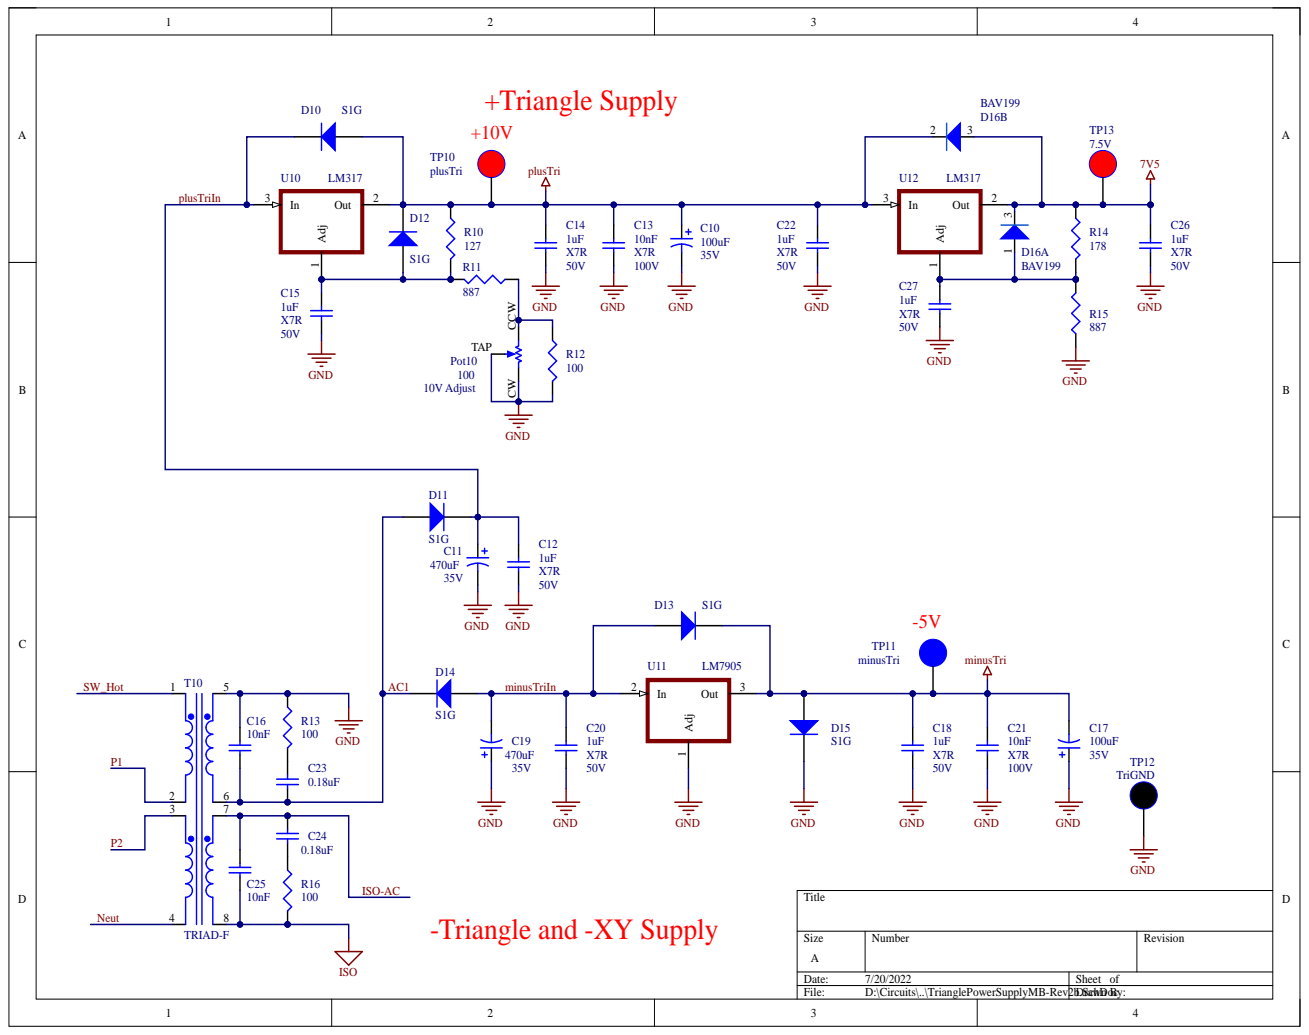
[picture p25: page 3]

ISO-AC
-Triangle and -XY Supply

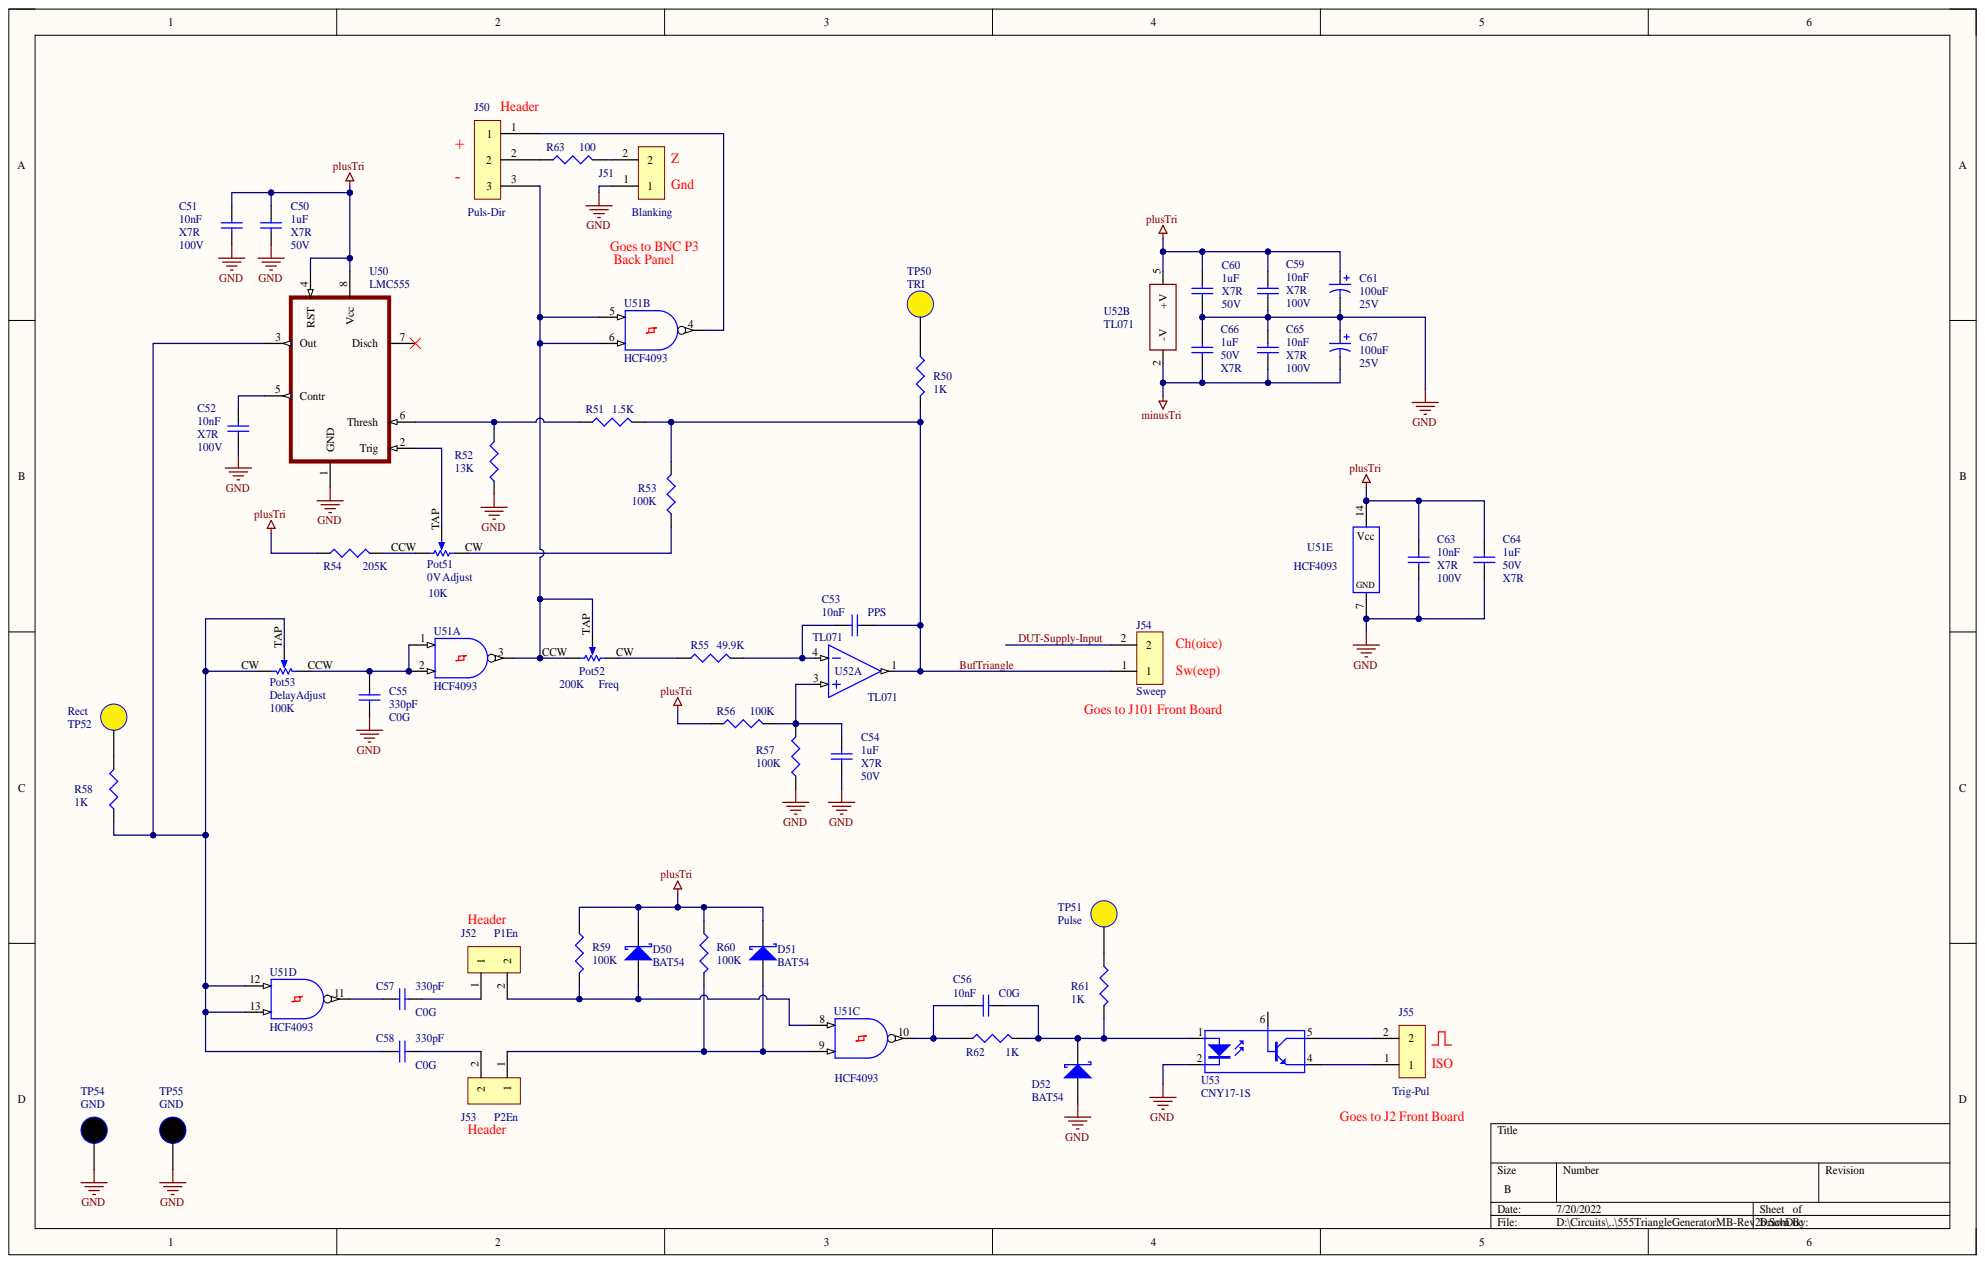
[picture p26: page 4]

GND
Goes to BNC P3 Back Panel

Goes to J101 Front Board

Goes to J2 Front Board

Size B | Number | Revision

Date: 7/20/2022 | Sheet of
File: D:\Circuits\..\555TriangleGeneratorMB-Rev2Drawn b.SchD Byoc :

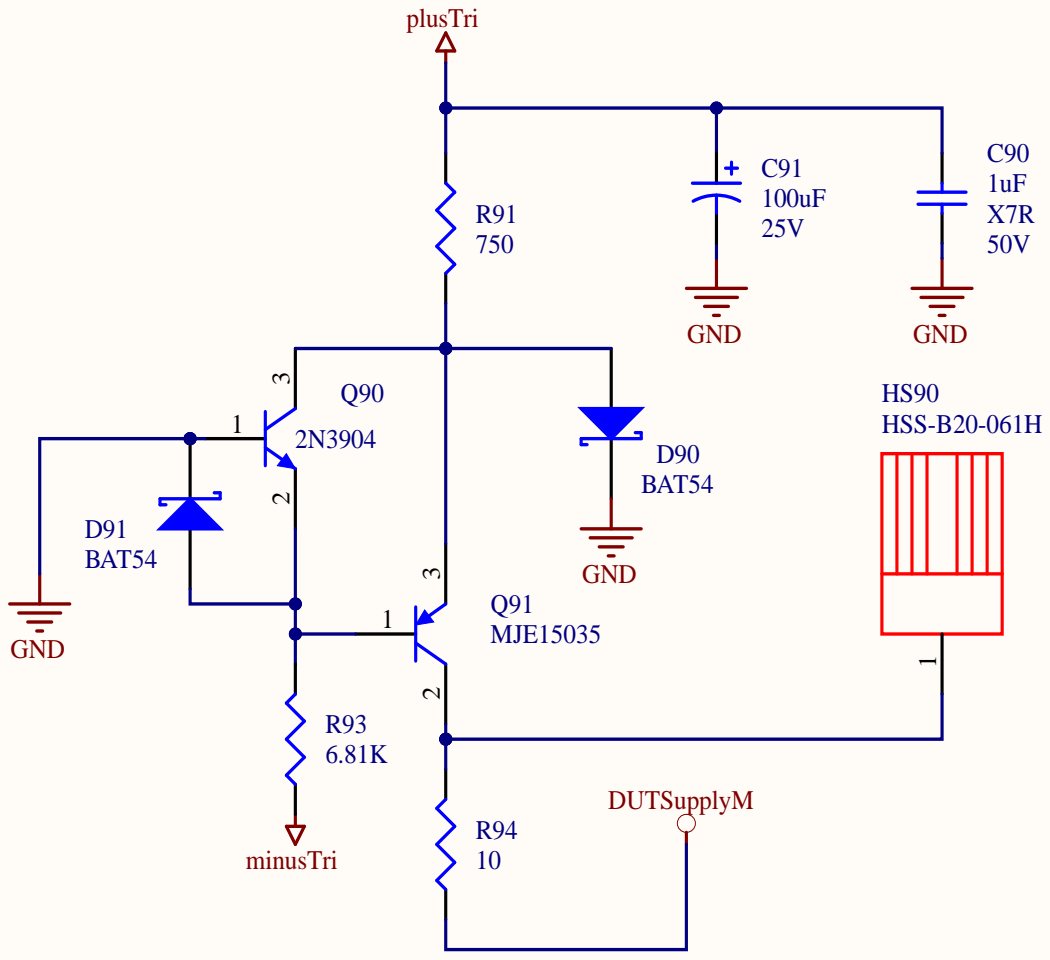
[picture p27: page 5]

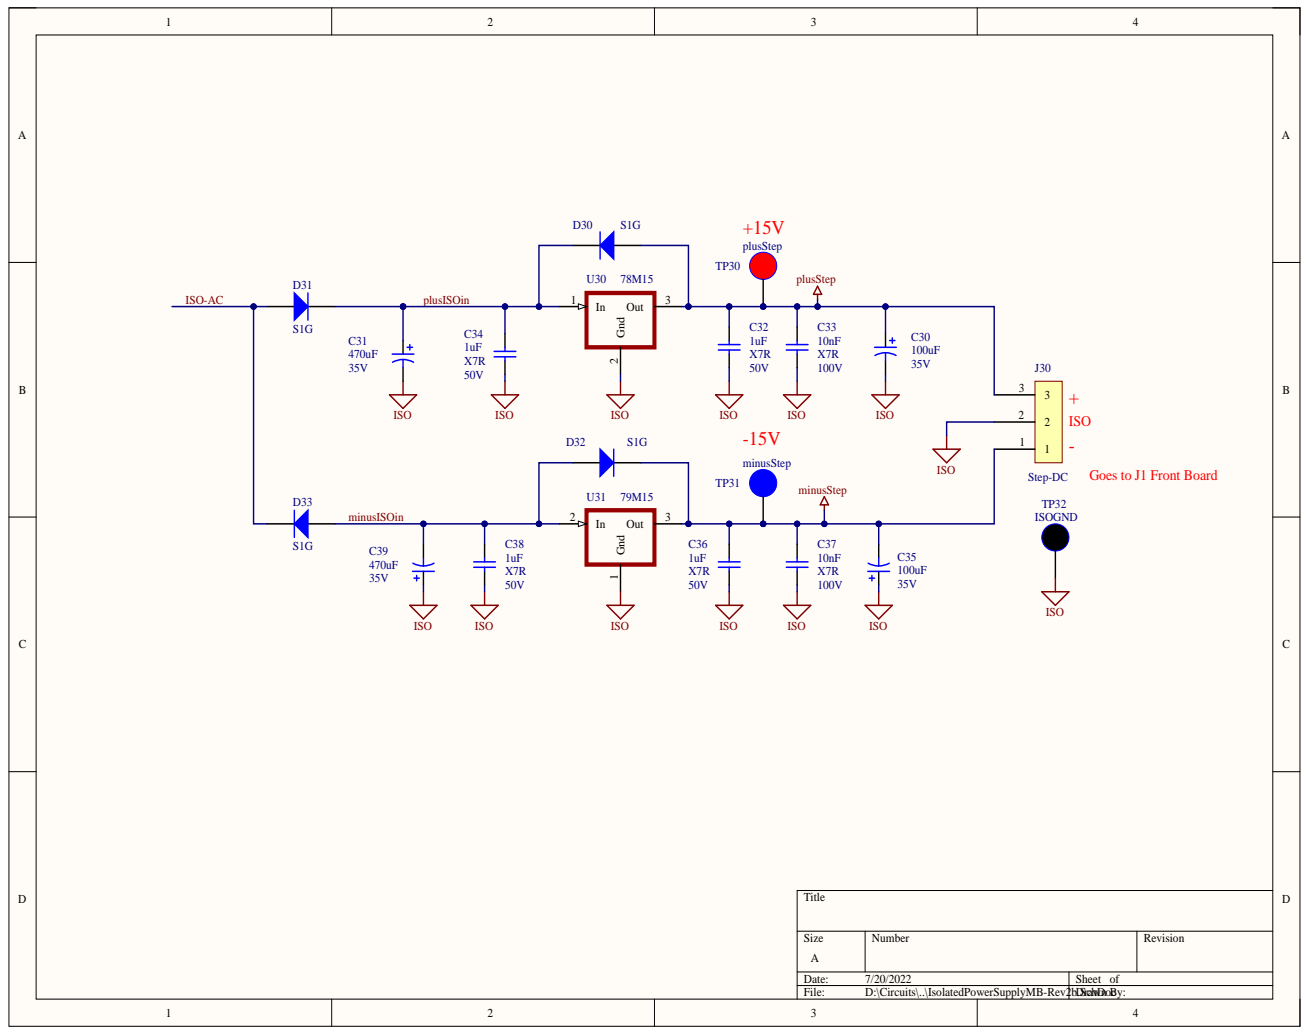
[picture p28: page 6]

Goes to J1 Front Board



Goes to J74 Front Board +-




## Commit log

2022-06-26 Add files via upload
    This is a spreadsheet that Mark created and can be used to calculate the resistor values based on a wanted maximum offset. This allows you to pick resistor combinations of parts you may already have.
    [R34-R35-R38-OffsetCalculations.xlsx]
2025-03-15 Add files via upload
    Added alternatives for obsolete parts
    [BOM-FB-Rev2b.xlsx]
2025-03-20 Add files via upload
    Alternative parts added
    [BOM-FB-Rev2h.xlsx]
2025-03-22 Add files via upload
    Changed pn for part that is no longer available
    [BOM-MB-Rev2f.xlsx]
